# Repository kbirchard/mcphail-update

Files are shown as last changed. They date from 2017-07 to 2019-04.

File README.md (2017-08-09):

# McPhail-Trap

- [Insect Wingbeat Frequencies Table](research/Wingbeat_Frequencies.md)

### Boards

[**Main Board**](hardware/mcphail-main-board/) (incomplete)
- Estimated boards cost $35 for three ($11.68 each)
- Estimated parts cost $50
- Not including the one FONA board and the 2200mAH LiPo we have on hand
- Board is 3.18x2.24 inches (80.82x56.79mm)

[**Emitter Board**](hardware/mcphail-ir-emitter-board/)

- Boards cost $6.85 for three ($2.28 each)
- Parts cost $4.51 for one board
- Board is 2.71x0.51 inches (68.76x12.88mm)

[**Detector Board**](hardware/mcphail-photodiode-detector-board/)

- Boards cost $6.80 for three ($2.27 each)
- Parts cost $15.16 for one board
- Board is 2.71x0.51 inches (68.76x12.88mm)

[**Generic ATSAM21G18 Breakout Board**](https://github.com/wickerbox/Basic-Breakout-Boards/tree/master/atsamd21g18-breakout)

- Boards cost $13.85 for three ($4.62 each)
- Parts cost $14.51 for one board

[**STLink/V2 SWD Adapter Board**](https://github.com/wickerbox/Basic-Breakout-Boards/tree/master/atsamd21g18-jtag-stlinkv2-adapter)

- Boards cost $8.80 for three ($2.93 each)
- Parts cost $2.22 for one board

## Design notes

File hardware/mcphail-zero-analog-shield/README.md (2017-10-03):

# KiCad Template for Arduino Zero Shield 

This is a KiCad template to make it easy to include the Arduino Zero in a project. 

It comes with all the design rules to meet the 2-layer OSH Park specs and stackup.

- <a href="http://docs.oshpark.com/services/two-layer/">OSH Park Two Layer Specs</a>
- <a href="http://docs.oshpark.com/design-tools/kicad">OSH Park KiCad Help</a>
- <a href="https://www.arduino.cc/usa/arduino-zero">Arduino Zero Product Page</a>

### Instructions

1. Open KiCad.
1. Open Preferences > Configure Paths and note the value of 'KICAD_PTEMPLATES'.
1. <a href="https://github.com/wickerbox/wickerlib/blob/master/templates/arduino-zero-shield-template.zip?raw=true">Download the template zip</a> and extract into the location of 'KICAD_PTEMPLATES'.
1. In KiCad, open File > New Project > New Project from Template.
1. Select the location of your new project. The name of the folder will be the name of your project.
1. The templates with folders in the 'KICAD_PTEMPLATES' are listed under 'Portable Templates" tab.
1. Select the template and click 'OK'.
1. Your project now exists, so you can open EESchema and PCBNew and design as usual.

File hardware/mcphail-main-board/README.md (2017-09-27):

<!--- start title --->
# McPhail Trap Main Board v1.1
Collect, analyze, and report back environmental data.

- Updated: 12 Aug 2017
- Author: Jenner Hanni
- Website: http://wickerbox.net
- Company: Wickerbox Electronics
- License: CERN Open Hardware License v1.2
<!--- end title --->

This is an attempt to reproduce the work of identifying fruit flies from the following papers:

- 2017: [Automated Surveillance of Fruit Flies](http://www.mdpi.com/1424-8220/17/1/110/pdf)
- 2015: [Insect Biometrics: Optoacoustic Signal Processing and its Applications to Remote Monitoring](http://www.ncbi.nlm.nih.gov/pmc/articles/PMC4636391/)
- 2014: [The Electronic McPhail Trap](http://www.mdpi.com/1424-8220/14/12/22285) 
- 1979: [Optical Tachometer for Measurement of Wingbeat Frequency of Free-Flying Insects](http://jeb.biologists.org/content/82/1/377)

Parallels the European [ENTOMATIC](https://www.upf.edu/web/entomatic/) project.

## Hardware Version Notes

- v1.x, proof of concept, collect data on SD card and over USB
  Fona breakout board supports texting
- v2.x, switch to ARM MSP430 or other ADC-specific chip, collect data on SD card
- v3.x, integrate mesh net or other networking, possibly more sophisticated offboard analysis

\pagebreak

## Design Notes

### Physical Housing

Putting the electronics in acrylic separate from the insects so the ultrasonic isn't bothering them. An acrylic housing placed on top of the trap provides protection from the elements as well as protects the insects from any electronics noise. 

If all circuitry is on the board at the top, the IR emitters and photodiode detectors can be the only items in the trap with the insects and be connected by a minimum of cabling. 

The boards will all be 0.063" (1.6mm) thick FR-4 with purple solder mask over bare copper and an ENIG (gold) finish.

The tallest component on the board is C1 (330uF aluminum capacitor) at 0.5" tall.

**Board dimensions**

|Board|Dimensions|
|-----|---|
|Emitter Board|2.71x0.51 inches (68.76x12.88mm)|
|Detector Board|2.71x0.51 inches (68.76x12.88mm)|
|Main Board|3.18x2.24 inches (80.82x56.79mm)|

### Security and Connectivity Platforms for reference

- Particle
- Electric Imp

### v1 FONA808 GSM+GPS MODULE

- PS is power status. Check this after toggling KEY.
   Pin is low when module is off, and high when module is on.

- NS is network status. It pulses to signal current module status

- RST is hard reset to be used only when module is really stuck.

- RX/TX are pins capable of Software Serial. They are auto-baud so
   whatever baud you send "AT" after reset or boot is the baud rate
   the module will use. 

- RTS is hardware flow control. Optional.
   Turn it on in module if you want to use it. 

- RI is the ring indicator output. Use it as an interrupt. Default high.
   Pin will pulse low for 120ms when a call or SMS is received. 

The GPS is accessible on the Rx/Tx lines so you can query
using AT commands and get the values back. No additional
pins are necessary.

### Microcontroller

The reference papers call for a 14-bit ADC.

The Atmel AVR chips we initially considered (Atmega32u4, Atmega2560) had 10-bit ADC, which isn't enough. We chose the ATSAMD21G Cortex M0 with 12-bit ADC since it still can be programmed with a cheap programmer, doesn't require dedicated hardware, has built-in USB for programming and monitoring.

It is compatible with [adalink](https://github.com/adafruit/Adafruit_Adalink) and [avrdude](http://www.nongnu.org/avrdude/), which we already use for programming other boards. 

We added a $6 16-bit ADS1115 which receives on two differential or four single channels (we could use the four) and outputs the result over I2C.
 
Another possible solution would have been the $6 MSP432 or a similar chip, could pick up a $14 dev board as well. This is a TI chip that requires CodeComposer Studio, newest version is CCSv6. It's Linux-compatible and I have a Windows machine just in case it's not.

The downside of the MSP432 is the $45 additional programmer we need to buy, getting set up with a new dev environment, etc.  

### ADC and Noise Notes

The 2-layer board is routed using a split ground plane to separate the analog and digital signals. Care was taken to provide clear analog return paths but the A0, A1, and A2 signals right at the microcontroller are next to the I2C signals and this may end up as a source of noise. 

If noise is still an issue, we may need need a 4-layer board (which doubles board cost). It's unclear if ENTOMATIC are actually getting and using all 14 bits. 

Does 5V in the ENTOMATIC system vs 3.3V in our system make a difference? How?

We need to review the ENTOMATIC calculations -- seems like my back-of-envelope has 32ms, not 16ms as from their paper.

For power and noise control, we should turn off everything but the ADC when sampling. 

[Discussion of cheap 16-bit ADC](http://www.avrfreaks.net/forum/cheap-16-bit-adc)

### Software Approach

We collect the value from the ADC in a variable and poll it at the desired rate. 

Architecture could be a finite state machine.

Next step is to go through and set up all the registers first to initialize serial comms, ADC, RTC, low power mode, the interrupts, and so on. Then, make sure we have libraries for accessing the SD, etc. This will not be an Arduino project, but an AVR GCC project. Need to get the environment set up and document it so someone else can reproduce the work in the same way we did.

### RTC

The DS1307 real time clock is out of date and hard to find.

We used the MCP7940N with an external 32.768kHz external crystal, following the suggested PCB layout on [page 14 of the datasheet](http://ww1.microchip.com/downloads/en/DeviceDoc/20005010F.pdf).

There is a discussion of digital trimming on page 29 to mitigate temperature and intrinsic clock issues. We can figure out the values in this digital trimming register by testing the physical board and calculating the the trim value with the equations on paeg 30. 

### Temperature

Kyle put a thermometer in the trap and measured the temperature inside over two days in direct sunlight. Both times the internal temp was 10 F degrees higher than the ambient air temp. (110/100F first day @ 5pm, 108/98F second day @ noon). 

Prior to measuring, he left the thermometer in the trap for an hour, so that should be a reflection of what we'd see in the field. The combination of size and materials is keeping the temperature from getting much higher.

### Capacitors

Mostly ceramic capacitors were chosen for cost and size, with C0G/NP0 and X7R temperature coefficients. Aluminum electrolytic capacitors were chosen where ceramics were cost-prohibitive or where specifically indicated in datasheets.

The temperature coefficients: 

X7R means a capacitor is a temperature-stable (EIA Class 2) cap which only varies up to ±15% from -55°C to +125°C.  [ref](http://www.avx.com/products/ceramic-capacitors/surface-mount/x7r-dielectric/)

C0G/NP0 means a capacitor is temperature-compensating (EIA Class 1) which varies less than ±0.3% C from -55°C to +125°C. Capacitance drift or hysteresis is less than ±0.05%. [ref](http://www.avx.com/products/ceramic-capacitors/surface-mount/c0g-np0-dielectric/)

## Detector/Receiver Board

Interestingly, the receiver part number [TEMD5080X01](https://www.digikey.com/product-detail/en/vishay-semiconductor-opto-division/TEMD5080X01/TEMD5080X01CT-ND/2747443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) does not have the same package as in the photos of the McPhail trap. These are $1.31 each at 25 and the design calls for ten of them. 

They are good from -40C to 100C and are 5mm x 4.24mm. 

The board is 2.71x0.51 inches (68.76x12.88mm) and costs $7 from OSH Park for a set of three ($2.33 each). 

The stencil costs $5 from OSH Stencils.

## Emitter Board

The 940nm emitters are in the $2 range and the board will probably be the same size as the detector board. 

The difference in frequency range is due to the ENTOMATIC folks optimizing for response time over exact frequency match, to save on power. They also drove the LEDs at the edge of the board at higher current to make sure the infrared intensity was uniform no matter where the bug flew through the IR field. 
 
The diffuser needs more investigation.

The board is 2.71x0.51 inches (68.76x12.88mm) and costs $7 from OSH Park ($2.33 each).

The stencil costs $5 from OSH Stencils.

\pagebreak

## ATSAMD21G Pins

|ATSAMD21G Pin|Function|
|25|D7 CS|
|40|~RESET|
|14|SCLK|
|19|MOSI|
|15|MISO|
|13|D4 CS|
|33|D-|
|34|D+|
|26|FONA_NS|
|27|FONA_PS|
|28|FONA_RI|
|29|FONA_RTS|
|30|FONA_TX|
|31|FONA_RX|
|32|FONA_RST|
|41|~PG|
|20|RTC_MFP|
|21|SDA|
|22|SCL|
|37|EEPROM_ADD2|
|38|EEPROM_ADD1|
|39|EEPROM_ADD0|
|10|A2|
|11|A1|
|12|A0|
|45|SWCLK|
|46|SWDIO|

<!--- assy start --->
## Complete Assembly and Cost Information

Buying parts for a single main board is about $50. 

Buying parts for three main boardS (minimum OS Park order) is about $100.

The stencil from OSH Stencils costs $12.09. A tube of solder paste in the same package costs $14. 

Stencils are 3mil-thick polyamide (orange) film which is reusable.

Total cost for one complete stack (three boards): $143 ($143/stack)

Total cost for three complete stacks (nine boards): $223 ($74/stack)

Subsequent complete three stacks with parts: $200 ($67/stack)

|Item|Cost|
|----|----|
|Emitter Board PCB each (min qty=3)|$2.30|
|Emitter Parts qty=1|$4.50|
|Emitter Parts qty=3|$13.50|
|Emitter Stencil|$5|
|Detector Board PCB each (min qty=3)|$2.30|
|Detector Parts qty=1|$15|
|Detector Parts qty=3|$35|
|Detector Stencil|$5|
|Main Board PCB each (min qty=3)|$12|
|Main Board Parts qty=1|$50|
|Main Board Parts qty=3|$100|
|Main Board Stencil|$12|
|Leaded Solder|$14|

<!--- assy end --->
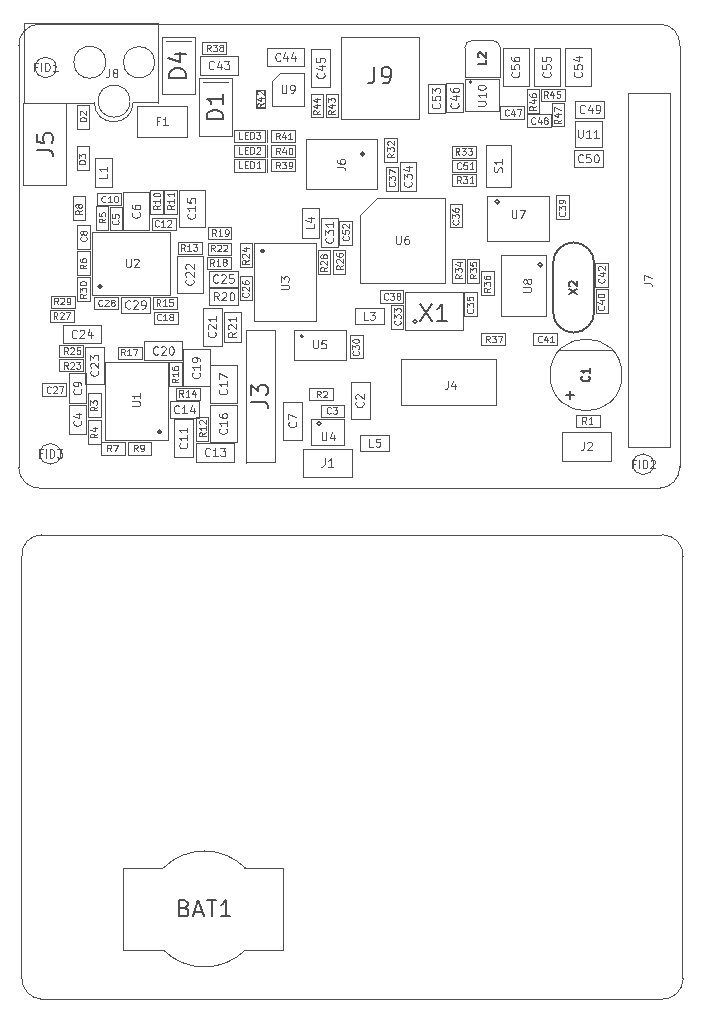
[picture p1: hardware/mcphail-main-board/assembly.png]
Assembly Diagram


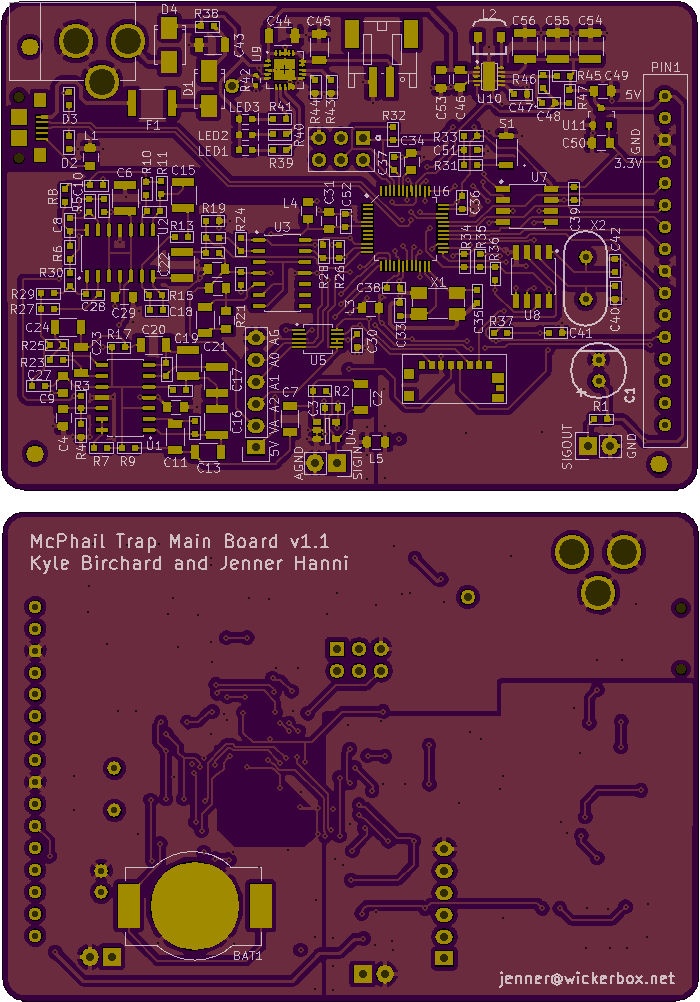
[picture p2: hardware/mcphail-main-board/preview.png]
Gerber Preview


\pagebreak

<!--- bom start --->
### Bill of Materials

|Ref|Qty|Description|Digikey PN|
|---|---|---|---|
|BAT1|1|CR1220 BATTERY HOLDER SMT FLATPIN|BK-916-CT-ND|
|C1|1|CAP ALUM 330UF 20% 16V RADIAL|732-8798-1-ND|
|C10|1|CAP CER 0.27UF 16V X7R 0603|490-6427-1-ND|
|C11 C13 C2 C7|4|CAP CER 1.5UF 25V X7R 1206|1276-6873-1-ND|
|C12 C28 C8|3|CAP CER 0.01UF 50V X7R 0603|490-1512-1-ND|
|C14 C29 C34 C4 C49-50 C9|7|CAP CER 1UF 25V X7R 0805|1276-1066-1-ND|
|C15 C54-C56 C6|5|CAP CER 22UF 25V X7R 1210|1276-3392-1-ND|
|C16 C17 C19 C22|4|CAP CER 2.2UF 25V X7R 0805|1276-2953-1-ND|
|C18|1|CAP CER 33PF 16V X7R 0603|478-6211-1-ND|
|C20-21 C23-24 C43-C45|7|CAP CER 4.7UF 50V X7R 1206|1276-2789-1-ND|
|C25 C31 C46 C53|4|CAP CER 10UF 16V X7R 0805|1276-2872-1-ND|
|C26 C30 C36-C39 C47 C51 C52|9|CAP CER 0.1UF 100V X7R 0603|490-3285-1-ND|
|C27|1|CAP CER 0.022UF 50V X7R 0603|1276-2004-1-ND|
|C3|1|CAP CER 0.22UF 25V X7R 0603|1276-1111-1-ND|
|C33 C35|2|CAP CER 22pF 50V NP0 0603|399-9031-1-ND|
|C40 C42|2|CAP CER 2PF 50V C0G/NP0 0603|490-10713-1-ND|
|C41|1|CAP CER 100PF 50V C0G/NP0 0603|490-1427-1-ND|
|C48|1|CAP CER 10PF 50V NP0 0603|1276-2154-1-ND|
|C5|1|CAP CER 0.039UF 50V X7R 0603|1276-2056-1-ND|
|D1 D4|2|DIODE SCHOTTKY 20V 1A SMA|SS12-E3/61TGICT-ND|
|D2 D3|2|VARISTOR ESD PROTECT USB|CG0603MLC-05ECT-ND|
|F1|1|RESETTABLE FUSE 500mA 15V MF-MSMF|MF-MSMF050-2CT-ND|
|J1 J2|2|HEADER MALE 2POS TH 1x02 0.1IN|952-2262-ND|
|J3|1|HEADER MALE 6POS KK100 0.1IN SHROUD TH|WM4204-ND |
|J4|1|CONN MICRO SD CARD PUSH-PULL|WM9731CT-ND|
|J5|1|USB MICRO-B RECEPTACLE 5PIN SMT R/A STUDS|609-4616-1-ND|
|J6|1|HEADER FEMALE 6POS 2x3 0.1IN|A30729CT-ND|
|J8|1|CONN PWR JACK 2.5X5.5MM HIGH CUR|PJ-202BH|
|J9|1|CONN HEADER PH SIDE 2POS 2MM|455-1719-ND|
|L1 L3-L5|4|FERRITE BEAD 30 OHM 0805 1LN|MH2029-300YCT-ND|
|L2|1|FIXED IND 1UH 3.3A 1226AS-H-1R0N|490-14149-1-ND|
|LED1-3|3|LED AMBER DIFFUSED 0603 SMD|475-2712-1-ND|
|R1|1|RES SMD 220 OHM 5% 1/10W 0603|311-220GRCT-ND|
|R10|1|RES SMD 732 OHM 1% 1/10W 0603|P732HCT-ND|
|R11 R8|2|RES SMD 1.43K OHM 1% 1/10W 0603|P1.43KHCT-ND|
|R12 R16 R23|3|RES SMD 2.26K OHM 1% 1/10W 0603|311-2.26KHRCT-ND|
|R13 R33 R36|3|RES SMD 10K OHM 1% 1/8W 0603|RNCP0603FTD10K0CT-ND|
|R14 R39-R41|4|RES SMD 470 OHM 5% 1/4W 0603|RHM470DCT-ND|
|R15|1|RES SMD 97.6K OHM 1% 1/10W 0603|P97.6KHCT-ND|
|R17|1|RES SMD 68 OHM 1% 1/10W 0603|P68.0HCT-ND|
|R18 R19|2|RES SMD 91K OHM 1% 1/10W 0603|P91.0KHCT-ND|
|R2|1|RES SMD 64.9K OHM 1% 1/10W 0603|P64.9KHCT-ND|
|R20 R21|2|RES SMD 220K OHM 5% 1/8W 0805|P220KACT-ND|
|R22 R26|2|RES SMD 2.2K OHM 5% 1/10W 0603|P2.2KGCT-ND|
|R24 R28|2|RES SMD 22K OHM 5% 1/10W 0603|P22KGCT-ND|
|R25 R29|2|RES SMD 4.32K OHM 1% 1/10W 0603|P4.32KHCT-ND|
|R27|1|RES SMD 2.94K OHM 1% 1/10W 0603|P2.94KHCT-ND|
|R3 R4 R44|3|RES SMD 100K OHM 1% 1/10W 0603|RMCF0603FG100KCT-ND|
|R30 R6|2|RES SMD 3.83K OHM 1% 1/10W 0603|P3.83KHCT-ND|
|R31|1|RES SMD 330 OHM 5% 1/10W 0603|311-330GRCT-ND|
|R32 R37|2|RES SMD 1K OHM 1% 1/10W 0603|1276-3484-1-ND|
|R34 R35 R43|3|RES SMD 2K OHM 1% 1/8W 0603|RNCP0603FTD2K00CT-ND|
|R38|1|RES SMD 0.0 OHM JUMPER 1/8W 0603|MCT0603-0.0-ZZCT-ND|
|R42|1|NTC THERMISTOR 10K OHM 1% 0402|445-2550-1-ND|
|R45 R47|2|RES SMD 1M OHM 5% 1/10W 0603|P1.0MGCT-ND|
|R46|1|RES SMD 111K OHM 5% 1/10W 0603|P110GCT-ND|
|R5|1|RES SMD 1.87K OHM 1% 1/10W 0603|P1.87KHCT-ND|
|R7|1|RES SMD 10 OHM 1% 1/10W 0603|P10.0HCT-ND|
|R9|1|RES SMD 470 OHM 5% 1/4W 0603|311-1.02KHRCT-ND|
|S1|1|SWITCH TACTILE SPST-NO 0.05A 12V|SW1020CT-ND|
|U1 U2|2|IC OPAMP QUAD GP RRO 1MHZ SOIC14|MCP6004T-I/SLCT-ND|
|U10|1|IC REG BUCK BOOST ADJ 2A 10WSON|296-30204-1-ND|
|U11|1|IC REG LDO 3.3V 0.25A MCP1703 SOT23A-3|MCP1703T-3302E/CBCT-ND|
|U3|1|IC OPAMP GP 3MHZ RRO 14SOIC|296-39258-1-ND|
|U4|1|IC OPAMP GP 1MHZ RRO MCP6001 SOT23-5|MCP6001T-I/OTCT-ND|
|U5|1|IC ADC 16BIT SPI 860SPS ADS1118 10MSOP|296-38850-1-ND|
|U6|1|IC MCU 32BIT 256KB FLASH ATSAMD21G 48TQFP|ATSAMD21G18A-AUTCT-ND|
|U7|1|IC EEPROM 1MBIT 400KHZ 24AA1025 SOIC8|24AA1025-I/SN-ND|
|U8|1|IC RTC CLK/CALENDAR I2C MCP7940N SOIC8|MCP7940N-E/SN-ND|
|U9|1|IC USB/AC BATT CHRGR MCP73871 20QFN|MCP73871T-2CCI/MLCT-ND|
|X1|1|CRYSTAL 16MHZ 30PPM 18pF 4SMD|CTX1206CT-ND|
|X2|1|CRYSTAL 32.768kHz 7pF CFS-20632768DZYB|300-8842-ND|

|Ref|Qty|Description|Adafruit PN|
|---|---|---|---|
|B1|1|Lithium Ion Polymer Battery - 3.7v 500mAh|1578|
|J7|1|ADAFRUIT FONA 808 + GPS|2542|

<!--- bom end --->

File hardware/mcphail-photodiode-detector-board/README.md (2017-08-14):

<!--- start title --->
# McPhail IR Detector Board v1.0
Part of the McPhail Trap Design

- Updated: 14 Aug 2017

- Author: Jenner Hanni
- Website: http://wickerbox.net
- Company: Wickerbox Electronics
- License: CERN Open Hardware License v1.2
<!--- end title --->

<!--- bom start --->
### Bill of Materials

|Ref|Qty|Description|Digikey PN|
|---|---|---|---|
|J1|1|HEADER MALE 2POS TH 1x02 0.1IN|952-2262-ND|
|LED1 LED10 LED2 LED3 LED4 LED5 LED6 LED7 LED8 LED9|10|PHOTODIODE IR 940NM SMD TEMD5110X01|751-1048-1-ND|

<!--- bom end --->
<!--- assy start --->

<!--- assy end --->
Assembly Diagram

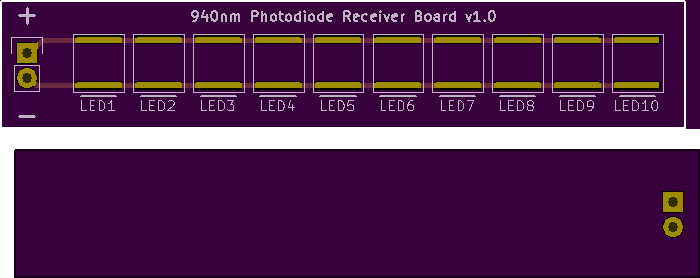
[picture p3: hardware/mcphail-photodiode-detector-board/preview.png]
Gerber Preview


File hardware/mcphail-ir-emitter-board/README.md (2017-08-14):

<!--- start title --->
# McPhail IR Emitter Board v1.0
Part of the McPhail Trap design

- Updated: 14 Aug 2017

- Author: Jenner Hanni
- Website: http://wickerbox.net
- Company: Wickerbox Electronics
- License: CERN Open Hardware License v1.2
<!--- end title --->

<!--- bom start --->
### Bill of Materials

|Ref|Qty|Description|Digikey PN|
|---|---|---|---|
|J1|1|HEADER MALE 2POS TH 1x02 0.1IN|952-2262-ND|

|Ref|Qty|Description|Mouser PN|
|---|---|---|---|
|LED1 LED10 LED2 LED3 LED4 LED5 LED6 LED7 LED8 LED9|10|LED IR 850NM TH SFH4356|720-SFH4356|

<!--- bom end --->
<!--- assy start --->
<!--- assy end --->
Assembly Diagram

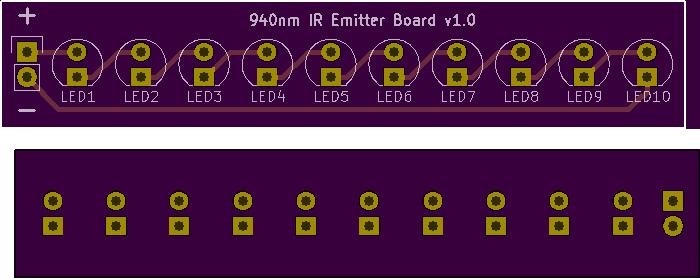
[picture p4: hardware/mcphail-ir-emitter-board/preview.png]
Gerber Preview


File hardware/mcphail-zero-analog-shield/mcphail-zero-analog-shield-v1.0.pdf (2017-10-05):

McPhail Zero Analog Shield 1.0 | Wickerbox Electronics

# McPhail Zero Analog Shield v1.0

Arduino Zero shield for the analog signal processing McPhail circuitry

Bill of Materials

Ref | Qty | Description | Digikey PN
C1 | 1 | CAP ALUM 330UF 20% 16V RADIAL | 732-8798-1-ND
C10 | 1 | CAP CER 0.27UF 16V X7R 0603 | 490-6427-1-ND
C11 C13 C2 C7 | 4 | CAP CER 1.5UF 25V X7R 1206 | 1276-6873-1-ND
C12 C28 C8 | 3 | CAP CER 0.01UF 50V X7R 0603 | 490-1512-1-ND
C14 C29 C4 C9 | 4 | CAP CER 1UF 25V X7R 0805 | 1276-1066-1-ND
C15 C6 | 2 | CAP CER 22UF 25V X7R 1210 | 1276-3392-1-ND
C16 C17 C19 C22 | 4 | CAP CER 2.2UF 25V X7R 0805 | 1276-2953-1-ND
C18 | 1 | CAP CER 33PF 16V X7R 0603 | 478-6211-1-ND
C20 C21 C23 C24 | 4 | CAP CER 4.7UF 50V X7R 1206 | 1276-2789-1-ND
C25 | 1 | CAP CER 10UF 16V X7R 0805 | 1276-2872-1-ND
C26 | 1 | CAP CER 0.1UF 100V X7R 0603 | 490-3285-1-ND
C27 | 1 | CAP CER 0.022UF 50V X7R 0603 | 1276-2004-1-ND
C3 | 1 | CAP CER 0.22UF 25V X7R 0603 | 1276-1111-1-ND
C5 | 1 | CAP CER 0.039UF 50V X7R 0603 | 1276-2056-1-ND
J1 J2 | 2 | CONN TERM SCREW GREEN 2.54MM 2POS TH | ED10561-ND
J3 | 1 | HEADER MALE 1POS | 952-1902-ND
LED1 | 1 | LED AMBER DIFFUSED 0603 SMD | 475-2712-1-ND
R1 R32 | 2 | RES SMD 220 OHM 5% 1/10W 0603 | 311-220GRCT-ND
R10 | 1 | RES SMD 732 OHM 1% 1/10W 0603 | P732HCT-ND
R11 R8 | 2 | RES SMD 1.43K OHM 1% 1/10W 0603 | P1.43KHCT-ND
R12 R16 R23 | 3 | RES SMD 2.26K OHM 1% 1/10W 0603 | 311-2.26KHRCT-ND
R13 | 1 | RES SMD 10K OHM 1% 1/8W 0603 | RNCP0603FTD10K0CT-ND
R14 | 1 | RES SMD 470 OHM 5% 1/4W 0603 | RHM470DCT-ND
R15 | 1 | RES SMD 97.6K OHM 1% 1/10W 0603 | P97.6KHCT-ND
R17 | 1 | RES SMD 68 OHM 1% 1/10W 0603 | P68.0HCT-ND
R18 R19 | 2 | RES SMD 91K OHM 1% 1/10W 0603 | P91.0KHCT-ND
R2 | 1 | RES SMD 64.9K OHM 1% 1/10W 0603 | P64.9KHCT-ND
R20 R21 | 2 | RES SMD 220K OHM 5% 1/8W 0805 | P220KACT-ND
R22 R26 | 2 | RES SMD 2.2K OHM 5% 1/10W 0603 | P2.2KGCT-ND
R24 R28 | 2 | RES SMD 22K OHM 5% 1/10W 0603 | P22KGCT-ND
R25 R29 | 2 | RES SMD 4.32K OHM 1% 1/10W 0603 | P4.32KHCT-ND
R27 | 1 | RES SMD 2.94K OHM 1% 1/10W 0603 | P2.94KHCT-ND
R3 R4 | 2 | RES SMD 100K OHM 1% 1/10W 0603 | RMCF0603FG100KCT-ND
R30 R6 | 2 | RES SMD 3.83K OHM 1% 1/10W 0603 | P3.83KHCT-ND
R31 | 1 | RES SMD 0.0 OHM JUMPER 1/8W 0603 | MCT0603-0.0-ZZCT-ND
R5 | 1 | RES SMD 1.87K OHM 1% 1/10W 0603 | P1.87KHCT-ND
R7 | 1 | RES SMD 10 OHM 1% 1/10W 0603 | P10.0HCT-ND
R9 | 1 | RES SMD 470 OHM 5% 1/4W 0603 | 311-1.02KHRCT-ND
S1 | 1 | SWITCH TACTILE SPST-NO 0.05A 12V | SW1020CT-ND
U1 U2 | 2 | IC OPAMP QUAD GP RRO 1MHZ SOIC14 | MCP6004T-I/SLCT-ND
U3 | 1 | IC OPAMP GP 3MHZ RRO 14SOIC | 296-39258-1-ND
U4 | 1 | IC OPAMP GP 1MHZ RRO MCP6001 SOT23-5 | MCP6001T-I/OTCT-ND
October 4, 2017 | http://wickerbox.net/

Ref | Qty | Description | Adafruit PN
U5 | 1 | ARDUINO ZERO SHIELD | 2843

Assembly Info for Quoting

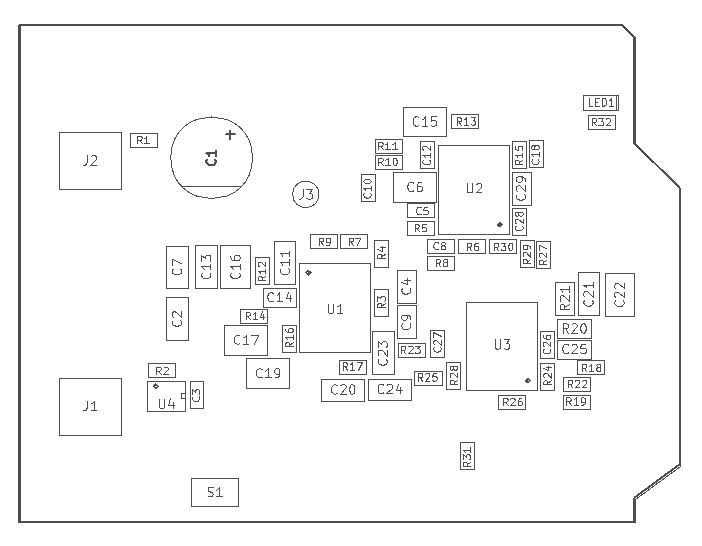
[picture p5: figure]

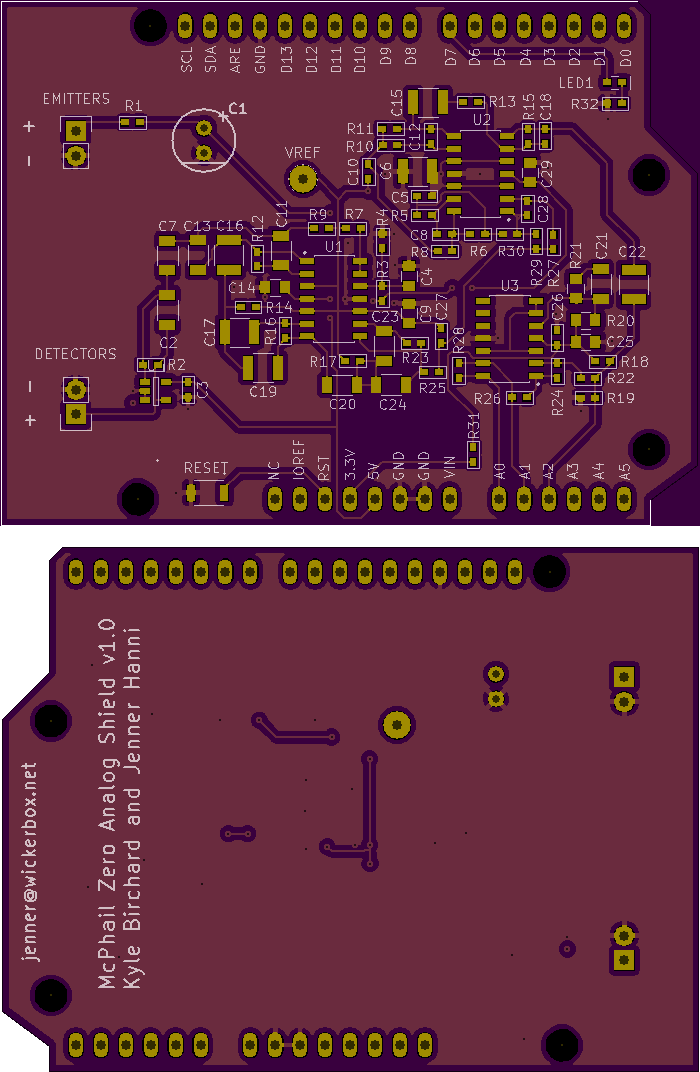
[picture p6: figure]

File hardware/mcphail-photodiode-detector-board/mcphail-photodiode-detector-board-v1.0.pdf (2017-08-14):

McPhail IR Detector Board 1.0 | Wickerbox Electronics

# McPhail IR Detector Board v1.0

Part of the McPhail Trap Design

Bill of Materials

Ref | Qty | Description

Digikey
PN
J1 | 1 | HEADER MALE 2POS TH 1x02 0.1IN
952-2262-
ND

LED1
LED10
LED2
LED3
LED4
LED5
LED6
LED7
LED8
LED9

10 PHOTODIODE IR 940NM SMD TEMD5110X01
751-1048-
1-ND

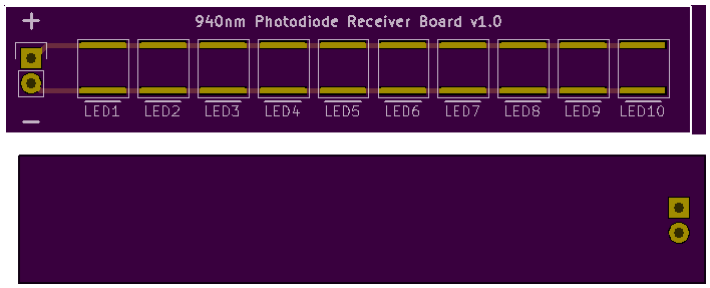
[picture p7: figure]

August 14, 2017 | http://wickerbox.net/

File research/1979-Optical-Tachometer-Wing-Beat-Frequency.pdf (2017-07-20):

J. exp. Biol. (1979), 8a, 377~378 Kith 2 figures

inted in Great Britain

377

AN OPTICAL TACHOMETER FOR MEASUREMENT OF THE WING-BEAT FREQUENCY OF FREE-FLYING INSECTS

BY D. M. UNWIN AND C. P. ELLINGTON Department of Zoology, University of Cambridge, Downing Street, Cambridge CB2 ^EJ

(Received 7 February 1979)

The wing-beat frequency of flying insects has generally been measured by acoustic methods, but even with modern condenser microphones and frequency-selective amplification the signal available from smaller insects may be inadequate. A microphone had to be placed within 1 cm of the midge Smittia atenima (Mg.) to produce a satisfactory signal and no signals could be obtained from Thrips sp. (Thysanoptera). Acoustic recordings of flying insects in the laboratory may also be degraded by the excited resonant frequencies of the cage material. The optical tachometer uses the minute changes in the intensity of ambient light reflected from an insect's beating wings to produce an amplified electrical output at the wing-beat frequency, producing an adequate signal from a very much greater range than would be obtained by acoustic methods. With this device Smittia aterrima could be measured at a distance of 1 m, Drosophila melanogaster Mg, at 1-2 m, and larger insects from a much greater range: Calliphora vicina (R-D.) 7 m, and Bombus sp. 10 m. No difficulty is found when making measurements through the sides of transparent flight cages. The sensitivity of the device seems sufficient for recording Thrips, although this has not yet been tested.
The circuit diagram of the tachometer is shown in Fig. 1. The signal from a silicon photo-diode passes through a two-stage selective amplifier with a maximum gain of 10000. The low-frequency gain is deliberately limited by the inter-stage coupling

Fig. 1. Circuit diagram of the optical tachometer. Resistances are in ohms and capacitances in microfarads unless stated.

378 | D. M. UNWIN AND C. P. ELLINGTON

Lens

o
Amplifier
circuit board

Photo-diode

o

0

o

Output
socket

Fig. 2. Layout of the tachometer, which is built in a moulded polystyrene case, 120x65 x
40 mm (R. S. Components Ltd., ref. 509-579).
networks so that large-amplitude signals due to movement of the sensor relative to the background do not block the amplifier. The output of the amplifier is — 3 dB at 500 Hz and — 20 dB at 50 Hz relative to the output at 1 kHz. High-impedence headphones may be connected directly to the output.
The layout of the tachometer is shown in Fig. 2. The optical system consists of a large aperture lens of short focal length; the prototype incorporates a lens of 7 mm focal length and an aperture of about f/o-5 (the top part of the condenser lens from a Watson monocular microscope). The angle of acceptance of the optical system is 6°, which is sufficiently broad to enable insects to be located without difficulty by pointing the device in the approximate direction and monitoring the output with headphones. The use of lenses of longer focal length will produce a larger output but make the location of the insect more difficult. The photo-diode is mounted on the printed-circuit board that carries the amplifier, and the lens is positioned so that an object at 1 m is in focus at the target of the photo-diode. It is essential that the insect is illuminated by daylight or by lamps powered from a smooth direct current supply. The use of artificial lighting powered from an alternating supply results in so large an output at 100 Hz that the signal is masked completely.

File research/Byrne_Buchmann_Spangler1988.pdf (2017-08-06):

J. exp. Biol. 135, 9-23 (1988) | 9
Printed in Great Britain © The Company of Biologists Limited 1988

RELATIONSHIP BETWEEN WING LOADING, WINGBEAT FREQUENCY AND BODY MASS IN HOMOPTEROUS INSECTS

BY DAVID N. BYRNE
Department of Entomology, University of Arizona, Tucson, AZ 85721, USA STEPHEN L. BUCHMANN AND HAYWARD G. SPANGLER USDA-ARS Carl Hayden Bee Research Center, 2000 E. Allen Rd, Tucson, AZ 85719, USA

Accepted 17 September 1987

SUMMARY
Several biophysical properties of members of Aleyrodidae and Aphididae were examined in order to explore how homopterous insects fly. Five species of aphids were found to weigh significantly more than five whitefly species (range M4-7-02xl0~⁴

g for aphids vs 3-3-8-Ox 10~⁵ g for whiteflies) and to have significantly larger wing surface areas (range 0-0103-0-1106 cm² vs 0-0096-
00264cm²
). As a consequence whiteflies and aphids can be partitioned into two groups with respect to wing loading (range 0-00633-0-01412 gcm~² for aphids,
1-74-5-23X 10~³

gcm~²
for whiteflies). Members of the two families are also separated in terms of wingbeat frequency (range 81-l-123-4Hz for aphids, 165-6—224-2 Hz for whiteflies). Since our animals were much smaller than any insects examined previously for these parameters, values were compared with the same parameters for 149 insect species recorded in the literature. Using these data, we found wingbeat frequency to be significantly correlated with wing loading only in insects weighing more than 0-03 g. Larger insects seem to employ a strategy similar to other flying animals, by compensating for high wing loading with higher wingbeat frequencies. The lack of correlation for these two parameters in insects weighing less than 0-03 g probably results from the use of different flying strategies. These include employment of a clap and fling mechanism and the possession by some of exceedingly low wing loading. Also, small insects may have reduced settling velocities because they possess high drag coefficients. Previous studies which failed to establish a relationship between wing loading and wingbeat frequency in larger insects may have considered too few subjects or too great a range of body masses. The mass range is important because smaller insects which employ increased wingbeat frequency must use rates exponentially higher than those of larger insects utilizing the same strategy.

INTRODUCTION
Whiteflies do not as readily engage in vertical flight as other homopterous insects, such as aphids. This was discovered when Byrne, von Bretzel & Hoffman (1986) Key words: wing loading, wingbeat frequency, body mass, insects.

10 | D. N. BYRNE, S. L. BUCHMANN AND H. G. SPANGLER
placed traps at heights of 0—15 cm, 50—65 cm and 100—115 cm to catch sweetpotato whiteflies, Bemisia tabaci (Gennadius) and bandedwinged whiteflies, Trialeurodes abutilonea (Haldeman). During two growing seasons, 81% of the whiteflies were captured in the lowest traps, 12 % in the midlevel traps and 7 % in the highest traps. In a previous survey of alate aphids, Broadbent (1948) placed traps at heights of 5-36cm, 81-118cm and 157-188 cm. Over a 24-week period in his study, 14% of the aphids were caught in the lowest traps, 34 % in the midlevel traps and 52 % in the highest traps. These findings led us to examine how members of these two homopterous families might differ in their flight mechanisms, particularly with regard to wing loading and wingbeat frequency.

MATERIALS AND METHODS
The members of Aleyrodidae we examined were Aleurothrixus floccosus (Maskell), Bemisia tabaci, Dialeurodes citri (Ashmead), Trialeurodes abutilonea and Trialeurodes vaporariorum (Westwood). Members of Aphididae were Aphis fabae Scopoli, Aphisgossypii Glover, Aphis nerii Fonscolombe, Acyrthosiphon kondoi Shinji and Myzus persicae (Sulzer). All species were reared in greenhouses or on research plots at agricultural experimental stations maintained by the University of Arizona at Tucson and the University of California at Riverside. Italian honeybees, Apis mellifera L., from the USDA Carl Hayden Bee Research Center in Tucson, AZ, were also measured to compare our data with those in the literature.
Using a Datamate 100 Microfiche Reader, we determined wing surface areas for all species by projecting images of their wings onto transparent acetate sheets. Templates of images were cut from the sheets and weighed. A linear regression equation, relating template masses of known dimensions to their surface areas, was developed. Surface areas for wings were calculated by inserting the masses of their templates into this equation. Wing lengths were determined using an ocular micrometer in a dissecting microscope. Fresh whole masses were obtained by immobilizing the insects with carbon dioxide and weighing them with either a Cahn 25 or Cahn 29 Microbalance.
Wing loadings for these insects were calculated in gcm~²
by dividing mass by total
wing surface area. Total wing surface area was determined by summing twice the mean of the forewing area with twice the mean of the hindwing area.
Wingbeat frequencies were obtained with an optical tachometer, in a manner similar to that of Unvvin & Ellington (1979), and a Nicolet 206 digital oscilloscope. Insects were allowed to fly freely inside a covered greenhouse at 24±3°C. A wingbeat frequency was obtained for the sexually dimorphic D. citri but, since separate values could not be determined for the two sexes, this species was not considered in statistical comparisons of wingbeat frequencies.
The number of animals measured for each variable was determined by examining coefficients of variation as data sets were accumulated. The data were tested for normality using the Shapiro-Wilk statistic (Shapiro & Wilk, 1965). If samples were normally distributed, a i-test or Student F-test was used to compare sample means.

Insect wing loading and wingbeat frequency | 11

Otherwise, Ansari-Bradley (Ansari & Bradley, 1960) and Mann-Whitney (Mann & Whitney, 1947) nonparametric tests for equality of dispersion were used. Statistical analysis was done using the RS/l software system on a Digital Equipment Corporation Professional 350 microcomputer.
To compare aphids and whiteflies with other insects, we compiled data from the literature for 149 insect species with known values for wing loading, wingbeat frequency and wing surface area. Certain data were corrected to match our selected format for presentation. Only species with known values for all three variables were used.

RESULTS
Morphometrics for our homopterans appear in Table 1 as numbers 1 — 11. Table 1 also provides rankings of the animals measured in this study with respect to values in the literature for the same parameters. These are shown parenthetically in the columns for mass, wing area, wing loading and wingbeat frequency. For example,
B. tabaci wingbeat frequency ranked as the 134th highest of 158 recorded frequencies.
The data for the honeybees we measured appear as number 54 in Table 1. Our results compare favourably with those reported earlier by Magnan (1934) and Sotavalta (1952) which are shown as numbers 49 and 50.
All wing area and wing length measurements had low coefficients of variation (c.v.), <15%, indicating that 20 individuals would constitute an adequate sample size. Wingbeat frequencies also had low c.v. (<10%), and only 10 individuals were measured. Body masses were more variable, and 40 individuals were weighed (c.v. <40%). Unlike the other insects we measured, D. citri males and females were significantly different in terms of the two important flight-associated parameters: body mass and wing surface area (P<0-05). Consequently, all values for the measured variables, with the exception of wingbeat frequency (not given), are listed separately for D. citri males and females.

Wing surface areas and lengths
The forewing surface areas of the measured animals were significantly larger than those of their hindwings (T³
< 0• 01). Generally, aphids had significantly larger forewings and hindwings than whiteflies, although Ap. gossypii was an exception (P< 0-01). Aphid forewings and hindwings were also longer than the forewings and hindwings of whiteflies (/><0-01) (Table 2).

Bodv masses
Body masses are given in Table 1. Aphids were significantly larger than whiteflies; ranges were M4-7-02xl0~⁴

g for aphids and 3-3-8-0xl0~⁵ g for whiteflies
(P<0⁻
01). Almost all body masses of the measured animals were significantly different from one another (P<0-01). The exceptions were two whiteflies, D. citri males and T. vaporariorum (/* > 0 • 01).

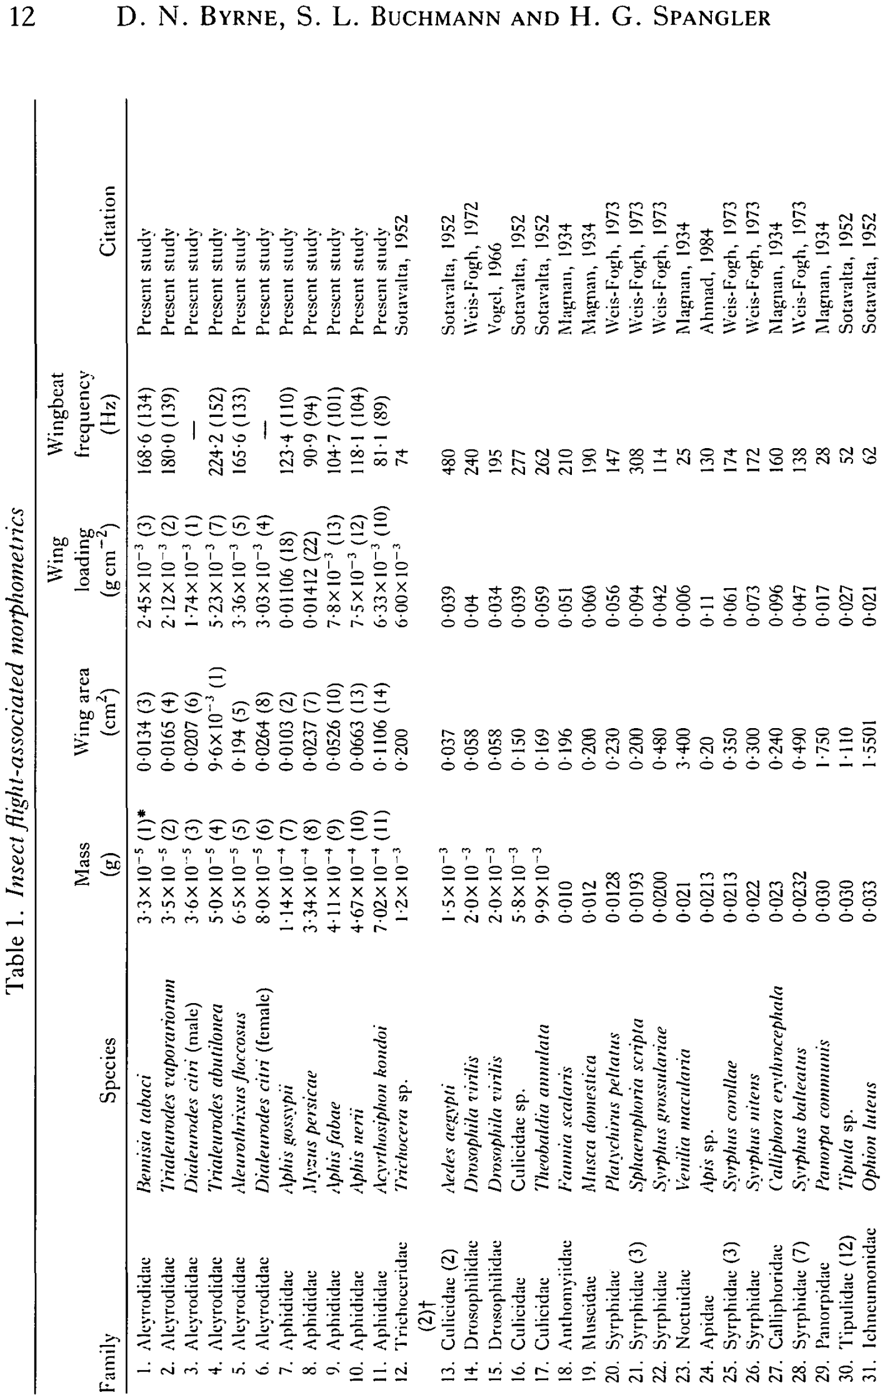
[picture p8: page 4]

Table 1. Insect flight-associated morphometrics

Family

1. Alcyrodidac
2. Alcyrodiclae
3. Alcyrodidae
4. Alcyrodidac
5. Alcyrodidac
6. Alcyrodidae
7. Aphididac
8. Aphididac
9. Aphididac
10. Aphididac
11. Aphididac
12. Trichoceridae

(2)t

13. Culicidac (2)
14. Drosophilidae
15. Drosophilidae
16. Culicidac
17. Culicidac
18. Anthomyiidac
19. Muscidae
20. Syrphidac
21. Syrphidac (3)
22. Syrphidac
23. Noctuidac
24. Apidac
25. Syrphidac (3)
26. Syrphidac
27. Calliphoridac
28. Syrphidac (7)
29. Panorpidae
30. Tipulidac(12)
31. Ichncumonidae

Species
Beniisia labaci

Trialeumdes vaporariorum
Dtaleumdes citn (male)
Trialeumdes abutiloiiea
Aleiimlhrixus jloccosus

Dialeumdes citri (female)

Aphis gossypii

Mysus persicae
Aphis fabae
Aphis nerii

Acyrthosiphon kondot

Triclwcera sp.
Aedes aegvpti

Dmsophila viritis

Dmsophila znnlis
Culicidac sp.

Theobaldia anniilata

h'annia scalans

Musca domestica

Plalychirus peltalus

Sphaerophoria scripla
Syrphus grvssulariae
Venilia macularia

Apis sp.

Syrphus comllae
Syrphus nilens

C 'alliphora eiylhmcephala

Syrphus ballealus

Panorpa communis

Tipula sp.

Ophion luteus

Mass
(g)
3-3X10"

5
3-5X10"

5
3-6X10

5
5-0xl0"

s
6-5X10"

5
8-OxlO"

5
1-HxlO"

4
3-34X10"

4
4-11 xlO"

4
4-67x10"*
7-0?y IO~

4
1-5X10"

3
2-OxlO"

3
2-OxlO"

3
5-8xlO~

3
9-9xlO~

3

0-010

0-012

0-0128

0-0193
0-0200
0-021

0-0213
00213
0022

0-023

0-0232
0-030

0-030

0-033

(1)*
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
(10)

(11)

Wing area

(cm

2

)
0-0134 (3)

0-0165 (4)

00207 (6)
9-6X10""

3

(1)
0-194(5)

0-0264 (8)

00103 (2)

0-0237 (7)

00526 (10)

00663 (13)

0-1106 (14)

0-200

0-037

0-058

0-058
0-150
0-169
0196

0-200

0-230

0-200

0-480

3-400
0-20

0-350

0-300

0-240

0-490
1-750

1110

1-5501

Wing

loading
(gem"

2

)
2-45X10"

3

(3)
2-12X10"

3

(2)
1-74X10"

3

(1)
5-23xlO"

3

(7)
3-36X10"

3

(5)

3-03xl0"

3

(4)
0-01106(18)

0-01412 (22)
7-8X10"

3

(13)

7-5X10"

3

(12)

6-33x10

3

(10)

6-OOxlO"

3

0-039
0-04

0-034
0-039

0-059
0-051

0-060

0-056
0-094

0-042
0-006
0-11

0-061

0-073
0096

0-047
0-017

0-027
0-021

Wingbeat

frequency
(Hz) '
168-6(134)

180-0 (139)

—

224-2(152)

165-6 (133)

—

123-4 (110)
90-9 (94)

104-7 (101)

118-1 (104)
81-1 (89)

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
Citation

Present studv

Present studv

Present studv
Present study

Present study

Present study
Present study

Present study

Present study

Present study

Sotavalta, 1952

Sotavalta, 1952

Wcis-Fogh, 1972

Vogcl, 1966

Sotavalta, 1952

Sotavalta, 1952
Magnan, 1934

Magnan, 1934

Wcis-Fogh, 1973

Wcis-Fogh, 1973

Weis-Fogh, 1973
Magnan, 1934
Ahmad, 1984

Wcis-Fogh, 1973

Wcis-Fogh, 1973
Magnan, 1934

Wcis-Fogh, 1973
Magnan, 1934

Sotavalta, 1952

Sotavalta, 1952

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
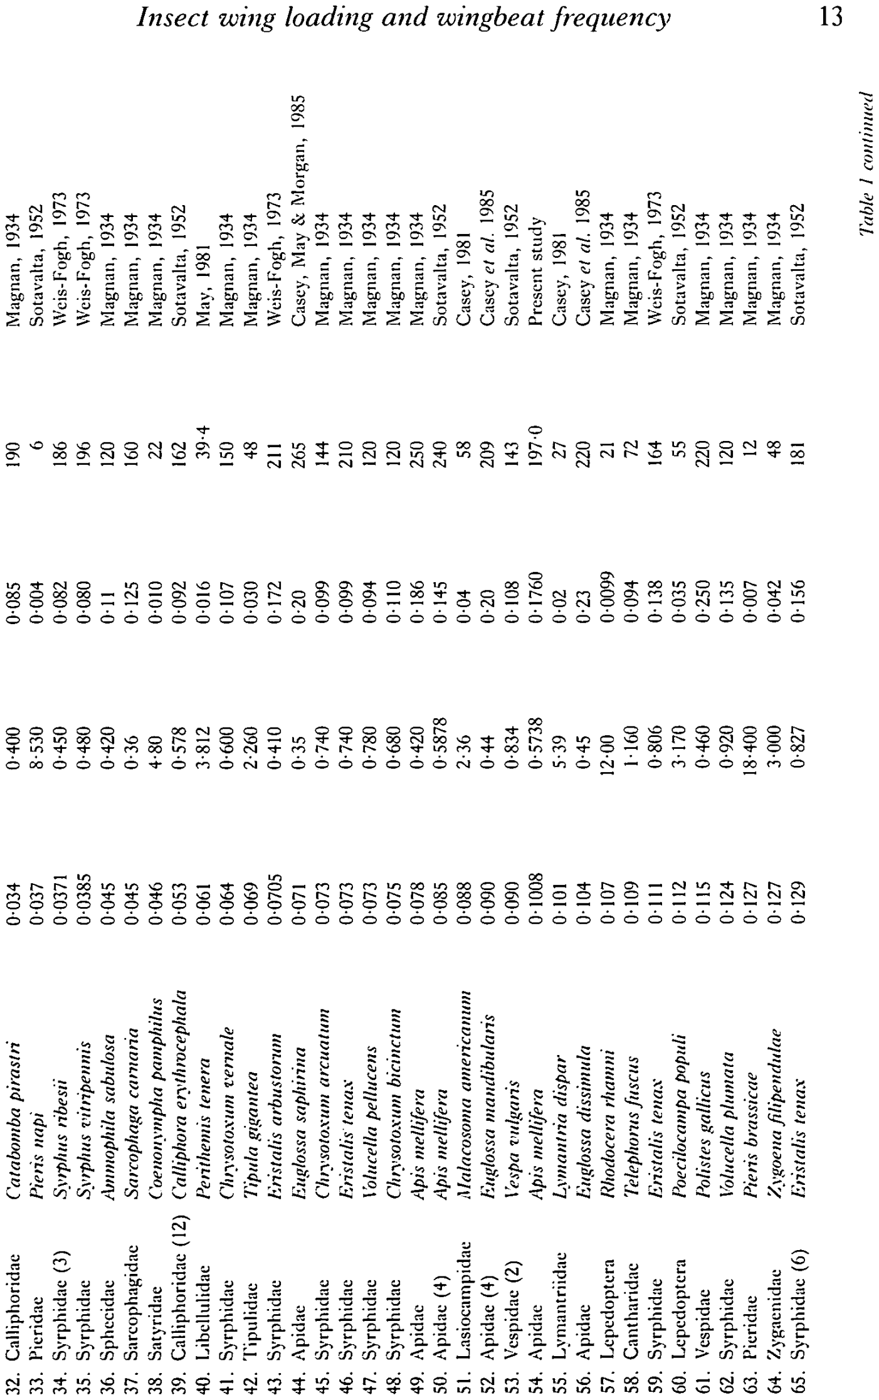
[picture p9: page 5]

32

. Calliphorida

c

33

. Pierida

c

34

. Syrphida

c (3

)

35

. Syrphida

c

36

. Sphccida

c

37

. Sarcophagida

c

38

. Satyrida

e

39

. Calliphorida

c (12

)

40

. Libcllulida

c
41. Syrphida

c

42

. Tipulida

c

43

. Syrphida

c

44

. Apida

c

45

. Syrphida

c

46

. Syrphida

c

47

. Syrphida

c

48

. Syrphida

c

49

. Apida

c

50

. Apida

c (4

)

51. Lasiocampida

c

52

. Apida

c (4

)

53

. Vcspida

e (2

)

54

. Apida

c

55

. Lymantriida

c

56

. Apida

c

57

. Lcpedoptcr

a

58

. Cantharida

c

59

. Syrphida

c

60

. Lcpedoptcr

a

61. Vcspida

e

62

. Syrphida

c

63

. Picrida

c

64

. Zygacnida

c

65

. Syrphida

c (6

)

Catabomba piraslri

Pieris napi

Syrplms ribesii

Syrphus vitripennis

Ammophila sabulosa

Sarcophaga carnaria

Coenonympha pamphilus

Calliphora etythivcephala

Perithemis tenera

Chrysotoxum veniale

Tipula gigantea

Eristalis arbustomm
Euglossa saphirina

Chrysotoxum arcuatum

## Eristalistenax \ bhicella pellucens

Chrysotoxum bicinctum

Apis mellifera

Apis mellifera

Malacosoma americanum
Euglossa mandibularis

\'espa z'ulgans
Apis mellifera

Lymantria clispar

Euglossa dissimula
Rhodocera rhamni
Telephorus fuscus
Eristalis tenax

Poecilocampa populi

Polistes gallicus

Volucella plumata
Pieris brassicae

Xygoena filipendulae

Eristalis tenax

0-03

4
0-03

7

0-037

1
0-038

5

0-04

5
0-04

5
0-04

6
0-05

3
0-06

1
0-06

4
0-06

9
0-070

5

0-07

1
0-07

3
0-07

3
0-07

3
0-07

5
0-07

8
0-08

5
0-08

8
0-09

0
0-09

0
0-100

8

010

1
0-10

4
0-10

7
0-10

9
011

1
0-11

2
0-11

5
0-12

4
0-12

7
0-12

7
0-12

9

0-40

0
8-53

0
0-45

0
0-48

0
0-42

0

0-3

6
4-8

0

0-57

8
3-81

2
0-60

0
2-26

0
0-41

0

0-3

5

0-74

0
0-74

0
0-78

0
0-68

0
0-42

0
0-587

8

2-3

6
0-4

4

0-83

4
0-573

8

5-3

9
0-4

5
12-0

0

1-160
0-80

6
3-17

0
0-46

0
0-92

0
18-40

0
3-00

0
0-82

7

0-08

5
0-00

4
0-08

2
0-08

0

0-1

1
012

5
0-01

0
0-09

2
0-01

6
0-10

7
0-03

0
0-17

2

0-2

0

0-09

9
0-09

9
0-09

4
0-11

0
0-18

6
0-14

5

0-0

4
0-2

0

0-10

8
0-176

0

0-0

2
0-2

3

0-009

9

0-09

4
0-13

8
0-03

5
0-25

0
0-13

5
0-00

7
0-04

2
0-15

6

1906
18

6
19

6
120

16022

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
02172

16455
22

0

1201248
18

1

Magnan

, 193

4

Sotavalta

, 195

2

Wcis-Fogh

, 197

3

Wcis-Fogh

, 197

3

Magnan

, 193

4

Magnan

, 193

4

Magnan

, 193

4

Sotavalta

, 195

2

May

, 198

1
Magnan

, 193

4

Magnan

, 193

4
Wcis-Fogh

, 197

3

Casey

, Ma

y & Morgan

, 198

5

Magnan

, 193

4

Magnan

, 193

4

Magnan

, 193

4

Magnan

, 193

4

Magnan

, 193

4

Sotavalta

, 195

2

Casey

, 198

1

Case

y et al. 198

5

Sotavalta

, 195

2

Presen

t stud

y

Casey

, 198

1

Case

y et al. 198

5

Magnan

, 193

4

Magnan

, 193

4
Weis-Fogh

, 197

3

Sotavalta

, 195

2

Magnan

, 193

4

Magnan

, 193

4

Magnan

, 193

4

Magnan

, 193

4

Sotavalta

, 195

2

Table 1 continued

f

t

P-s

o

"

S

3a. 3' aa. §i

*-*>

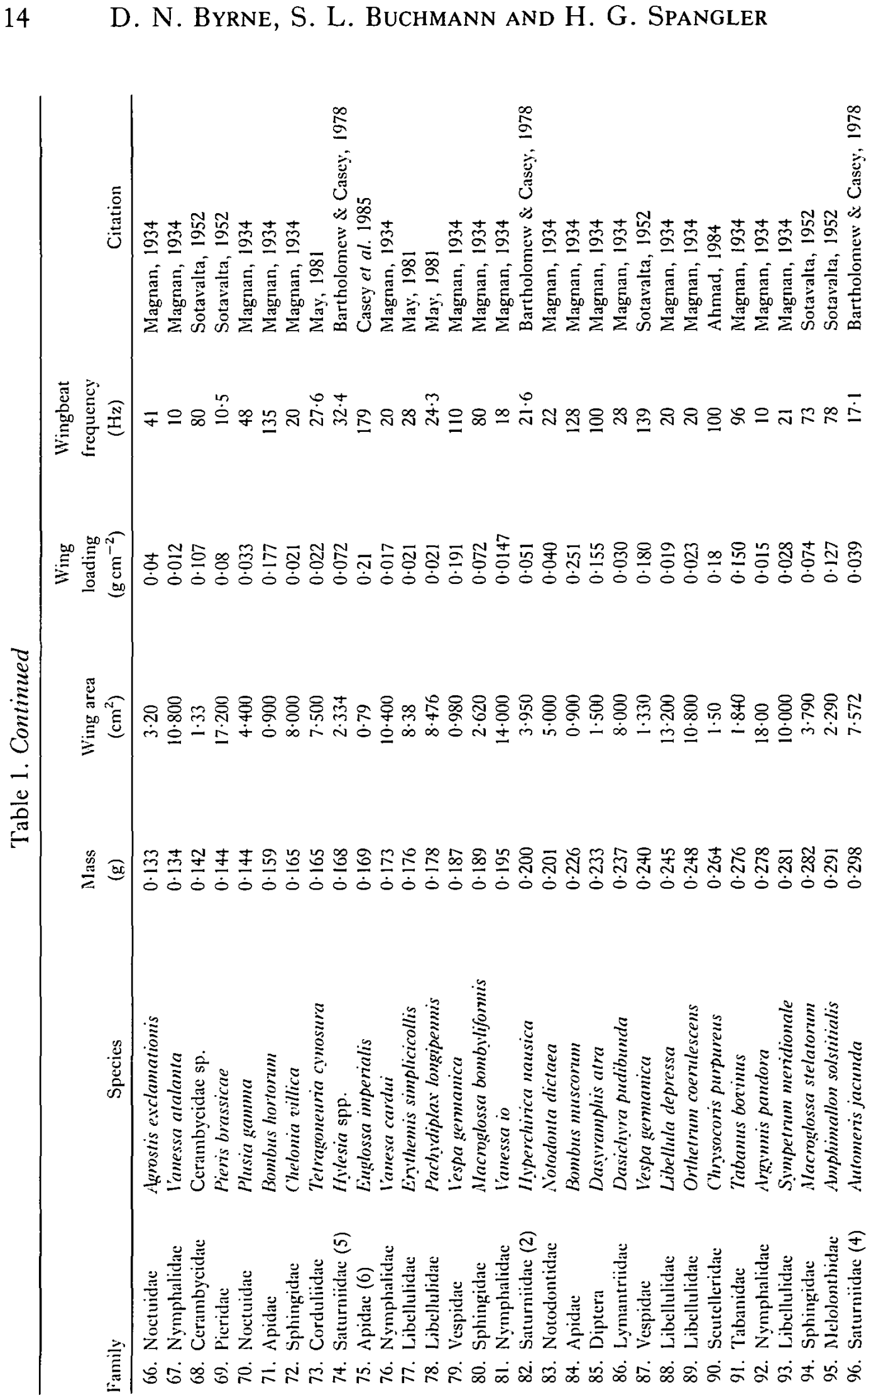
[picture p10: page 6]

Table 1. Continued

Family

66. Noctuidac
67. Nymphalidac
68. Ccrambycidac
69. Picridac
70. Noctuidac
71. Apidac
72. Sphingidae
73. Corduliidae
74. Saturniidac (5)
75. Apidac (6)
76. Nymphalidac
77. Libcllulidae
78. Libcllulidac
79. Vcspidac
80. Sphingidae
81. Nymphalidac
82. Saturniidac (2)
83. Notodontidae
84. Apidac
85. Diptcra
86. Lymantriidau
87. Vcspidac
88. Libcllulidac
89. Libcllulidac
90. Scutcllcridac
91. Tabanidac
92. Nymphalidac
93. Libcllulidac
94. Sphingidae
95. Mclolonthidac
96. Saturniidac (4)

Species

j\gmstis exclaniationis

Vanessa alalanla

Ccrambycidac sp.
Pieris brassicae
Pliisia gamma

Bombtts liortonim
Chelonia villica

Tetragoneiiria cynosura

Ilylesia spp.

Englossa imperialis

Vatiesci cardui

lirythemis simplicicollis

Pachydiplax longipenms

\ espa gennanica

Macroglossa bonibylifoniiis

Vanessa io

Ilyperchirica nausica
Sotodonta dictaea

Hombus nuisconim
Dasyramphis atra

Dasichyra pudibunda

Vespa gennanica

Libellula depressa

Orthelrum coenilescens
Chiysocoris piirpureus

Tabanns bovinus

Argynnis pandora

Sympetrinn meiidionale
Macroglossa stelatonim

j\inphimallon solstilialis

Automeris jaciinda

Mass
(g)

0-133

0-134

0-142
0-144
0-144

0-159

0-165

0-165

0-168
0169

0-173
0-176

0-178
0-187

0-189
0-195

0-200
0-201

0-226

0-233

0-237
0-240
0-245

0-248

0-264
0-276
0-278
0-281

0-282
0-291

0-298

Wing area

(cm

2

)
3-20

10-800
1 33

17-200
4-400

0-900

8-000

7-500
2-334
0-79

10-400
8-38

8-476
0-980
2-620

14-000

3-950
5-000

0-900
1-500

8-000
1-330

13-200

10-800
1-50

1-840
18-00

10-000

3-790
2-290

7-572

Wing

loading
(gem"

2

)

0-04

0-012
0-107
0-08

0-033
0-177
0-021

0-022

0-072
0-21

0-017
0-021

0-021
0-191

0-072

0-0147
0-051

0-040
0-251

0-155

0-030
0-180
0019

0-023
0-18

0-150
0-015

0-028
0074

0-127

0-039

Wingbeat

frequency

(Hz)
41

10
80

10-5
48

135
20

27-6

32-4
179
20

28

24-3
no
80

18

21-6
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
Citation
Magnan, 1934

Magnan, 1934

Sotavalta, 1952

Sotavalta, 1952
Magnan, 1934

Magnan, 1934

Magnan, 1934
May, 1981

Bartholomew & Casey, 1978

Casey et al. 1985
Magnan, 1934
May, 1981

May, 1981

Magnan, 1934

Magnan, 1934

Magnan, 1934

Bartholomew & Casey, 1978

Magnan, 1934

Magnan, 1934
Magnan, 1934

Magnan, 1934

Sotavalta, 1952
Magnan, 1934

Magnan, 1934
Ahmad, 1984

Magnan, 1934
Magnan, 1934
Magnan, 1934

Sotavalta, 1952

Sotavalta, 1952

Bartholomew & Casey, 1978

z
•art
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
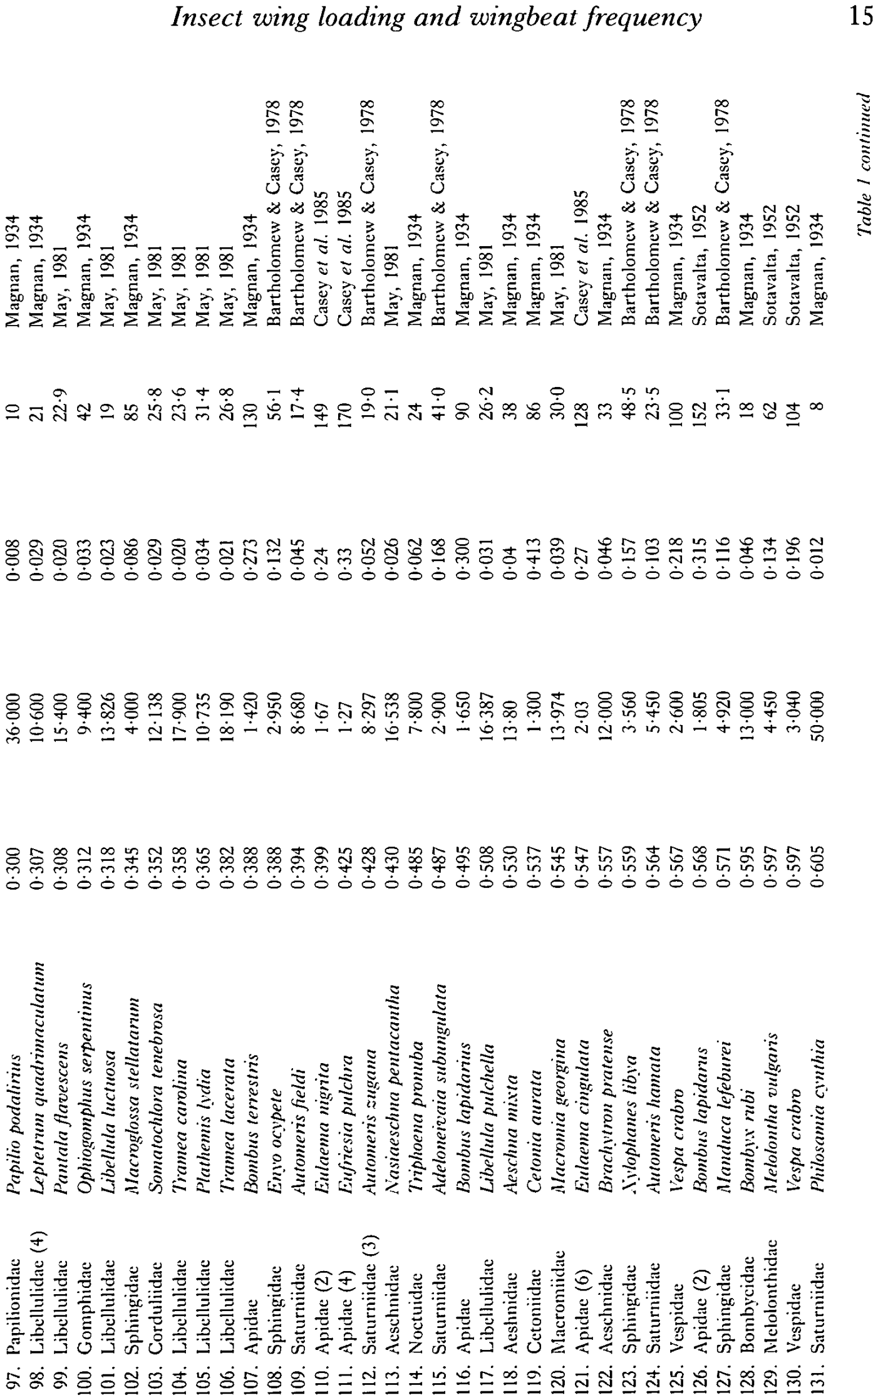
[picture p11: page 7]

97

. Papilionida

c

98

. Libcllulida

c (4

)

99

. Libcllulida

c

100

. Gomphida

c

101

. Libcllulida

o

102

. Sphingida

c

103

. Corduliida

c

104

. Libcllulida

c

10S

. Libcllulida

c

106

. Libcllulida

c

107

. Apida

c

108

. Sphingida

c

109

. Saturniicla

c

110

. Apida

e (2

)

111

. Apida

c (4

)

112

. Saturniicla

c (3

)

113

. Acschnida

c

114

. Noctuida

c

115

. Saturniida

c

116

. Apida

c

117

. Libcllulida

c

118

. Acshnida

e

119

. Cetoniida

e

120

. Macromiida

c

121

. Apida

c (6

)

122

. Acschnida

c

123

. Sphingida

c

124

. Saturniida

c

125

. Vcspida

c

126

. Apida

c (2

)

127

. Sphingida

c

128

. Bombycida

c

129

. Mclolonthida

c

130

. Vcspida

c

131

. Saturniida

c

Papilio podalirius

Leptetntm quadrimnculatum

Pantala flavescens

Ophiogomphus serpentiniis

Libellula htctitosa

Maavglossa stellatantm
Somatochlora tenebmsa

Tramea Carolina
Plathemis lydia

Tramea lacerata

Bombus lerrestris
Enyo ocypete

An tome ris fie Id i

Eulaema nigrita

Eufriesia pulchra

Automens zugana

Nasiaeschna pentacantha

Tnphoena pronuba

Adeloneivaia siibungulata

Bombus lapidarius
Libellula pulchella
Aeschna inixta

Celonia aurata

Macromia georgina
Eulaema cingulata

Brachytwn pratense
Xylophones libya

Automeris hamata

Vespa crabro

Bombus lapidarus

Manduca lefeburei

Bombyx nibi

Melolontha vulgaris

Vespa crabro

Philosamia cvnthia

0-30

0
0-30

7
0-30

8
0-31

2
0-31

8
0-34

5
0-35

2
0-35

8
0-36

5
0-38

2
0-38

8
0-38

8
0-39

4
0-39

9
0-42

5
0-42

8
0-43

0
0-48

5
0-48

7
0-49

5
0-50

8
0-53

0
0-53

7
0-54

5
0-54

7
0-55

7
0-55

9
0-56

4
0-56

7
0-56

8
0-57

1
0-59

5
0-59

7
0-59

7
0-60

5

3600

0
10-60

0
15-40

0
9-40

0
13-82

6
4-00

0
12-13

8
17-90

0
10-73

5
18-19

0
1-420
2-95

0
8-68

0
1-67

1-27

8-29

7
16-53

8
7-80

0
2-90

0
1-65

0
16-38

7

13-8

0

1-300
13-97

4

2-0

3

12-00

0
3-56

0
5-45

0
2-60

0
1-805
4-92

0
13-00

0
4-45

0
3-04

0
50-00

0

0-00

8
0-02

9
0-02

0
0-03

3
0-02

3
0-08

6
0-02

9
0-02

0
0-03

4
0-02

1
0-27

3
0-13

2
0-04

5

0-2

4
0-3

3

0-05

2
0-02

6
0-06

2
0-16

8
0-30

0
0-03

1

0-0

4
0-41

3
0-03

9

0-2

7

0-04

6
0-15

7
0-10

3
0-21

8
0-31

5
0-11

6
0-04

6
0-13

4
0-19

6
0-01

2

1

0 Magnan

, 193

4

2

1 Magnan

, 193

4

22-

9 May

, 198

1

4

2 Magnan

, 193

4

1

9 May

, 198

1

8

5 Magnan

, 193

4

25-

8 May

, 198

1

23-

6 May

, 198

1

31-

4 May

, 198

1

26-

8 May

, 198

1

13

0 Magnan

, 193

4

56-

1 Bartholome

w & Casey

, 197

8

17-

4 Bartholome

w & Casey

, 197

8

149 Case

y et al. 198

5

17

0 Case

y et al. 198

5

19-

0 Bartholome

w & Casey

, 197

8

21-

1 May

, 198

1

2

4 Magnan

, 193

4

41-

0 Bartholome

w & Casey

, 197

8

9

0 Magnan

, 193

4

26-

2 May

, 198

1

3

8 Magnan

, 193

4

8

6 Magnan

, 193

4

30-

0 May

, 198

1

12

8 Case

y et al. 198

5

3

3 Magnan

, 193

4

48-

5 Bartholome

w & Casey

, 197

8

23-

5 Bartholome

w & Casey

, 197

8

100 Magnan

, 193

4

15

2 Sotavalta

, 195

2

33-

1 Bartholome

w & Casey

, 197

8

1

8 Magnan

, 193

4

6

2 Sotavalta

, 195

2

104 Sotavalta

, 195

2

8 Magnan

, 193

4

8- Iis

TOa

Table 1 continued

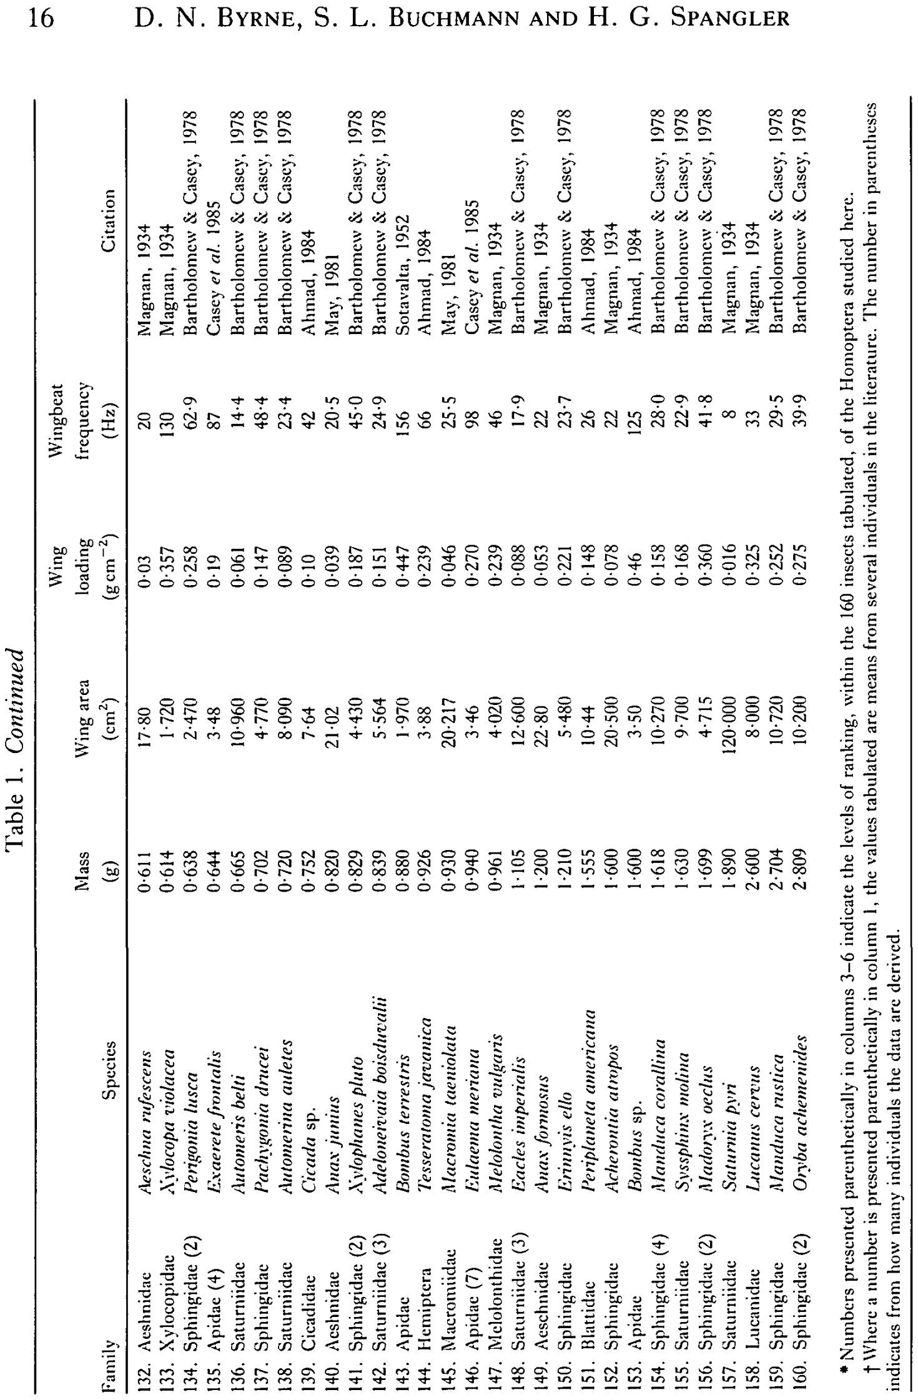
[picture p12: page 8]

Table 1. Continued

Family

132. Aeshnidae
133. Xylocopidac
134. Sphingidae (2)
135. Apidae (4)
136. Saturniidac
137. Sphingidae
138. Saturniidae
139. Cicadidae
140. Aeshnidae
141. Sphingidae (2)
142. Saturniidae (3)
143. Apidae
144. Hemiptcra
145. Macromiidae
146. Apidae (7)
147. Mclolonthidae
148. Saturniidae (3)
149. Aeschnidae
150. Sphingidae
151. Blattidac
152. Sphingidae
153. Apidae
154. Sphingidae (4)
155. Saturniidae
156. Sphingidae (2)
157. Saturniidae
158. Lucanidae
159. Sphingidae
160. Sphingidae (2)

Species
Aesclnui nifescens

Xylocopa violacea
Perigonia lusca

Exaerete fmntaiis
Automeris belli

Pachygonia dnicei

Aiitoiiierina auletes

Cicada sp.

Anax junius

Xylophones pluto

Adelotieivaia boisduvalii

Bombus terrestris

Tesseraloma javanico
Macmmia laeniolata
Eulaema meriana

Melolonlha vulgaris
Hades imperialis
Anax fonimsits
Erinnyis ello

Periplanela americana
Achemnlia ativpos

Bombus sp.

Manduca corallina
Svssphinx tnolina
Madoryx oeclus
Satumia pyri

Ljicanus cervus

Manduca nistica

Oryba achemenides

Mass
(g)

0-611

0-614

0-638
0-644

0-665

0-702
0-720

0-752
0-820
0-829

0-839

0-880

0-926

0-930

0-940
0-961
1-105

•200

•210
•555

•600
•600
•618

•630
1-699
1-890

2-600
2-704
;2-809

Wing area

(cm

2

)
17-80

1-720

2-470
3-48

10-960
4-770

8-090
7-64

21-02

4-430

5-564
1-970
3-88

20-217
3-46

4-020

12-600
22-80

5-480
10-44

20-500
3-50

10-270

9-700
4-715

120-000

8-000
10-720
10-200

Wing

loading
(gem"

2

)

0-03

0-357

0-258
0-19

0-061

0-147

0-089
0-10

0-039
0-187
0-151

0-447

0-239

0-046

0-270

0-239

0-088
0-053
0-221

0-148

0-078
0-46

0-158

0-168

0-360
0-016

0-325

0-252
0-275

Wingbeat

frequency

(Hz)
20

130

62-9
87

14-4
48-4

23-4
42

20-5

45-0

24-9
156
66

25-5
98

46

17-9
22

23-7
26

22

125

280

22-9

41-8
8
33

29-5

39-9

Citation
Magnan, 1934

Magnan, 1934

Bartholomew & Casey,

Casey el al. 1985

Bartholomew & Casey,

Bartholomew & Casey,
Bartholomew & Casey,

Ahmad, 1984
May, 1981

Bartholomew & Casey,

Bartholomew & Casey,

Sotavalta, 1952
Ahmad, 1984
May, 1981

Casey el al. 1985
Magnan, 1934

Bartholomew & Casey,

Magnan, 1934

Bartholomew & Casey,

Ahmad, 1984

Magnan, 1934
Ahmad, 1984

Bartholomew & Casey,
Bartholomew & Casey,

Bartholomew & Casey,

Magnan, 1934

Magnan, 1934

Bartholomew & Casey,

Bartholomew & Casey,

1978

1978

1978

1978

1978

1978

1978

1978

1978

1978

1978

1978

1978

ON
o
•

2:
-<
JO

m

r fi

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
* Numbers presented parenthetically in columns 3- 6 indicate the levels of ranking, within the 160 insects tabulated, of the Homoptera studied here.

•(•Where a number is presented parenthetically in column 1, the values tabulated are means from several individuals in the literature. Th e numbe r in parentheses

ndicates from how many individuals the data are derived.

Insect wing loading and wingbeat frequency

Table 2. Wing length (in mm) of measured homopterous insects

17

Species
Acynhosiphon kondoi

Aleurothrixus floccosus

Aphis fabae

Aphis gossypii

Aphis nerii

Bemisia tabaci

Dialeurodes citri
(female)
Dialeurodes citri
(male)
Myzus persicae

Trialeurodes abutilonea

Trialeurodes vaporarionim

forewing
hindwing
forewing
hindwing
forewing
hindwing
forewing
hindwing
forewing
hindwing
forewing
hindwing
forewing
hindwing
forewing
hindwing
forewing
hindwing
forewing
hindwing
forewing
hindwing

X
3-39
1-93
1-52
0-94
2-66
1-62
2-18
1-37
2-94
1-75
0-84
0-69
1-37
116
116
0-93
3-08
1-89
0-98
0-78
0-99
0-84

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
Coefficient
of variation
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
Wingbeat frequency
The two families could also be separated by wingbeat frequency (Table 1). Aphids had significantly lower wingbeat frequencies than whiteflies (range 81-1—123-4 Hz for aphids, 165-6-224-2 Hz for whiteflies) (P<0-01). Within the groups, only two aphids, Zip. nerii and Ap. gossypii, and two whiteflies, Al. floccosus and .8. tabaci, had wingbeat frequencies not significantly different from one another (P>0-05).

Wing loading
Calculated wing loadings for aphids (6-33X10 to 0-01412gem ) were all larger than those of whiteflies (1-74-5-23X 10~³

gcm~²
; Table 1).

Relationships between wingbeat frequency and morphometrics Relationships between wingbeat frequency and various body morphometrics, such as wing area and length, body mass and wing loading, were evaluated for all measured insect species (exclusive of D. citri) (Table 3). Coefficients of determination (r²
) revealed that wingbeat frequency was most closely linked with body mass

18 | D. N. BYRNE, S. L. BUCHMANN AND H. G. SPANGLER
Table 3. Relationships between wingbeat frequency and body morphometrics for selected members of Aleyrodidae and Aphididae

Body characteristic
Forewing area
Hindwing area
Total area
Forewing length
Hindwing length
Body mass
Wing loading

NS, not significant.

Coefficient
of determination
r

2

0-6939
0-5569
0-6651
0-9261
0-9160
0-8275
0-6680

F value
7-43
3-60
6-35
48-23
41-69
17-37
6-45

Significance
P<
0-05
NS
NS
0001
0-001
0-005
0-05

and fore- and hindwing length: 68 % of the variation in wingbeat frequency was attributable to body mass, and >80% to length of both the forewings and hindwings. Compared with whiteflies, aphids generally have lower wingbeat frequencies and higher wing loading.

Relationships with other insects Our homopterans weighed less than all the insects whose flight-associated morphometrics were measured in previous studies. Masses ranged from 3⁻

3x 10~⁵
g
(B. tabaci) to 2-809g (Oryba achemenides) (Table 1). Using total wing surface area as a criterion for size, our homopterans are among the smallest insects for whom wing loading and wingbeat frequencies have been calculated. The range of wing surface areas was from 9-6xlO~³

cm²

(T. abutilonea) to 120-OOcm² (Saturnia pyri). Our
largest homopteran ranked only fourteenth out of 160.
The ratio of body mass to wing surface area was also low in the 11 homopterans, with five having wing loading values lower than any in the literature. The 160 insects ranged from l-74xlO~³

gcm~²

for male D. citri to 0-460gcm~² for Bombus spp.
None of those we measured exhibited a wing loading that ranked higher than 22nd out of 160 (Table 1). For wingbeat frequencies, our homopterans exhibited some of the highest values within the recorded range of 8—480Hz (Table 1). Rankings for whiteflies and aphids ranged from 89th to 152nd of 158.
We were also interested in the statistical relationship between body mass, wing loading and wingbeat frequency for all insects either in the literature or measured herein. Since D. citri was not included (for reasons discussed previously) the statistical comparisons involve 158 species. Using wing loading as the independent variable and calculating coefficients of determination for all 158 insects, we found that wing loading accounted for only 5-5 % of the variation in wingbeat frequency (r²
= 0-0550, F value = 9-08). Similar calculations using body mass as the independent variable indicate that this parameter accounted for 14% of the variation in wingbeat frequency (r²
= 0-1378, F value = 2492). Considering both mass (first

Insect wing loading and wingbeat frequency | 19

entry) and wing loading (second entry) as independent variables in a stepwise regression, we found that 34% of the variation in wingbeat frequency was attributable to these two parameters (r²
= 0-344, F value = 40-58). Relationships between body mass, wing loading and wingbeat frequency became clearer after data had been sorted according to mass. The 158 species were divided into six groups of roughly equal size. Insects weighing more than 0-03 g had to be separated into groups because slopes for regression lines for wingbeat frequency and wing loading were significantly different (P< 0-015) (Table 4). The slope for animals weighing 0-030-0-104g was 1050-0, whereas the slope for insects weighing 0-720—2-809 g was 221-8. Coefficients of determination were calculated for the species within each mass group (Table 4). Examination of the F values indicated that the linear relationship between wingbeat frequency and wing loading was highly significant for all mass groups with the exception of the lightest animals (i.e. < 0-03 g) (/>< 0-001).
The importance of excluding the smaller insects from considerations of the relationships between wingbeat frequency and wing loading became more apparent when coefficients of determination were calculated for all insect species weighing >0-03g (Table 5). A log transformation of the independent variable, wing loading, and a log/log transformation of both the independent variable and the dependent variable, wingbeat frequency, improved the goodness-of-fit as shown by an increase inF values from 43-96 to 135-88. Similar transformation of data for insects weighing <0-03 g did little to improve the goodness-of-fit, as F values increased from 2-87 to 3-72. Log and log/ log transformation for insect species in the larger mass groups decreased F values, indicating a clearly linear relationship.
We attempted to identify the relationship between wingbeat frequency and wing loading for the various taxa shown in Table 1. Although a few cases, e.g. members of Sphingidae, showed significant correlations, the majority did not. The lack of significant correlations may have been due to small sample sizes or situations where animals were arbitrarily selected because of a taxonomic relationship from groups with different slopes.

DISCUSSION
In terms of flight-associated morphometrics, the two measured families differed from one another in all important parameters considered: body mass, wingbeat frequency and wing loading. These data support the earlier observation concerning distribution of whiteflies and aphids in air columns. Our data also demonstrate that, although closely related, these insects employ different methods of flight.
The relationship between wingbeat frequency and wing loading is of special significance. The finding that whiteflies had a higher wingbeat frequency and a lower wing loading than aphids was unexpected. Other authors have argued that insects with heavy bodies in relation to total wing surface area should beat their wings more rapidly than insects of similar mass, but with larger wing surface areas (Dorsett, 1962; Bartholomew & Heinrich, 1973). This seems to be theoretically correct as well

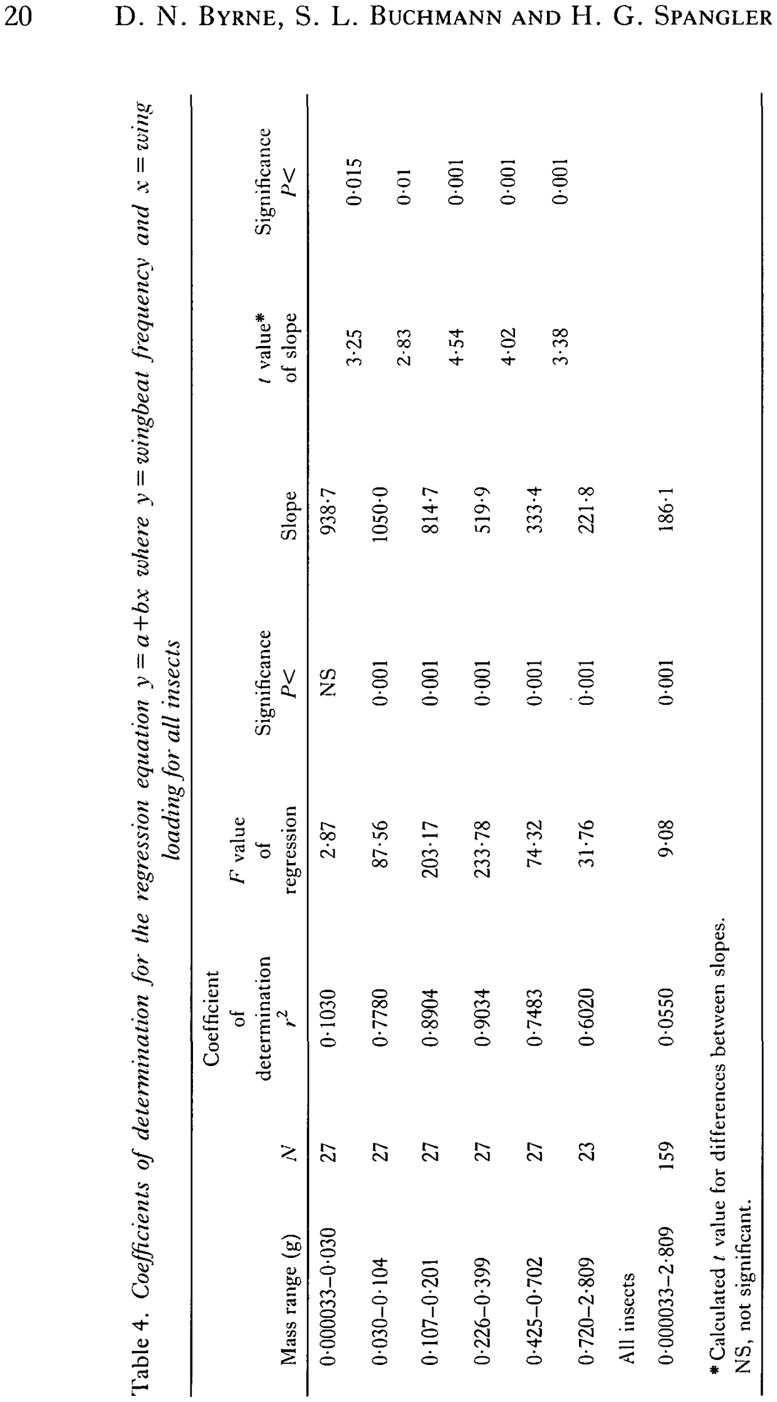
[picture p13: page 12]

Table 4. Coefficients of determination for the regression equation y = a+bx where y = wingbeat frequency and x=zuing

Mass range (g)

0-000033-0-030
0-030-0-104
0-107-0-201

0-226-0-399

0-425-0-702
0-720-2-809
All insects

0-000033-2-809

* Calculated t value

NS, not significant.

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
Coefficient

of

determination

r

2

0-1030

0-7780

0-8904

0-9034
0-7483

0-6020

0-0550

for differences between slopes.

loading for

F value

of

regression
2-87

87-56
203-17

233-78

74-32

31-76
9-08

all insects

Significance

P<

NS

0-001

0-001

0-001

0-001
0-001

0-001

Slope

938-7

1050-0
814-7
519-9

333-4
221-8

186-1

/ value*
of slope
3-25

2-83

4-54

4-02
3-38

Significance

P<

0015
0-01

0-001

0-001

0-001

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
Insect wing loading and wingbeat frequency | 21

as agreeing with other authors' (Ahmad, 1984; Greenewalt, 1962) statements about birds and bats, which apparently also employ an increased wingbeat frequency tactic. This study of wingbeat frequency and wing loading in our measured homopterans (as well as other small insects) has helped shed some light on these relationships among insects in general, about which differing conclusions have been drawn. Certain authors have concluded that wing loading and wingbeat frequency are significantly correlated, especially if wing lengths are part of the equation (e.g. May, 1981). Others, such as Bartholomew & Casey (1978), are less certain of such a relationship and suggest that it is variable. Finally, others (Casey, May & Morgan, 1985) state no such relationship could be established for insect species they studied. Our data demonstrate that among groups of larger insects wingbeat frequency and wing loading are significantly correlated, conforming to the hypothesis that animals with high wing loading compensate by using higher wingbeat frequencies. The differences in the steepness of the slopes of regression lines for each group indicate that smaller insects employ increased wingbeat tactic at rates exponentially higher than for larger insects.
Previous authors whose data failed to indicate a correlation between these two parameters may have considered either too few subjects or mixed insect species whose body masses were dramatically different. Casey et al. (1985) measured euglossine bees and showed that their wingbeat frequencies were inversely correlated with wing length and mass, but not with wing loading. We incorporated their data on bees into our larger data set, selecting groups of the same size as those used in our calculations (i.e. 26 ± 2), which included their insects. The correlation between wing loading and wingbeat frequency for the groups was highly significant for each (P< 0-001) (Table 6). Similar incorporations and recalculations were made using the data for members of the Sphingidae and Saturniidae generated by Bartholomew

Table 5. Coefficient of determination for log transformations where y = wingbeat frequency and x = wing loading

Mass range (g)
3-3xl(T⁵
to 2-809 (all insects)
no transformation
log transformation of x
log/log transformation
003-2-809 (without smallest insects) no transformation
log transformation of x
log/log transformation
3-3xlO~⁵
to 003 (smallest insects)
no transformation
log transformation of x
log/log transformation

Coefficient of
determination
r

2

00550
00623
0-3831

0-2542
0-3498
0-6489

01030
0-1227
01294

F value

908
10-36
26-68

43-96
69-41
135-87

2-87
3-49
3-72

Significance
P<

0003
0002
0001

0-001
0001
0001

01
0073
0065

22 | D. N. BYRNE, S. L. BUCHMANN AND H. G. SPANGLER
Table 6. Relationship between wingbeat frequency and wing loading among members of Apidae, Saturniidae and Sphingidae determined after combining referenced data

Family
Apidae

Saturniidae

Sphingidae

* Data from

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
Table 4.

Mass range*
(g)
0-071-0-144
0-144-0-291
0-298-0-547
0-557-0-940
0168-0-318
0-345-0-595
0-597-1-631
0-388-0-638
0-644-2-809

Coefficient of
determination
r

2
0-8369
0-8836
0-7212
0-8392
0-8879
0-7159
0-7573
0-7280
0-5712

F value
12311
18216
6209
120-04
205-86
62-99
78-07
66-93
31-37

Significance
P<
0001
0001
0001
0-001
0-001
0-001
0-001
0001
0-001

& Casey (1978). Results were the same, i.e. correlations between wingbeat frequency and wing loading were highly significant (P < 0-001) (Table 6).
For very small insects, the lack of relationship may be explained by the fact that some minute species solve the problem of staying aloft in unique ways. Some, like whiteflies (Wootton & Newman, 1979) and Drosophila (Weis-Fogh, 1972), employ a clap and fling mechanism to generate extra lift. This reduces the need for exceptionally high wingbeat frequencies, and agrees with the data presented here. Our data also support Pringle's (1976) correct prediction that, because they have exceptionally low wing loadings, whiteflies would not have the high wingbeat frequencies commonly associated with small insects (e.g. 480 Hz for Aedes aegypli; Table 1). Whitefly wingbeat frequencies are rather more correctly characterized as being mid-range (here 165-6-224-2Hz; Table 1). The same strategy may be employed by other insects weighing <003g. A third possibility is that many small insects accomplish flight in a manner similar to that reported for aphids (Haine, 1955), i.e. by relying to a large extent on an ability to use wind currents passively. Being small, they have low settling velocities because of high drag coefficients. Any of these strategies would help explain why small insects may not conform to the generalization that animals with high wing loading have a high wingbeat frequency (e.g. members of Hymenoptera) and that insects with low wing loading have a low wingbeat frequency (e.g. members of Lepidoptera). Any group of small insects may contain several statistical 'outliers', resulting in a lack of relationship between wingbeat frequency and wing loading.

The authors thank T. S. Bellows and T. R. Unruh of the University of California, Riverside and D. Coudriet of USDA, Riverside for supplying and measuring some insects. We thank P. K. von Bretzel, H. E. DeVries, S. X. Sakaluk, F. G. Werner and R. L. Smith of the University of Arizona for their valuable comments during

Insect wing loading and wingbeat frequency | 23

manuscript preparation. Finally, we thank E. A. Draeger and D. W. Zeh of the University of Arizona for their invaluable efforts in providing technical assistance during the course of this study. Journal Series No. 4241 of the University of Arizona Agricultural Experimental Station.

REFERENCES
AHMAD, A. (1984). A comparative study on flight surface and aerodynamic parameters of insects, birds and bats. Indian jf. exp. Biol. 22, 270-278.
ANSARI, A. R. & BRADLEY, R. A. (1960). Rank-sum tests for dispersions. Ann. Math. Stat. 31, 1174-1189.
BARTHOLOMEW, G. A. & CASEY, T. M. (1978). Oxygen consumption of moths during rest, pre-flight warm-up, and flight in relation to body size and wing morphology, jf. exp. Biol. 76, 11—25. BARTHOLOMEW, G. A. & HEINRICH, B. (1973). A field study of flight temperatures in moths in relation to body weight and wing loading. J. exp. Biol. 58, 123-135.
BROADBENT, L. (1948). Aphis migration and the efficiency of the trapping method. Ann. Appl. Biol. 35, 379-394.
BYRNE, D. N., VON BRETZEL, P. K. & HOFFMAN, C. J. (1986). Impact of trap design and placement when monitoring for the bandedwinged whitefly and the sweetpotato whitefly. Environ. Entomol. 15, 300-304.
CASEY, T. M. (1981). Energetics and thermoregulation of Malacosoma americanum (Lepidoptera:Lasiocampidae) during hovering flight. Physiol. Zool. 54, 362-371.
CASEY, T. M., MAY, M. L. & MORGAN, K. R. (1985). Flight energetics of euglossine bees in relation to morphology and wing stroke frequency..7. exp. Biol. 116, 271-289.
DORSETT, D. A. (1962). Preparation for flight by hawk-moths. J. exp. Biol. 39, 579-588. GREENEWALT, C. H. (1962). Dimensional relationships for flying animals. Snnthson. Misc. Colitis. 144, 1-46.
HAINE, E. (1955). Aphid take-off in controlled wind speeds. Nature, Land. 175, 474-475. MAGNAN, A. (1934). La Locomotion Chex les Animaux, vol. 1, Le Vol des Insectes. Paris: Hermann & Co. 183 pp.
MANN, H. B. & WHITNEY, D. R. (1947). On a test of whether one of two random variables is stochastically larger than the other. Ann. Math. Statistics. 18, 50-60.
MAY, M. L. (1981). Wingstroke frequency of dragonflies (Odonata: Anisoptera) in relation of temperature and body size. J. comp. Physiol. 144, 229-240.
PRINGLE, J. VV. S. (1976). The muscles and sense organs involved in insect flight. In Insect Flight (ed. R. C. Rainey), pp. 3-15. New York: John Wiley & Sons.
SHAPIRO, S. S. & WlLK, M. B. (1965). An analysis of variance test for normality (complete samples). Biometrika 52, 591-611.
SOTAVALTA, 0 . (1952). The essential factor regulating the wing stroke frequency of insects in wing mutilation and loading experiments and in experiments at subatmospheric pressure. Ann. Zool. Soc. "Vanaino" 15, 1-67.
UNWIN, D. M. & ELLINGTON, C. P. (1979). An optical tachometer for measurement of the wingbeat frequency of free-flying insects..7. exp. Biol. 82, 377-378.
VOGEL, S. (1966). Flight in Drosophila. I. Flight performance of tethered flies. J. exp. Biol. 44, 567-578.
WEIS-FOGH, T. (1972). Energetics of hovering flight in hummingbirds and Drosophila. J. exp. Biol. 56,79-104.
WEIS-FOGH, T. (1973). Quick estimates of flight fitness in hovering animals, including novel mechanisms for lift production. J. exp. Biol. 59, 169-230.
WOOTTON, R. J. & NEWMAN, D. J. S. (1979). Whitefly have the highest contraction frequencies yet recorded in non-fibrillar muscles. Nature, Land. 280, 402-403.

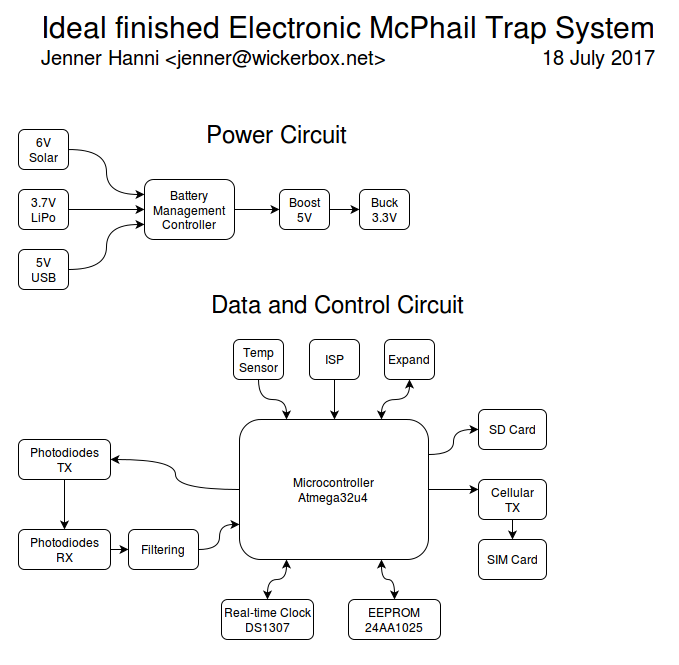
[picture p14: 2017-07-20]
hardware/mcphail-main-board/blockdiagram.png

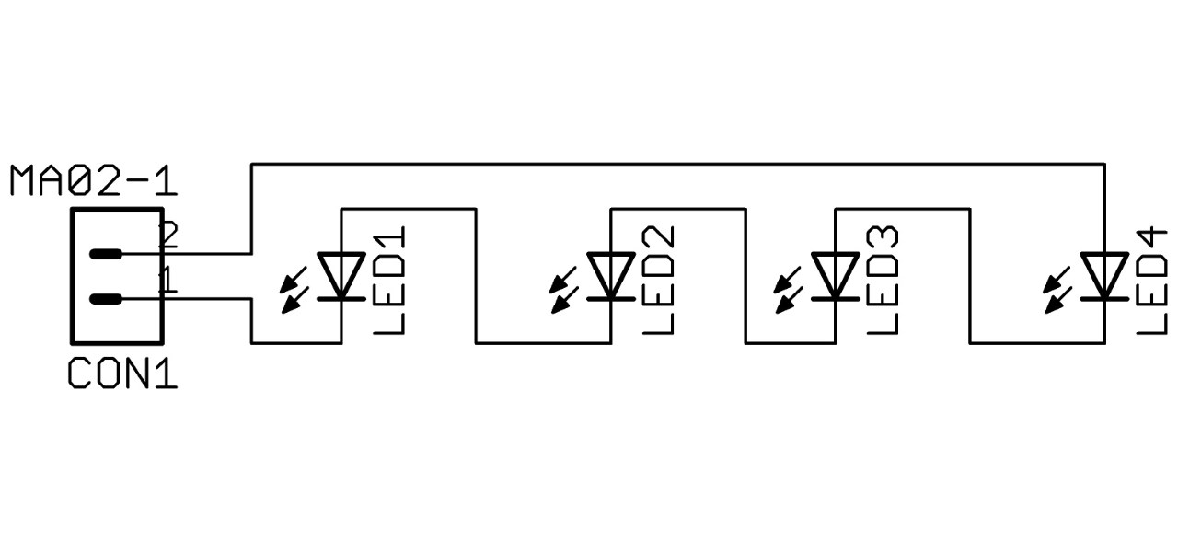
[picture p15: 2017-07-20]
research/2015-Insect-Biometrics-Optoacoustic-Signal-McPhail-s021.TIF

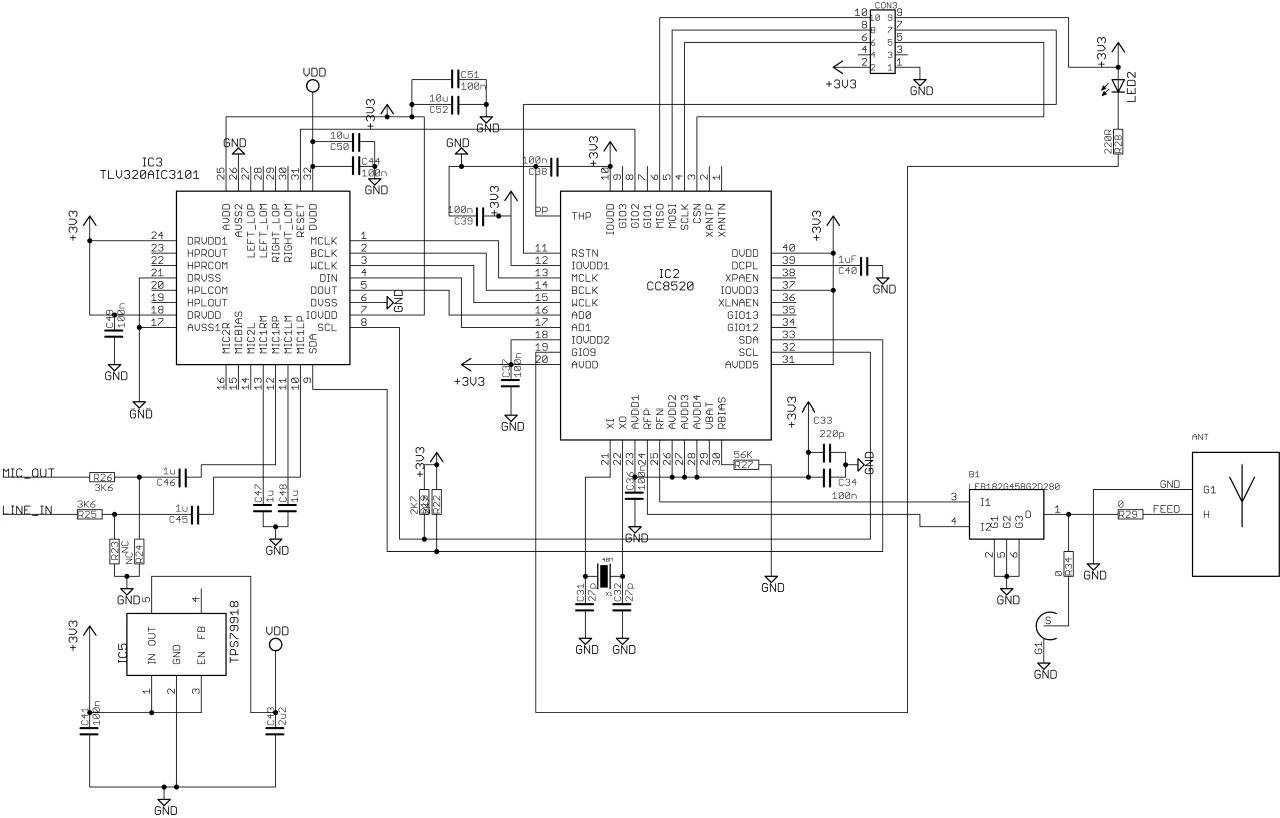
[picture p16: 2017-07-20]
research/2015-Insect-Biometrics-Optoacoustic-Signal-McPhail-s029.TIF

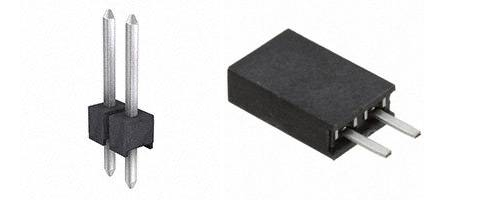
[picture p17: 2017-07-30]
research/example-connector.png

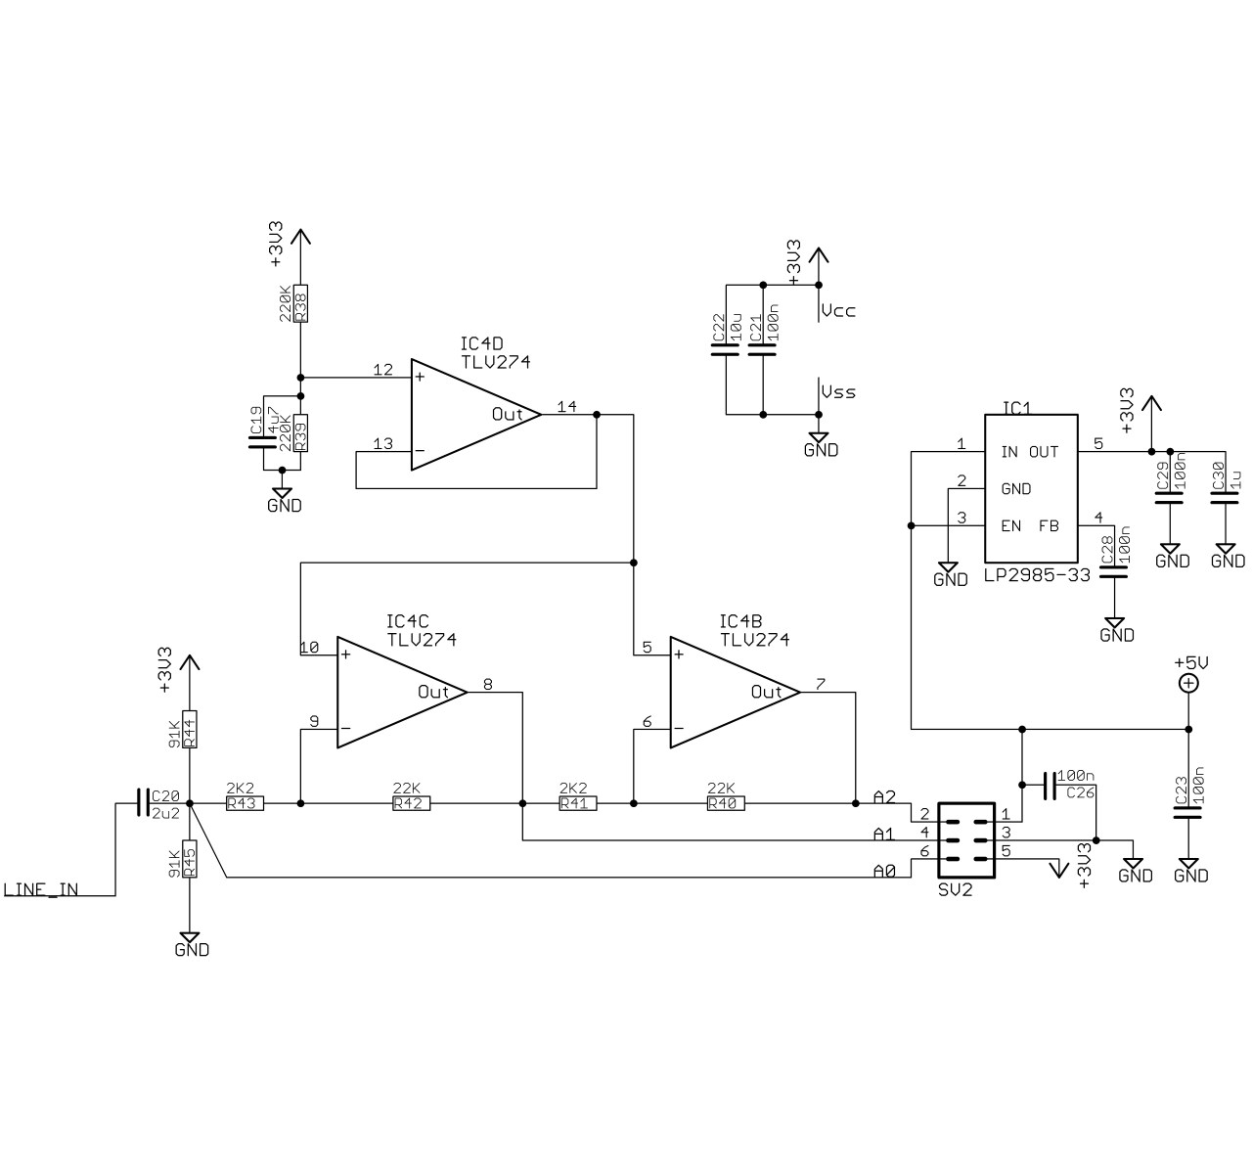
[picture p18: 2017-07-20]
research/2015-Insect-Biometrics-Optoacoustic-Signal-McPhail-s024.TIF

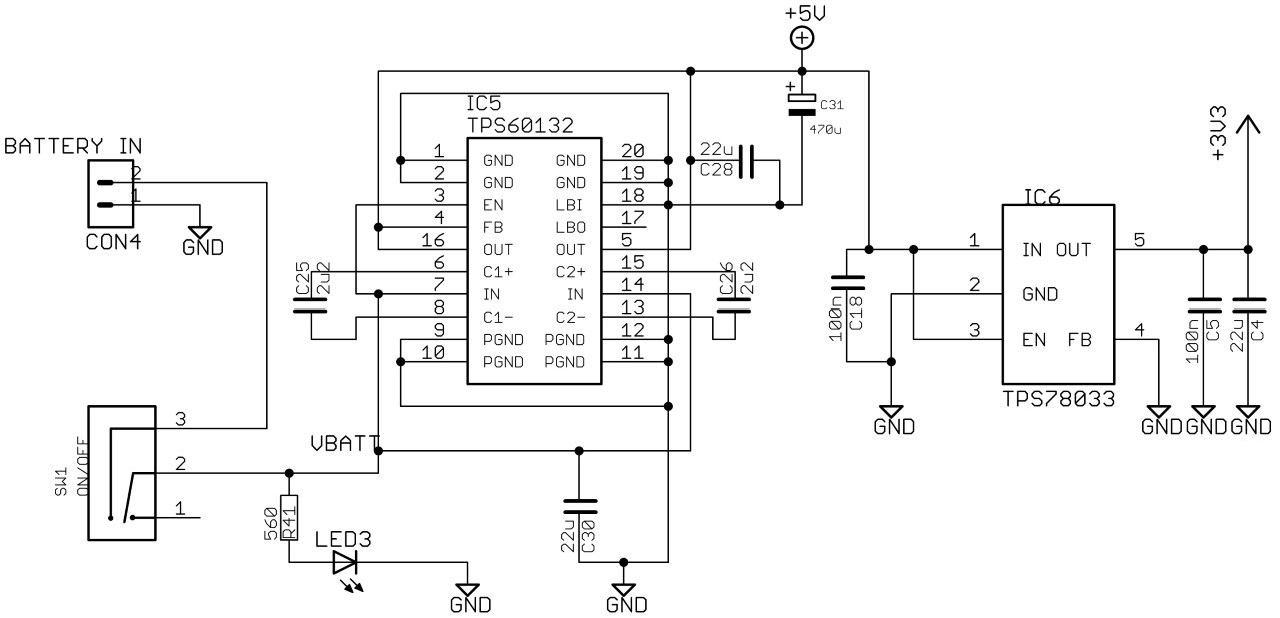
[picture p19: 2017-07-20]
research/2015-Insect-Biometrics-Optoacoustic-Signal-McPhail-s025.TIF

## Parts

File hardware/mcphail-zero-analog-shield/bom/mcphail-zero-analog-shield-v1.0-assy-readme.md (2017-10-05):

Individual Placements per board: 43

Number of Parts: 71

Board size is 2.79 x 2.10 inches (70.87 x 53.34 mm)

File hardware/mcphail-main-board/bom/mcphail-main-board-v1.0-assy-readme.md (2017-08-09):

Individual Placements per board: 76

Number of Parts: 144

Board size is 3.17 x 2.23 inches (80.64 x 56.63 mm)

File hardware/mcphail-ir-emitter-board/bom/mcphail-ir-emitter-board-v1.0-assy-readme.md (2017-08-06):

Individual Placements per board: 2

Number of Parts: 11

Board size is 2.70 x 0.50 inches (68.58 x 12.70 mm)

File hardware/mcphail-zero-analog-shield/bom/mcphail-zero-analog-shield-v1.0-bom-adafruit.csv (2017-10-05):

Ref | Qty | Qty3 | Description | Adafruit PN
U5 | 1 | 3 | ARDUINO ZERO SHIELD | 2843

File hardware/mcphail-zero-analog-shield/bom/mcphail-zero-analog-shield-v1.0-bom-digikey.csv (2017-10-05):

Ref | Qty | Qty3 | Description | Digikey PN
C1 | 1 | 3 | CAP ALUM 330UF 20% 16V RADIAL | 732-8798-1-ND
C10 | 1 | 3 | CAP CER 0.27UF 16V X7R 0603 | 490-6427-1-ND
C11 C13 C2 C7 | 4 | 12 | CAP CER 1.5UF 25V X7R 1206 | 1276-6873-1-ND
C12 C28 C8 | 3 | 9 | CAP CER 0.01UF 50V X7R 0603 | 490-1512-1-ND
C14 C29 C4 C9 | 4 | 12 | CAP CER 1UF 25V X7R 0805 | 1276-1066-1-ND
C15 C6 | 2 | 6 | CAP CER 22UF 25V X7R 1210 | 1276-3392-1-ND
C16 C17 C19 C22 | 4 | 12 | CAP CER 2.2UF 25V X7R 0805 | 1276-2953-1-ND
C18 | 1 | 3 | CAP CER 33PF 16V X7R 0603 | 478-6211-1-ND
C20 C21 C23 C24 | 4 | 12 | CAP CER 4.7UF 50V X7R 1206 | 1276-2789-1-ND
C25 | 1 | 3 | CAP CER 10UF 16V X7R 0805 | 1276-2872-1-ND
C26 | 1 | 3 | CAP CER 0.1UF 100V X7R 0603 | 490-3285-1-ND
C27 | 1 | 3 | CAP CER 0.022UF 50V X7R 0603 | 1276-2004-1-ND
C3 | 1 | 3 | CAP CER 0.22UF 25V X7R 0603 | 1276-1111-1-ND
C5 | 1 | 3 | CAP CER 0.039UF 50V X7R 0603 | 1276-2056-1-ND
J1 J2 | 2 | 6 | CONN TERM SCREW GREEN 2.54MM 2POS TH | ED10561-ND
J3 | 1 | 3 | HEADER MALE 1POS | 952-1902-ND
LED1 | 1 | 3 | LED AMBER DIFFUSED 0603 SMD | 475-2712-1-ND
R1 R32 | 2 | 6 | RES SMD 220 OHM 5% 1/10W 0603 | 311-220GRCT-ND
R10 | 1 | 3 | RES SMD 732 OHM 1% 1/10W 0603 | P732HCT-ND
R11 R8 | 2 | 6 | RES SMD 1.43K OHM 1% 1/10W 0603 | P1.43KHCT-ND
R12 R16 R23 | 3 | 9 | RES SMD 2.26K OHM 1% 1/10W 0603 | 311-2.26KHRCT-ND
R13 | 1 | 3 | RES SMD 10K OHM 1% 1/8W 0603 | RNCP0603FTD10K0CT-ND
R14 | 1 | 3 | RES SMD 470 OHM 5% 1/4W 0603 | RHM470DCT-ND
R15 | 1 | 3 | RES SMD 97.6K OHM 1% 1/10W 0603 | P97.6KHCT-ND
R17 | 1 | 3 | RES SMD 68 OHM 1% 1/10W 0603 | P68.0HCT-ND
R18 R19 | 2 | 6 | RES SMD 91K OHM 1% 1/10W 0603 | P91.0KHCT-ND
R2 | 1 | 3 | RES SMD 64.9K OHM 1% 1/10W 0603 | P64.9KHCT-ND
R20 R21 | 2 | 6 | RES SMD 220K OHM 5% 1/8W 0805 | P220KACT-ND
R22 R26 | 2 | 6 | RES SMD 2.2K OHM 5% 1/10W 0603 | P2.2KGCT-ND
R24 R28 | 2 | 6 | RES SMD 22K OHM 5% 1/10W 0603 | P22KGCT-ND
R25 R29 | 2 | 6 | RES SMD 4.32K OHM 1% 1/10W 0603 | P4.32KHCT-ND
R27 | 1 | 3 | RES SMD 2.94K OHM 1% 1/10W 0603 | P2.94KHCT-ND
R3 R4 | 2 | 6 | RES SMD 100K OHM 1% 1/10W 0603 | RMCF0603FG100KCT-ND
R30 R6 | 2 | 6 | RES SMD 3.83K OHM 1% 1/10W 0603 | P3.83KHCT-ND
R31 | 1 | 3 | RES SMD 0.0 OHM JUMPER 1/8W 0603 | MCT0603-0.0-ZZCT-ND
R5 | 1 | 3 | RES SMD 1.87K OHM 1% 1/10W 0603 | P1.87KHCT-ND
R7 | 1 | 3 | RES SMD 10 OHM 1% 1/10W 0603 | P10.0HCT-ND
R9 | 1 | 3 | RES SMD 470 OHM 5% 1/4W 0603 | 311-1.02KHRCT-ND
S1 | 1 | 3 | SWITCH TACTILE SPST-NO 0.05A 12V | SW1020CT-ND
U1 U2 | 2 | 6 | IC OPAMP QUAD GP RRO 1MHZ SOIC14 | MCP6004T-I/SLCT-ND
U3 | 1 | 3 | IC OPAMP GP 3MHZ RRO 14SOIC | 296-39258-1-ND
U4 | 1 | 3 | IC OPAMP GP 1MHZ RRO MCP6001 SOT23-5 | MCP6001T-I/OTCT-ND

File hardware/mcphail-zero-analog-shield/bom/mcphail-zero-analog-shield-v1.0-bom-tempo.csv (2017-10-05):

Refdes | Quantity | Description | Manufacturer | MPN
C1 | 1 | CAP ALUM 330UF 20% 16V RADIAL | Wurth | 860020373011
C10 | 1 | CAP CER 0.27UF 16V X7R 0603 | Murata | GRM188R71C274KA01D
C11 C13 C2 C7 | 4 | CAP CER 1.5UF 25V X7R 1206 | Samsung | CL31B155KAHVPNE
C12 C28 C8 | 3 | CAP CER 0.01UF 50V X7R 0603 | Murata | GRM188R71H103KA01D
C14 C29 C4 C9 | 4 | CAP CER 1UF 25V X7R 0805 | Samsung | CL21B105KAFNNNE
C15 C6 | 2 | CAP CER 22UF 25V X7R 1210 | Samsung | CL32B226KAJNNNE
C16 C17 C19 C22 | 4 | CAP CER 2.2UF 25V X7R 0805 | Samsung | CL21B225KAFNFNE
C18 | 1 | CAP CER 33PF 16V X7R 0603 | AVX | 0603YC330JAT2A
C20 C21 C23 C24 | 4 | CAP CER 4.7UF 50V X7R 1206 | Samsung | CL31B475KBHNNNE
C25 | 1 | CAP CER 10UF 16V X7R 0805 | Samsung | CL21B106KOQNNNE
C26 | 1 | CAP CER 0.1UF 100V X7R 0603 | Murata | GRM188R72A104KA35D
C27 | 1 | CAP CER 0.022UF 50V X7R 0603 | Samsung | CL10B223KB8SFNC
C3 | 1 | CAP CER 0.22UF 25V X7R 0603 | Samsung | CL10B224KA8NNNC
C5 | 1 | CAP CER 0.039UF 50V X7R 0603 | Samsung | CL10B393KB8SFNC
J1 J2 | 2 | CONN TERM SCREW GREEN 2.54MM 2POS TH | OnShoreTech | OSTVN02A150
J3 | 1 | HEADER MALE 1POS | Harwin | M20-9992046
LED1 | 1 | LED AMBER DIFFUSED 0603 SMD | OSRAM Opto | LA L296-Q2R2-1-Z
R1 R32 | 2 | RES SMD 220 OHM 5% 1/10W 0603 | Yageo | RC0603JR-0722RL
R10 | 1 | RES SMD 732 OHM 1% 1/10W 0603 | Panasonic | ERJ-3EKF7320V
R11 R8 | 2 | RES SMD 1.43K OHM 1% 1/10W 0603 | Panasonic | ERJ-3EKF1431V
R12 R16 R23 | 3 | RES SMD 2.26K OHM 1% 1/10W 0603 | Yageo | RC0603FR-072K26L
R13 | 1 | RES SMD 10K OHM 1% 1/8W 0603 | Stackpole | RNCP0603FTD10K0
R14 | 1 | RES SMD 470 OHM 5% 1/4W 0603 | Rohm Semi | ESR03EZPJ471
R15 | 1 | RES SMD 97.6K OHM 1% 1/10W 0603 | Panasonic | ERJ-3EKF9762V
R17 | 1 | RES SMD 68 OHM 1% 1/10W 0603 | Panasonic | ERJ-3EKF68R0V
R18 R19 | 2 | RES SMD 91K OHM 1% 1/10W 0603 | Panasonic | ERJ-3EKF9102V
R2 | 1 | RES SMD 64.9K OHM 1% 1/10W 0603 | Panasonic | ERJ-3EKF6492V
R20 R21 | 2 | RES SMD 220K OHM 5% 1/8W 0805 | Panasonic | ERJ-6GEYJ224V
R22 R26 | 2 | RES SMD 2.2K OHM 5% 1/10W 0603 | Panasonic | ERJ-3GEYJ222V
R24 R28 | 2 | RES SMD 22K OHM 5% 1/10W 0603 | Panasonic | ERJ-3GEYJ223V
R25 R29 | 2 | RES SMD 4.32K OHM 1% 1/10W 0603 | Panasonic | ERJ-3EKF4321V
R27 | 1 | RES SMD 2.94K OHM 1% 1/10W 0603 | Panasonic | ERJ-3EKF2941V
R3 R4 | 2 | RES SMD 100K OHM 1% 1/10W 0603 | Stackpole | RMCF0603FG100K
R30 R6 | 2 | RES SMD 3.83K OHM 1% 1/10W 0603 | Panasonic | ERJ-3EKF3831V
R31 | 1 | RES SMD 0.0 OHM JUMPER 1/8W 0603 | Vishay | MCT06030Z0000ZP500
R5 | 1 | RES SMD 1.87K OHM 1% 1/10W 0603 | Panasonic | ERJ-3EKF1871V
R7 | 1 | RES SMD 10 OHM 1% 1/10W 0603 | Panasonic | ERJ-3EKF10R0V
R9 | 1 | RES SMD 470 OHM 5% 1/4W 0603 | Yageo | RC0603FR-071K02L
S1 | 1 | SWITCH TACTILE SPST-NO 0.05A 12V | Omron | B3U-1000P
U1 U2 | 2 | IC OPAMP QUAD GP RRO 1MHZ SOIC14 | Microchip | MCP6004T-I/SL
U3 | 1 | IC OPAMP GP 3MHZ RRO 14SOIC | TI | TLV274CDR
U4 | 1 | IC OPAMP GP 1MHZ RRO MCP6001 SOT23-5 | Microchip | MCP6001T-I/OT
U5 | 1 | ARDUINO ZERO SHIELD | Arduino | ARDUINO ZERO

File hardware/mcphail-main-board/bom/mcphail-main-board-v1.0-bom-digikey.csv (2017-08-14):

Ref | Qty | Qty3 | Description | Digikey PN
BAT1 | 1 | 3 | CR1220 BATTERY HOLDER SMT FLATPIN | BK-916-CT-ND
C1 | 1 | 3 | CAP ALUM 330UF 20% 16V RADIAL | 732-8798-1-ND
C10 | 1 | 3 | CAP CER 0.27UF 16V X7R 0603 | 490-6427-1-ND
C11 C13 C2 C7 | 4 | 12 | CAP CER 1.5UF 25V X7R 1206 | 1276-6873-1-ND
C12 C28 C8 | 3 | 9 | CAP CER 0.01UF 50V X7R 0603 | 490-1512-1-ND
C14 C29 C34 C4 C49 C50 C9 | 7 | 21 | CAP CER 1UF 25V X7R 0805 | 1276-1066-1-ND
C15 C54 C55 C56 C6 | 5 | 15 | CAP CER 22UF 25V X7R 1210 | 1276-3392-1-ND
C16 C17 C19 C22 | 4 | 12 | CAP CER 2.2UF 25V X7R 0805 | 1276-2953-1-ND
C18 | 1 | 3 | CAP CER 33PF 16V X7R 0603 | 478-6211-1-ND
C20 C21 C23 C24 C43 C44 C45 | 7 | 21 | CAP CER 4.7UF 50V X7R 1206 | 1276-2789-1-ND
C25 C31 C46 C53 | 4 | 12 | CAP CER 10UF 16V X7R 0805 | 1276-2872-1-ND
C26 C30 C36 C37 C38 C39 C47 C51 C52 | 9 | 27 | CAP CER 0.1UF 100V X7R 0603 | 490-3285-1-ND
C27 | 1 | 3 | CAP CER 0.022UF 50V X7R 0603 | 1276-2004-1-ND
C3 | 1 | 3 | CAP CER 0.22UF 25V X7R 0603 | 1276-1111-1-ND
C33 C35 | 2 | 6 | CAP CER 22pF 50V NP0 0603 | 399-9031-1-ND
C40 C42 | 2 | 6 | CAP CER 2PF 50V C0G/NP0 0603 | 490-10713-1-ND
C41 | 1 | 3 | CAP CER 100PF 50V C0G/NP0 0603 | 490-1427-1-ND
C48 | 1 | 3 | CAP CER 10PF 50V NP0 0603 | 1276-2154-1-ND
C5 | 1 | 3 | CAP CER 0.039UF 50V X7R 0603 | 1276-2056-1-ND
D1 D4 | 2 | 6 | DIODE SCHOTTKY 20V 1A SMA | SS12-E3/61TGICT-ND
D2 D3 | 2 | 6 | VARISTOR ESD PROTECT USB | CG0603MLC-05ECT-ND
F1 | 1 | 3 | RESETTABLE FUSE 500mA 15V MF-MSMF | MF-MSMF050-2CT-ND
J1 J2 | 2 | 6 | HEADER MALE 2POS TH 1x02 0.1IN | 952-2262-ND
J3 | 1 | 3 | HEADER MALE 6POS KK100 0.1IN SHROUD TH | WM4204-ND
J4 | 1 | 3 | CONN MICRO SD CARD PUSH-PULL | WM9731CT-ND
J5 | 1 | 3 | USB MICRO-B RECEPTACLE 5PIN SMT R/A STUDS | 609-4616-1-ND
J6 | 1 | 3 | HEADER FEMALE 6POS 2x3 0.1IN | A30729CT-ND
J8 | 1 | 3 | CONN PWR JACK 2.5X5.5MM HIGH CUR | PJ-202BH
J9 | 1 | 3 | CONN HEADER PH SIDE 2POS 2MM | 455-1719-ND
L1 L3 L4 L5 | 4 | 12 | FERRITE BEAD 30 OHM 0805 1LN | MH2029-300YCT-ND
L2 | 1 | 3 | FIXED IND 1UH 3.3A 1226AS-H-1R0N | 490-14149-1-ND
LED1 LED2 LED3 | 3 | 9 | LED AMBER DIFFUSED 0603 SMD | 475-2712-1-ND
R1 | 1 | 3 | RES SMD 220 OHM 5% 1/10W 0603 | 311-220GRCT-ND
R10 | 1 | 3 | RES SMD 732 OHM 1% 1/10W 0603 | P732HCT-ND
R11 R8 | 2 | 6 | RES SMD 1.43K OHM 1% 1/10W 0603 | P1.43KHCT-ND
R12 R16 R23 | 3 | 9 | RES SMD 2.26K OHM 1% 1/10W 0603 | 311-2.26KHRCT-ND
R13 R33 R36 | 3 | 9 | RES SMD 10K OHM 1% 1/8W 0603 | RNCP0603FTD10K0CT-ND
R14 R39 R40 R41 | 4 | 12 | RES SMD 470 OHM 5% 1/4W 0603 | RHM470DCT-ND
R15 | 1 | 3 | RES SMD 97.6K OHM 1% 1/10W 0603 | P97.6KHCT-ND
R17 | 1 | 3 | RES SMD 68 OHM 1% 1/10W 0603 | P68.0HCT-ND
R18 R19 | 2 | 6 | RES SMD 91K OHM 1% 1/10W 0603 | P91.0KHCT-ND
R2 | 1 | 3 | RES SMD 64.9K OHM 1% 1/10W 0603 | P64.9KHCT-ND
R20 R21 | 2 | 6 | RES SMD 220K OHM 5% 1/8W 0805 | P220KACT-ND
R22 R26 | 2 | 6 | RES SMD 2.2K OHM 5% 1/10W 0603 | P2.2KGCT-ND
R24 R28 | 2 | 6 | RES SMD 22K OHM 5% 1/10W 0603 | P22KGCT-ND
R25 R29 | 2 | 6 | RES SMD 4.32K OHM 1% 1/10W 0603 | P4.32KHCT-ND
R27 | 1 | 3 | RES SMD 2.94K OHM 1% 1/10W 0603 | P2.94KHCT-ND
R3 R4 R44 | 3 | 9 | RES SMD 100K OHM 1% 1/10W 0603 | RMCF0603FG100KCT-ND
R30 R6 | 2 | 6 | RES SMD 3.83K OHM 1% 1/10W 0603 | P3.83KHCT-ND
R31 | 1 | 3 | RES SMD 330 OHM 5% 1/10W 0603 | 311-330GRCT-ND
R32 R37 | 2 | 6 | RES SMD 1K OHM 1% 1/10W 0603 | 1276-3484-1-ND
R34 R35 R43 | 3 | 9 | RES SMD 2K OHM 1% 1/8W 0603 | RNCP0603FTD2K00CT-ND
R38 | 1 | 3 | RES SMD 0.0 OHM JUMPER 1/8W 0603 | MCT0603-0.0-ZZCT-ND
R42 | 1 | 3 | NTC THERMISTOR 10K OHM 1% 0402 | 445-2550-1-ND
R45 R47 | 2 | 6 | RES SMD 1M OHM 5% 1/10W 0603 | P1.0MGCT-ND
R46 | 1 | 3 | RES SMD 111K OHM 5% 1/10W 0603 | P110GCT-ND
R5 | 1 | 3 | RES SMD 1.87K OHM 1% 1/10W 0603 | P1.87KHCT-ND
R7 | 1 | 3 | RES SMD 10 OHM 1% 1/10W 0603 | P10.0HCT-ND
R9 | 1 | 3 | RES SMD 470 OHM 5% 1/4W 0603 | 311-1.02KHRCT-ND
S1 | 1 | 3 | SWITCH TACTILE SPST-NO 0.05A 12V | SW1020CT-ND
U1 U2 | 2 | 6 | IC OPAMP QUAD GP RRO 1MHZ SOIC14 | MCP6004T-I/SLCT-ND
U10 | 1 | 3 | IC REG BUCK BOOST ADJ 2A 10WSON | 296-30204-1-ND
U11 | 1 | 3 | IC REG LDO 3.3V 0.25A MCP1703 SOT23A-3 | MCP1703T-3302E/CBCT-ND
U3 | 1 | 3 | IC OPAMP GP 3MHZ RRO 14SOIC | 296-39258-1-ND
U4 | 1 | 3 | IC OPAMP GP 1MHZ RRO MCP6001 SOT23-5 | MCP6001T-I/OTCT-ND
U5 | 1 | 3 | IC ADC 16BIT SPI 860SPS ADS1118 10MSOP | 296-38850-1-ND
U6 | 1 | 3 | IC MCU 32BIT 256KB FLASH ATSAMD21G 48TQFP | ATSAMD21G18A-AUTCT-ND
U7 | 1 | 3 | IC EEPROM 1MBIT 400KHZ 24AA1025 SOIC8 | 24AA1025-I/SN-ND
U8 | 1 | 3 | IC RTC CLK/CALENDAR I2C MCP7940N SOIC8 | MCP7940N-E/SN-ND
U9 | 1 | 3 | IC USB/AC BATT CHRGR MCP73871 20QFN | MCP73871T-2CCI/MLCT-ND
X1 | 1 | 3 | CRYSTAL 16MHZ 30PPM 18pF 4SMD | CTX1206CT-ND
X2 | 1 | 3 | CRYSTAL 32.768kHz 7pF CFS-20632768DZYB | 300-8842-ND

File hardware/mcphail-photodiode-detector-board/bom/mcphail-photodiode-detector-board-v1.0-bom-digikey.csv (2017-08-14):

Ref | Qty | Qty3 | Description | Digikey PN
J1 | 1 | 3 | HEADER MALE 2POS TH 1x02 0.1IN | 952-2262-ND
LED1 LED10 LED2 LED3 LED4 LED5 LED6 LED7 LED8 LED9 | 10 | 30 | PHOTODIODE IR 940NM SMD TEMD5110X01 | 751-1048-1-ND

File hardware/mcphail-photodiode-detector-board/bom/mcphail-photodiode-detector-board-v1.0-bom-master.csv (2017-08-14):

Ref | Qty1 | Qty3 | Footprint | Footprint Library | Symbol | Symbol Library | Datasheet | MF_Name | MF_PN | S1_Name | S1_PN | Type
J1 | 1 | 3 | CONN-HEADER-STRAIGHT-P2.54MM-1x02 | Wickerlib | HEADER-MALE-2POS-TH-1x02-P0.1IN | wickerlib | https://cdn.harwin.com/pdfs/60page140.pdf | Harwin | M20-9990246 | Digikey | 952-2262-ND
LED1 LED10 LED2 LED3 LED4 LED5 LED6 LED7 LED8 LED9 | 10 | 30 | TEMD5110X01 | Wickerlib | PHOTODIODE-IR-940NM-SMD-TEMD5110X01 | wickerlib | http://www.vishay.com/docs/84658/temd5110.pdf | Vishay | TEMD5110X01 | Digikey | 751-1048-1-ND

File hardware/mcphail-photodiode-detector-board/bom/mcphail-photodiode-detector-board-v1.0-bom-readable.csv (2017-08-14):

Ref | Qty | Qty3 | Description | MF | MF_PN | S1 | S1_PN | Type
J1 | 1 | 3 | HEADER MALE 2POS TH 1x02 0.1IN | Harwin | M20-9990246 | Digikey | 952-2262-ND
LED1 LED10 LED2 LED3 LED4 LED5 LED6 LED7 LED8 LED9 | 10 | 30 | PHOTODIODE IR 940NM SMD TEMD5110X01 | Vishay | TEMD5110X01 | Digikey | 751-1048-1-ND

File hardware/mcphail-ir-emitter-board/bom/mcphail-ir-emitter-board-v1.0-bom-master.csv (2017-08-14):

Ref | Qty1 | Qty3 | Footprint | Footprint Library | Symbol | Symbol Library | Datasheet | MF_Name | MF_PN | S1_Name | S1_PN | Type
J1 | 1 | 3 | CONN-HEADER-STRAIGHT-P2.54MM-1x02 | Wickerlib | HEADER-MALE-2POS-TH-1x02-P0.1IN | wickerlib | https://cdn.harwin.com/pdfs/60page140.pdf | Harwin | M20-9990246 | Digikey | 952-2262-ND
LED1 LED10 LED2 LED3 LED4 LED5 LED6 LED7 LED8 LED9 | 10 | 30 | LED-D5MM-2PIN-SH4356 | Wickerlib | LED-IR-850NM-2PIN-TH-SFH4356 | wickerlib | http://www.mouser.com/ds/2/311/SFH%204356 | %20Lead%20(Pb%20Free%20Product%20-%20RoHS%20Compliant-532102.pdf | OSRAM Opto | SFH 4356 | Mouser | 720-SFH4356

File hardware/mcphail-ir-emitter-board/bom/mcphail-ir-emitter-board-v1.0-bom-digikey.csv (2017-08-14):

Ref | Qty | Qty3 | Description | Digikey PN
J1 | 1 | 30 | HEADER MALE 2POS TH 1x02 0.1IN | 952-2262-ND

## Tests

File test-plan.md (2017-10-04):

## Test Plan Outline

- Bring up the main board, verify circuit routing and behavior for each of the following sections:

  - Power
  - Sensor Processing (Analog)
  - Microcontroller (Digital)
  - USB communication + debugging
  - Offboard sensors

- Read data in from both sensors through the analog circuitry at different rates.

- Compare the 16-bit and 14-bit data paths at the different sampling rates.

- Figure out which libraries exist, including licensing requirements, and which we'll need to write.

- Commit to a toolchain (Arduino or Atmel Studio 7) based on the libraries and development process.

- Work out the actual sampling/acquisition code.

- Based on the initial analog circuitry tests without insects, review amplifiers and make any changes. 

- Conduct insect tests in box with one type of insect at different sampling rates with both sensors to compare.

- Explore other compatible sensors (reciever and emitter) combinations, based on these results. 

- Adjust physical sensor boards for the trap's physical assembly, adding mounting holes or changing shape. 

- Select 14-bit or 16-bit analog circuitry path and remove the unused one from the board to have a simplified main board.

- Adjust the main board shape for the trap's physical assembly, adding mounting holes or changing shape.

- Build three full assemblies and place in test box for reproducibility with single insect.

- Test reproducibility over time in the lab with controlled changes in ambient temperature, windy conditions (increased air flow, trap swaying or bouncing), and other expected environmental conditions.

- Identify needed analog circuitry or sensor changes based on reproducitility tests. 

- Make physical adjustments to the board if necessary. 

- Iterate on circuit and physical changes until the reproducibility is stable, even if accuracy is not good.

- Introduce other insects to rule out false positives. Move to accuracy testing. 

- Iterate on circuit and physical changes until accuracy is acceptable across all three test units in the lab. 

- Move outdoors for field testing.

- Once device is reliably detecting the correct insect in the lab, wire in the existing cellular breakout board and verify overnight that it texts the count after dark.

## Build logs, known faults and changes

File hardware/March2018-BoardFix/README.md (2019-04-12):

# March 2018 Board fix
Once we assembled the boards based on the initial design, we found we were unble to communicate with the board, and so could not even install a boot loader. 

Our initial fix was to put the analog circuit onto a separate board that we could plug into an Arduino. The objective was to just get *something* working so we could demonstrate it to people.

After the switch to the Arduino in early March 2018, the circuit still didn't work, so we brought it to a local electronic engineer, who diagnosed and fixed the problem. The results of that investigation are in this directory.

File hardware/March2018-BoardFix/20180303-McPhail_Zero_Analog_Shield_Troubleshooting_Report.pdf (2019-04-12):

Date: | 2018.03.03
Project: | Troubleshooting and Testing of McPhail Zero Analog Shield, v1.0
Author: | Jared Rees (rees.jared@gmail.com)

There seems to be only one major issue with the design; the connection between R21 and C21 needs to be tied to ground. The combined effect of R20, R21, C21, and U3B is to provide a reference voltage halfway between our supply voltage (3.3V) and ground. The output of U3B should be 3.3V/2, or 1.65V. With the bottom side of C21 and R21 floating, the output of U3B was 3.3V. Consequently, the outputs of U3A and U3D were also at 3.3V. Here is the corrected schematic:

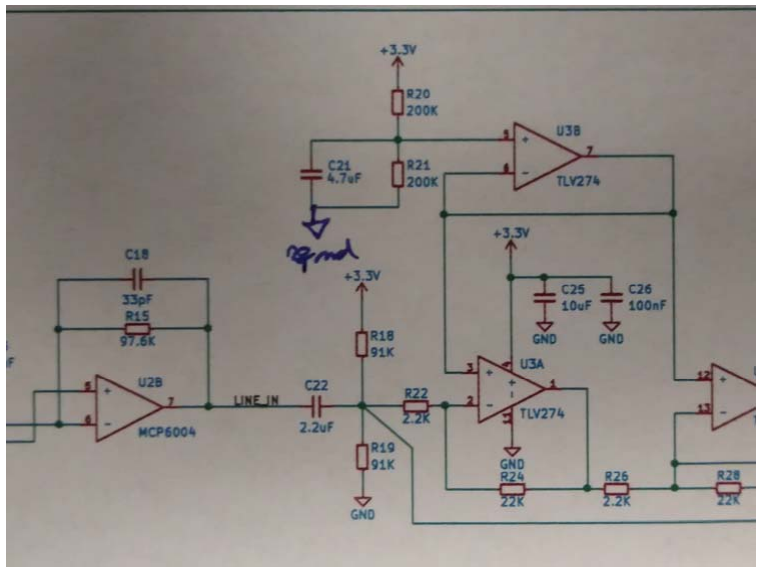
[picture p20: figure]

To fix the issue, I soldered a magnet wire from the bottom of C21 to ground (accessed at the bottom of C25). I recommend an alternative connection by scratching off a bit of the soldermask next to the bottom of C21 to expose the ground plane and soldering directly. This method should help reduce noise. However, I wasn’t about to do this without your permission. Below is a picture of my mod:

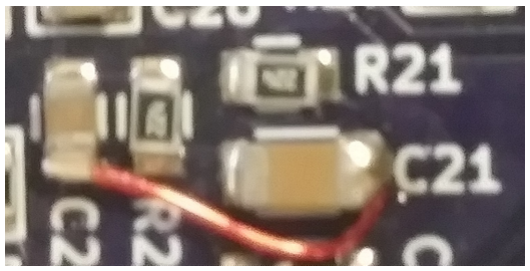
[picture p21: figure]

Once this was fixed, I could see normal DC outputs of the op‐amps. To test the AC response of the system, I decided to remove the detector board and inject my own test signal. I used a function generator set for 300Hz and a 500mV peak‐to‐peak sinewave. I put a 100K resistor on the frontend of the input (pin 1 of J1) to roughly match the current input of the photodiodes. Below is a screenshot from an oscilloscope I used to monitor everything. The yellow channel is the output of my function generator (going into the 100K resistor). The blue channel is the signal scoped at the A0 pin. Note that there is some 60Hz noise coupled into the system. I don’t know how much of this was injected by my setup (which is in a rather noisy lab) and how much of this would have been picked‐up anyways from the board design.

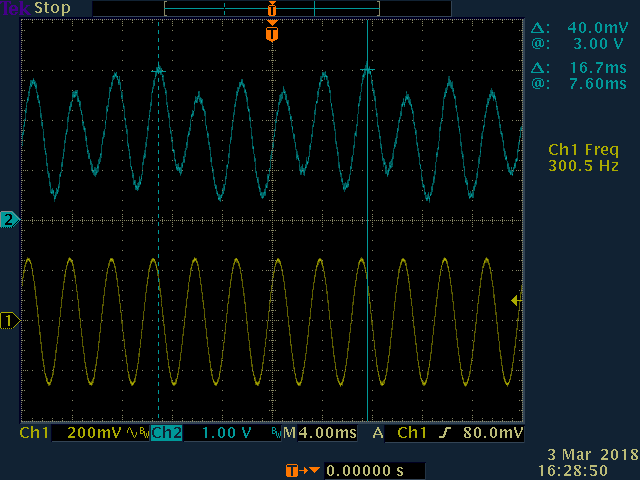
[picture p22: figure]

With the same setup, I wrote and executed some test code (20180303‐Fly_Trap_Test_Code) to capture the waveforms on pins A0 through A2. Please look at the data and graphs in 20180303‐ McPhail_Zero_Analog_Shield_Test_Data.xlsx. In Test 1, I captured all three channels with a time between samples of about 2 ms. In Test 2, I only captured samples from A0. This allowed me to decrease the time between samples to about 500 us. From the graphs, you can see that the input waveform is present on the output, so the board seems to be functioning normally and my basic code can read it. Note that I did not have the oscilloscope hooked‐up to the board when I did this test, so any noise in the system was either picked up through my function generator output or from the PCB.

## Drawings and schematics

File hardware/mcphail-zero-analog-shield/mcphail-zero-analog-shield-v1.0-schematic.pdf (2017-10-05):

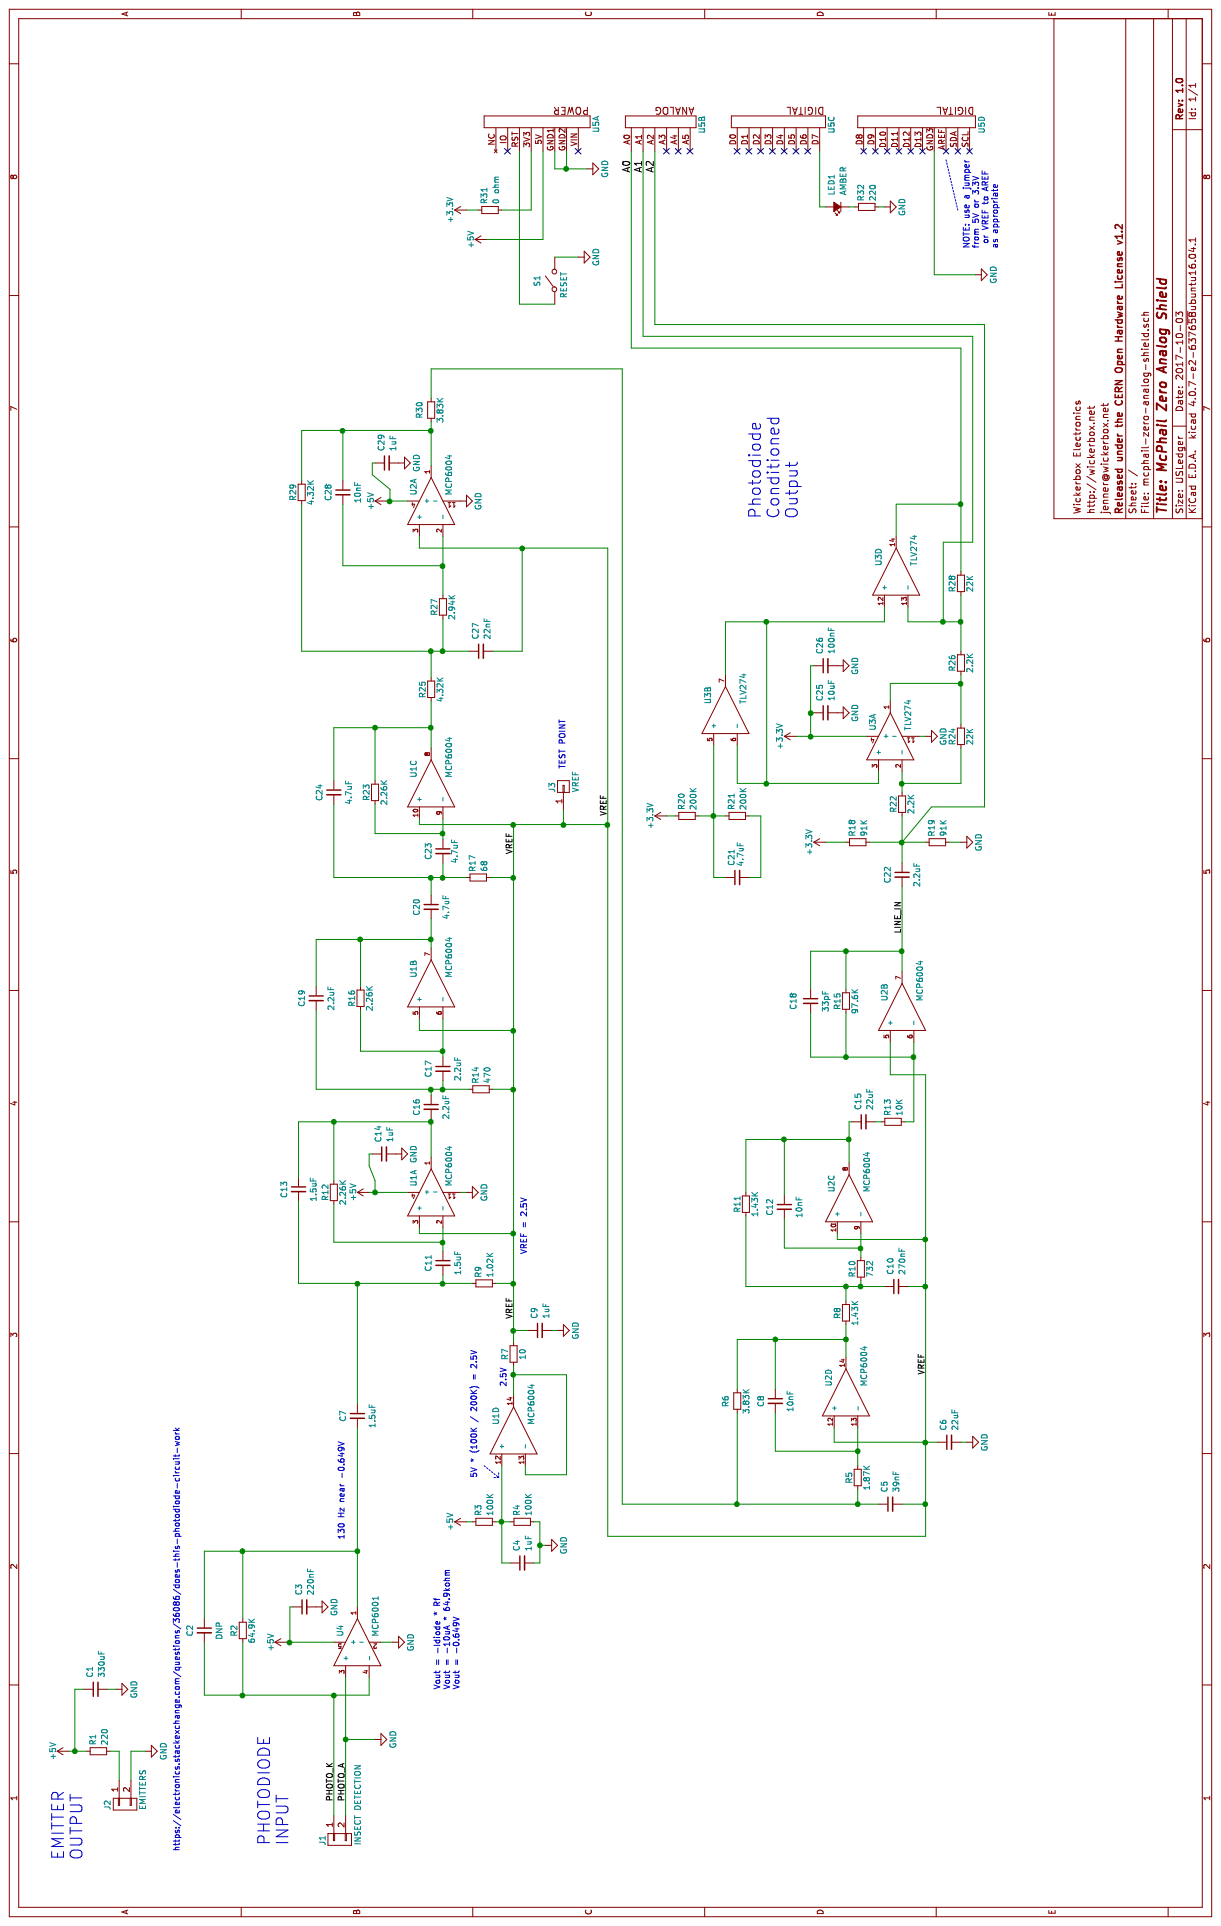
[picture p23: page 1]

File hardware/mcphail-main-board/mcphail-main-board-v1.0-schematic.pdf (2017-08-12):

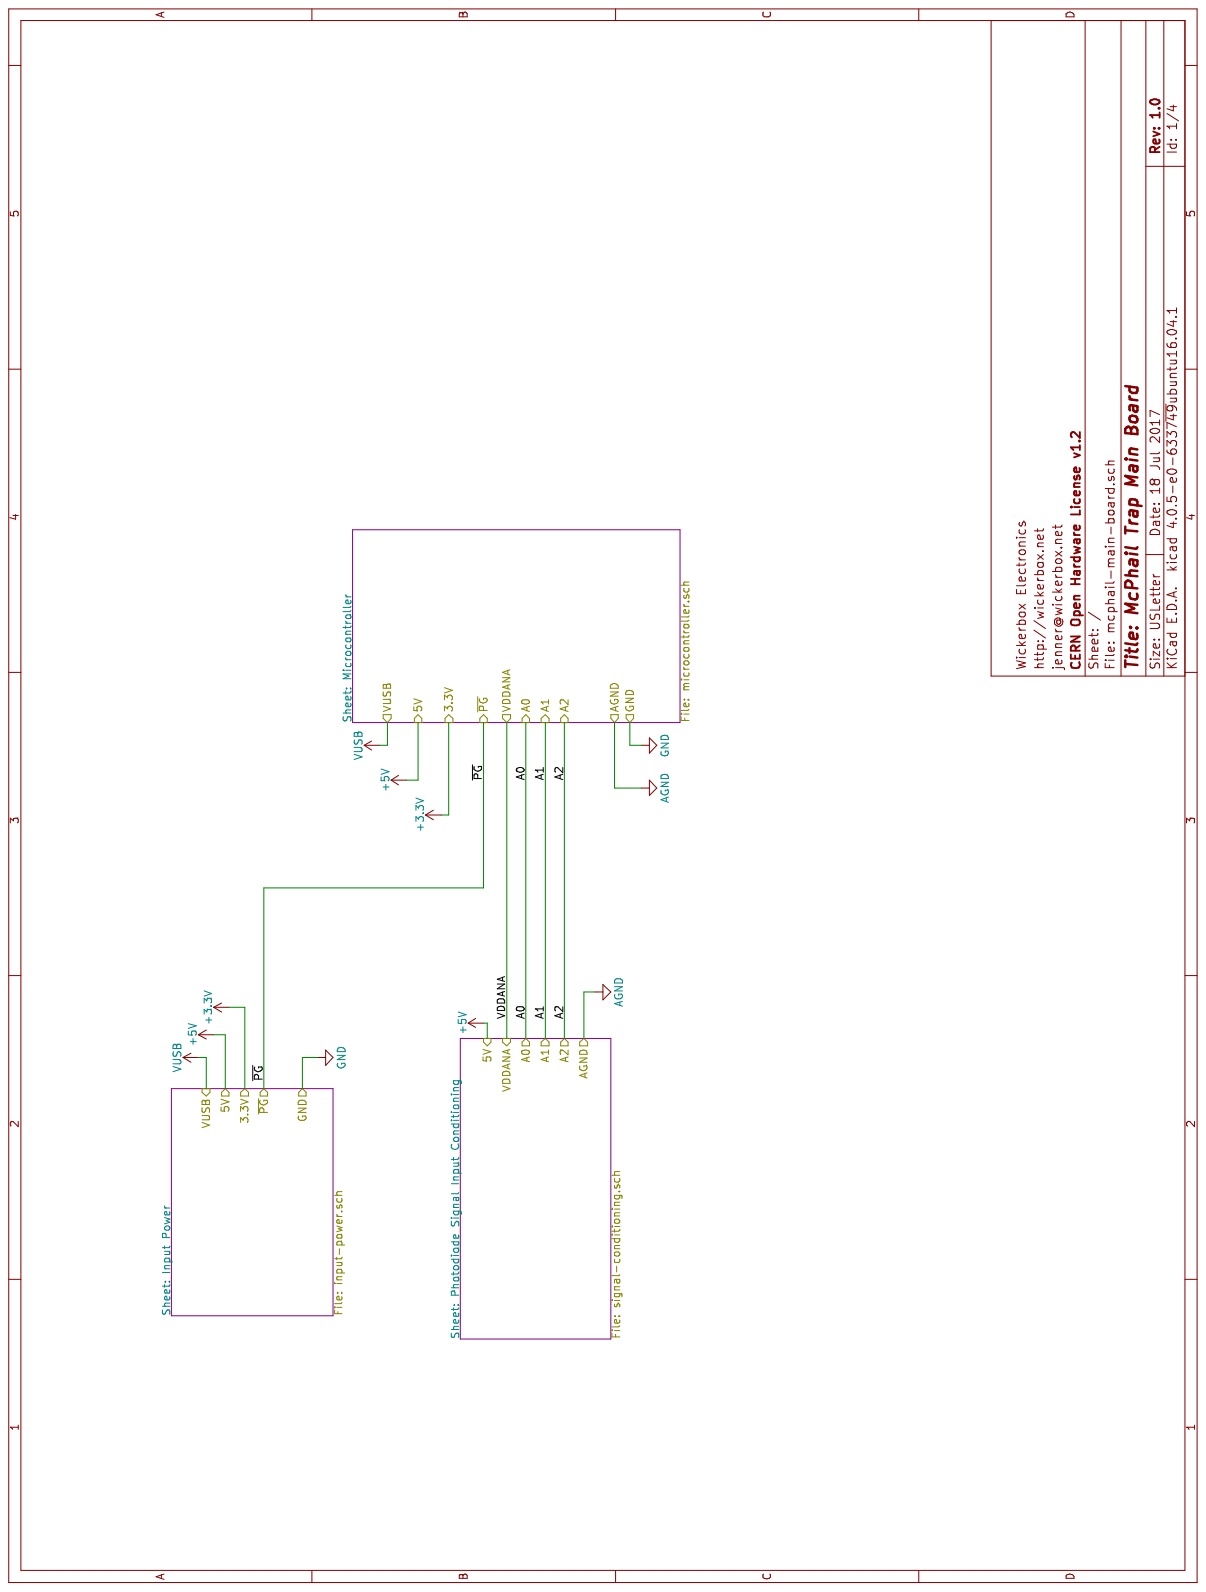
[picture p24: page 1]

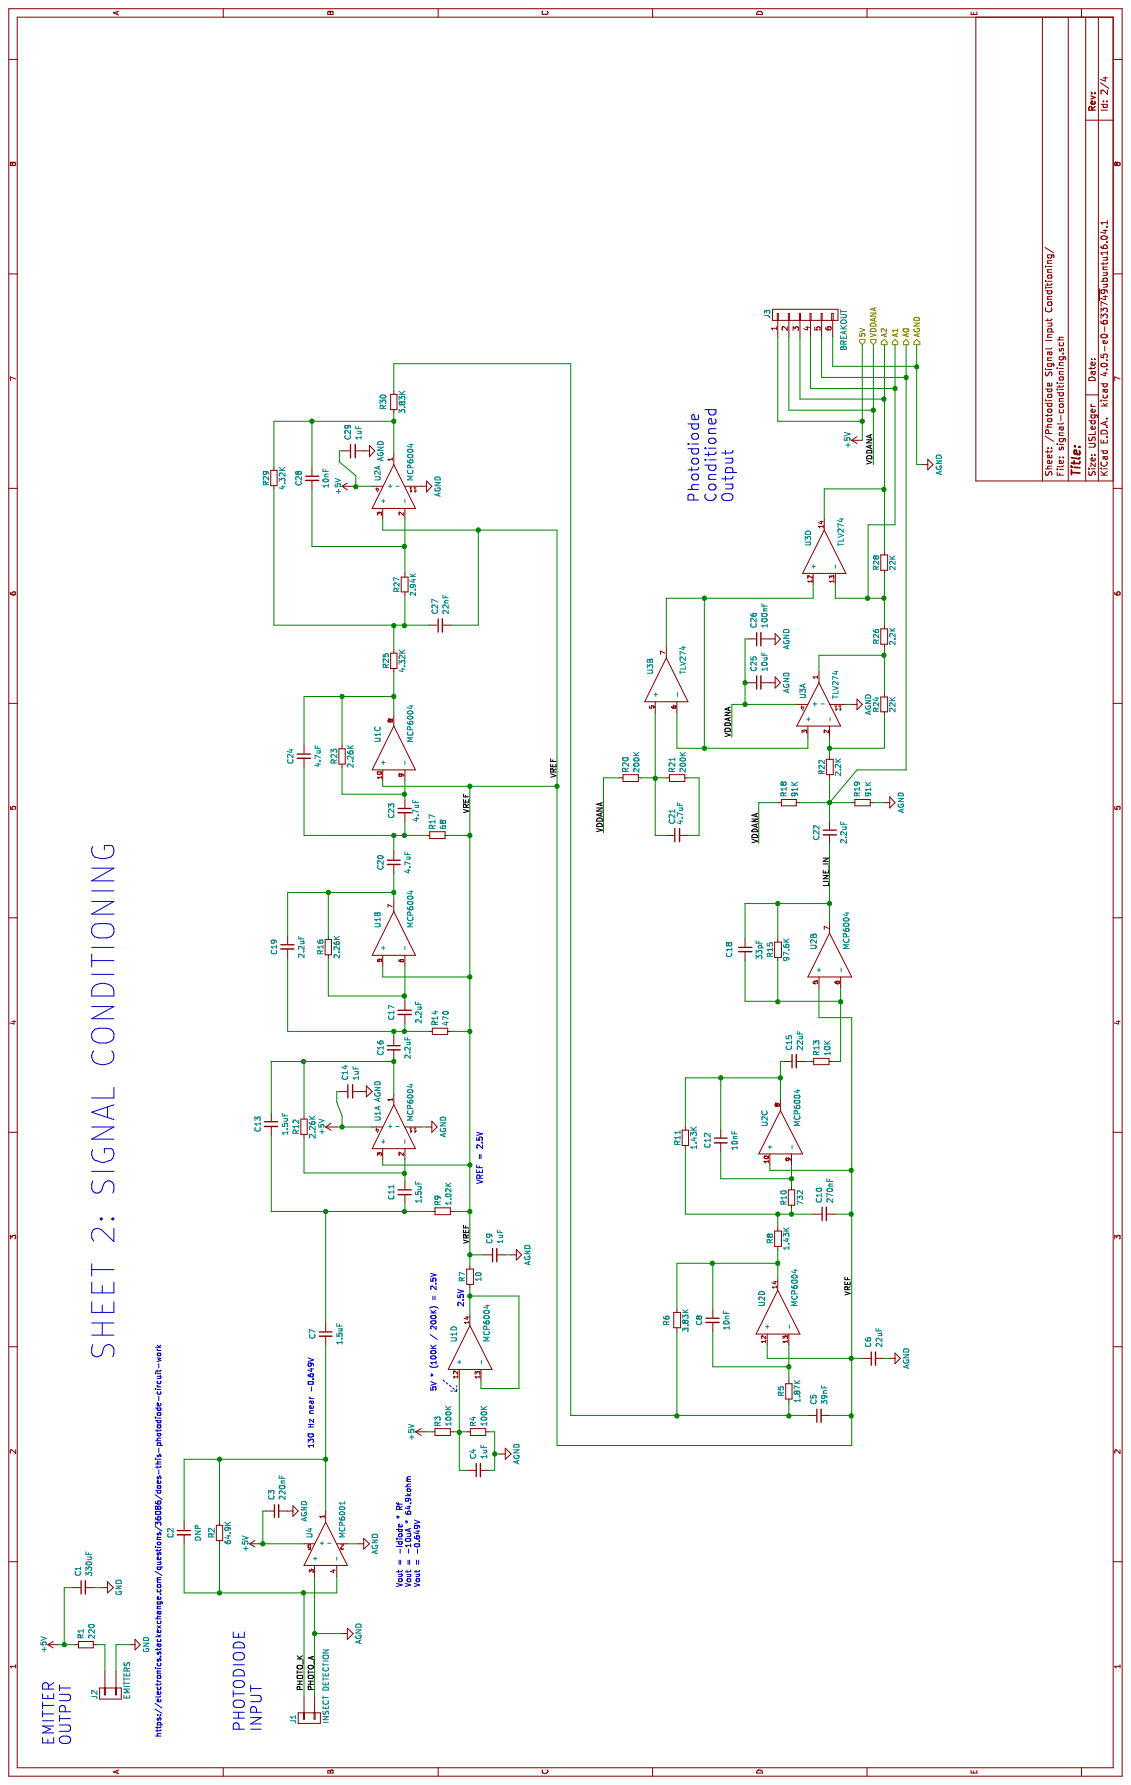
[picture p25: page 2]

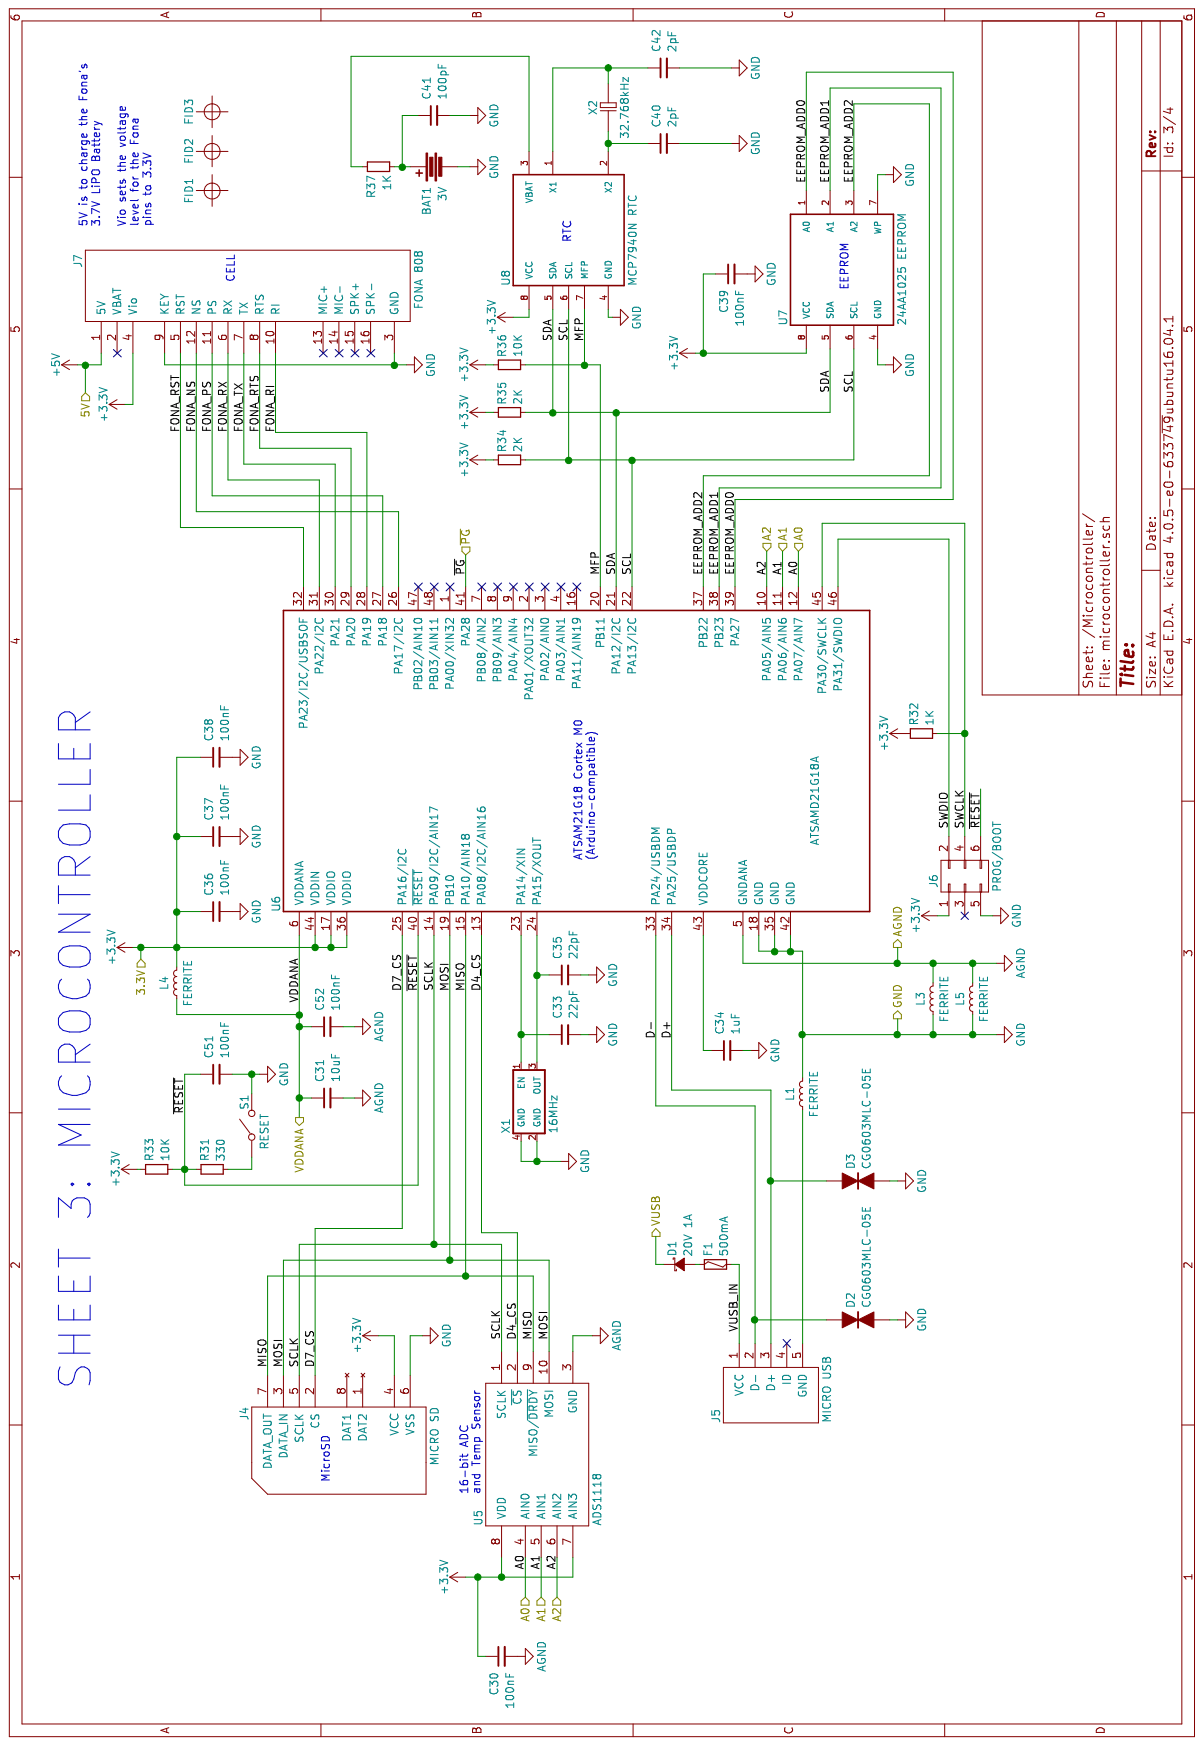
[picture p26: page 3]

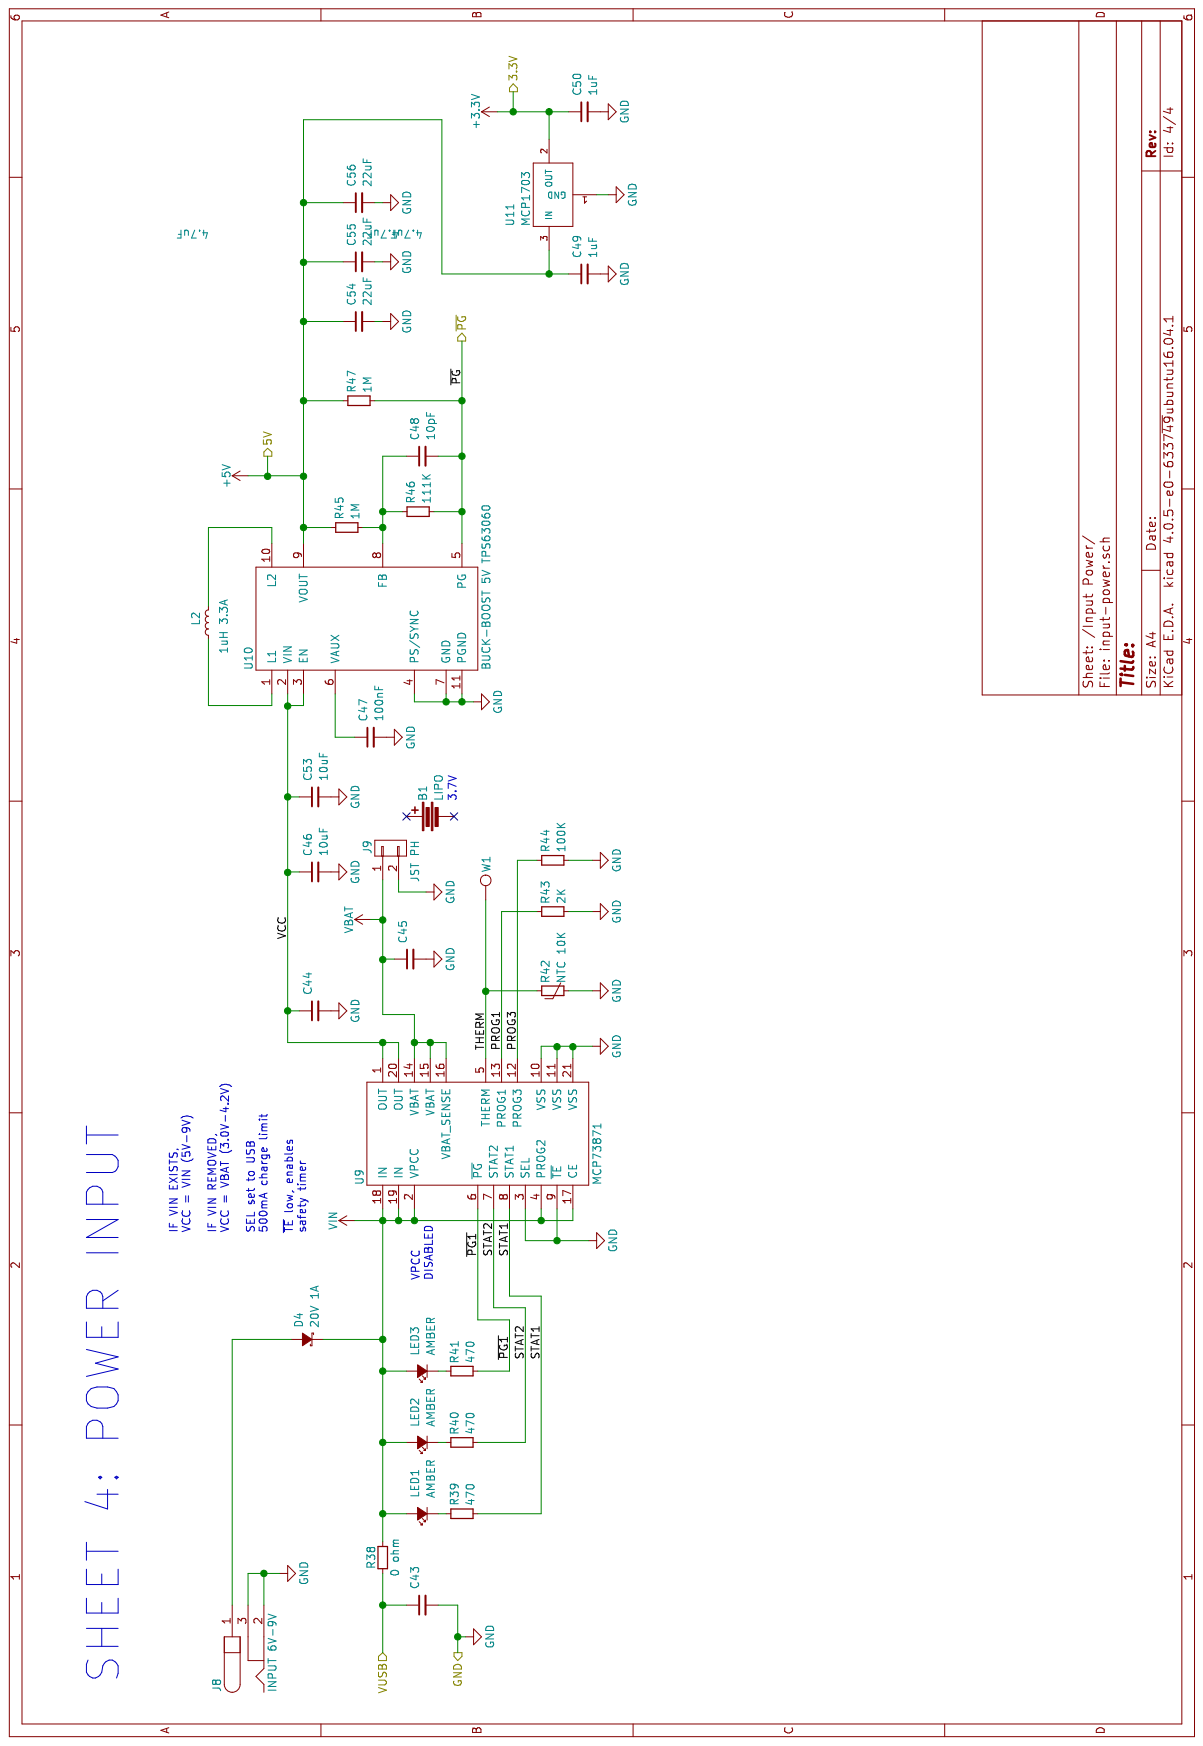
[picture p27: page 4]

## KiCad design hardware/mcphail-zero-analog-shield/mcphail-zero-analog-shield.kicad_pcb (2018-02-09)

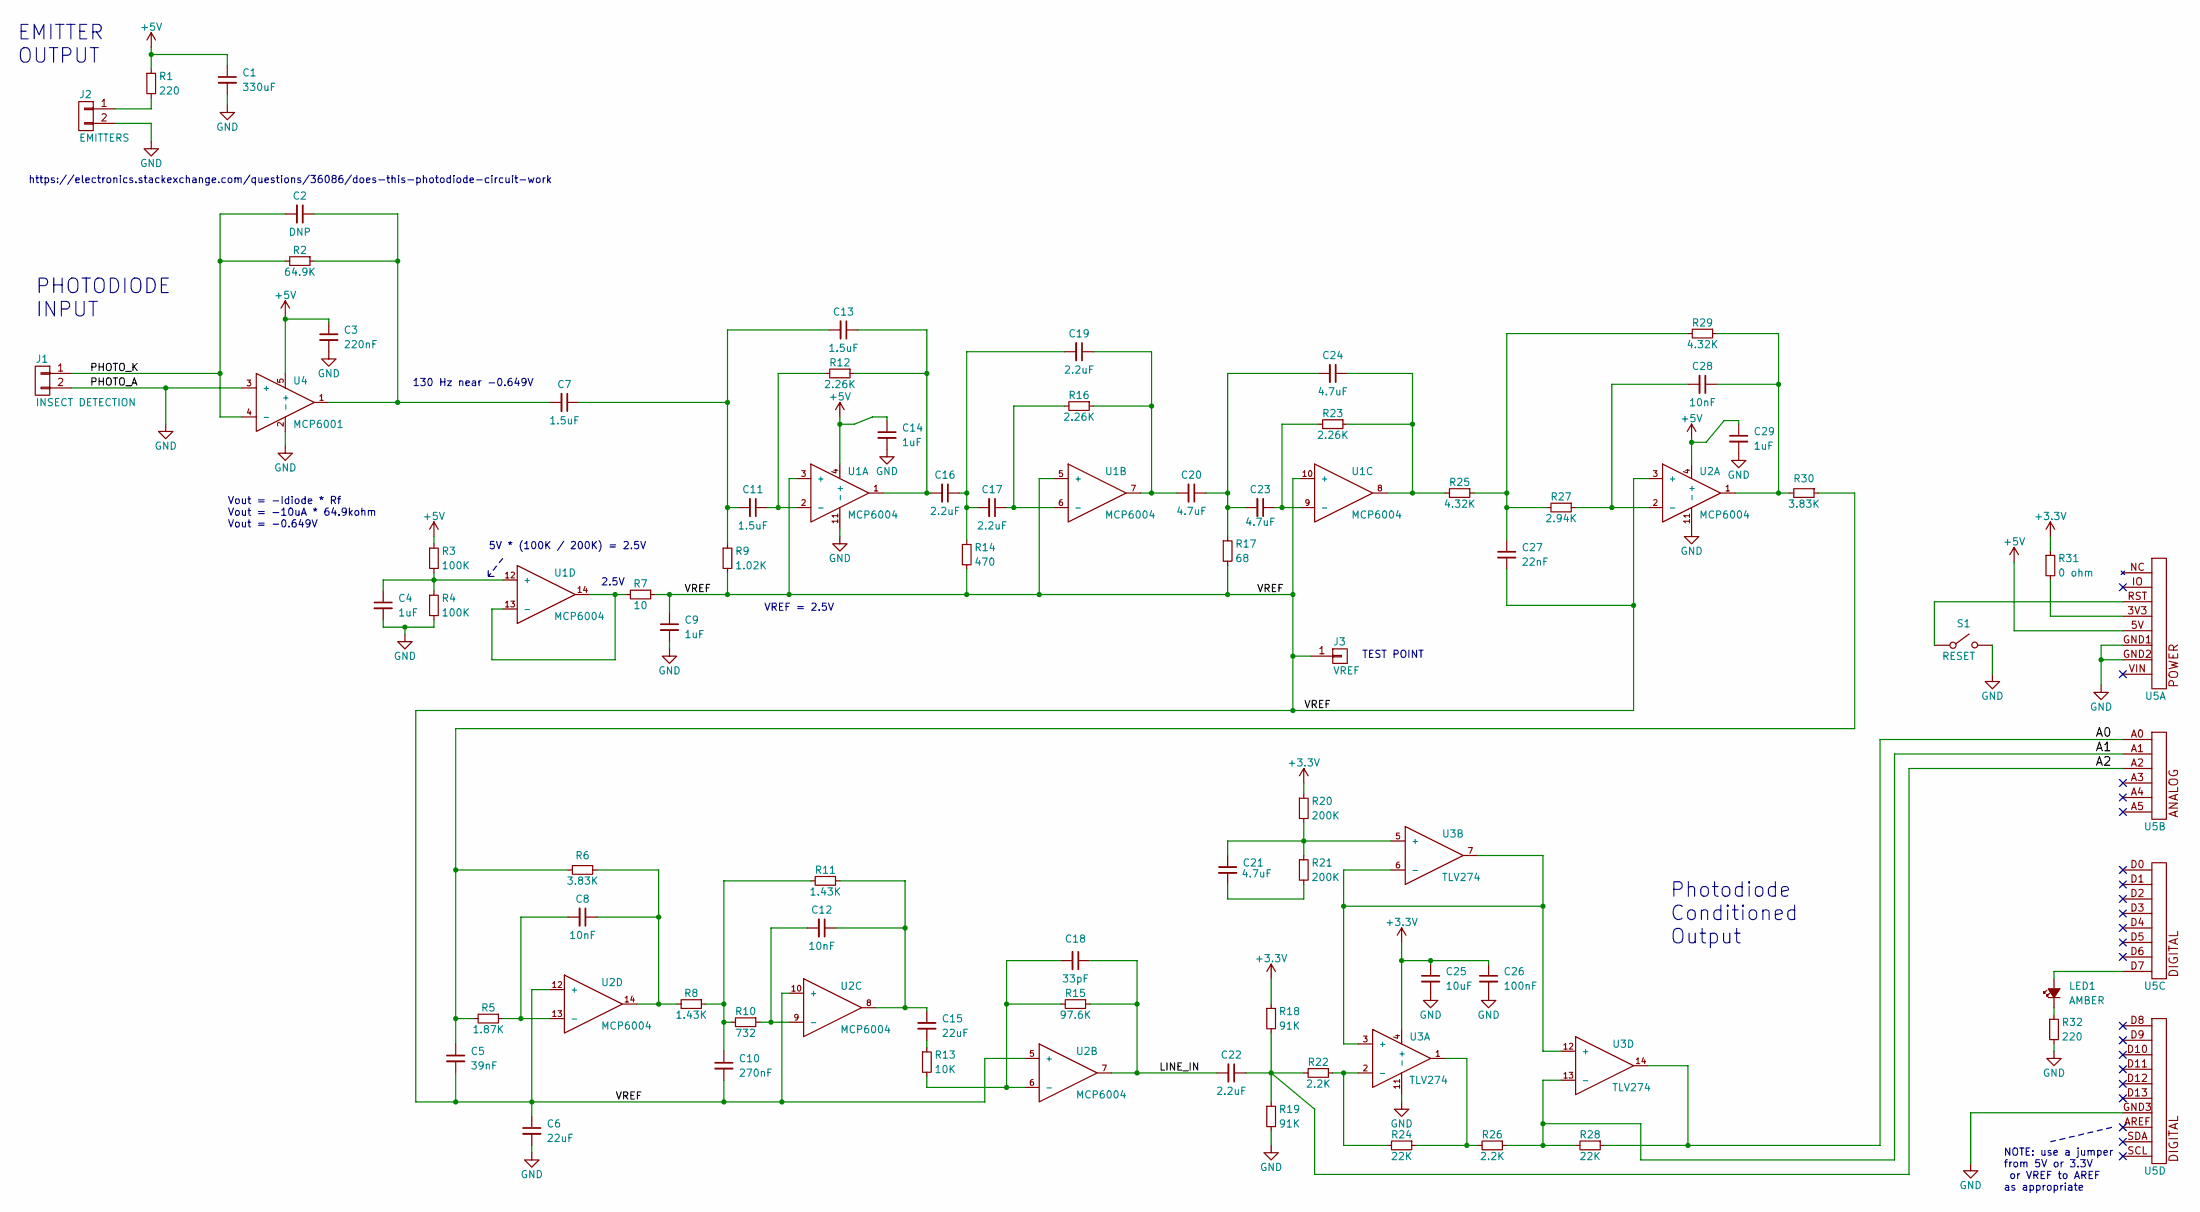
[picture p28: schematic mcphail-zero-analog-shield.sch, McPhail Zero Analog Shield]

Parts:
C1: 330uF; CAP-RADIAL-ALUM-D6.3MM-P2.5MM
C2: DNP; RLC-1206-SMD
C3: 220nF; RLC-0603-SMD
C4, C9, C14, C29: 1uF; RLC-0805-SMD
C5: 39nF; RLC-0603-SMD
C6, C15: 22uF; RLC-1210-SMD
C7, C11, C13: 1.5uF; RLC-1206-SMD
C8, C12, C28: 10nF; RLC-0603-SMD
C10: 270nF; RLC-0603-SMD
C16, C17, C19, C22: 2.2uF; RLC-0805-SMD
C18: 33pF; RLC-0603-SMD
C20, C21, C23, C24: 4.7uF; RLC-1206-SMD
C25: 10uF; RLC-0805-SMD
C26: 100nF; RLC-0603-SMD
C27: 22nF; RLC-0603-SMD
J1: INSECT DETECTION; CONN-ONSHORE-SCREW-GREEN-2PIN-TH
J2: EMITTERS; CONN-ONSHORE-SCREW-GREEN-2PIN-TH
J3: VREF; CONN-HEADER-STRAIGHT-P2.54MM-1x01
LED1: AMBER; LED-0603-SMD
R1, R32: 220; RLC-0603-SMD
R2: 64.9K; RLC-0603-SMD
R3, R4: 100K; RLC-0603-SMD
R5: 1.87K; RLC-0603-SMD
R6, R30: 3.83K; RLC-0603-SMD
R7: 10; RLC-0603-SMD
R8, R11: 1.43K; RLC-0603-SMD
R9: 1.02K; RLC-0603-SMD
R10: 732; RLC-0603-SMD
R12, R16, R23: 2.26K; RLC-0603-SMD
R13: 10K; RLC-0603-SMD
R14: 470; RLC-0603-SMD
R15: 97.6K; RLC-0603-SMD
R17: 68; RLC-0603-SMD
R18, R19: 91K; RLC-0603-SMD
R20, R21: 200K; RLC-0805-SMD
R22, R26: 2.2K; RLC-0603-SMD
R24, R28: 22K; RLC-0603-SMD
R25, R29: 4.32K; RLC-0603-SMD
R27: 2.94K; RLC-0603-SMD
R31: 0 ohm; RLC-0603-SMD
S1: RESET; SWITCH-OMRON-MOMENTARY-SMD-B3U-1000P
U1, U2: MCP6004; SOIC-14-3.9x8.7MM-P1.27MM
U3: TLV274; SOIC-14-3.9x8.7MM-P1.27MM
U4: MCP6001; SOT-23-5
U5: ARDUINO-101-SHIELD; ARDUINO-UNO-SHIELD

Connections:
+3V3: C25.1, C26.1, R18.1, R20.1, R31.1, U3.4 (+)
+5V: C1.1, C3.1, C14.1, C29.1, R1.1, R3.1, U1.4 (+), U2.4 (+), U4.5 (+), U5.5V
/A0: R28.1, U3.14, U5.A0
/A1: R26.1, R28.2, U3.13 (-), U5.A1
/A2: C22.1, R18.2, R19.1, R22.2, U5.A2
/LINE_IN: C18.1, C22.2, R15.1, U2.7
/PHOTO_K: C2.2, J1.1, R2.2, U4.4 (-)
/VREF: C5.2, C6.1, C9.1, C10.2, C27.2, J3.1, R7.1, R9.2, R14.2, R17.2, U1.3 (+), U1.5 (+), U1.10 (+), U2.3 (+), U2.5 (+), U2.10 (+), U2.12 (+)
GND: C1.2, C3.2, C4.2, C6.2, C9.2, C14.2, C25.2, C26.2, C29.2, J1.2, J2.2, R4.2, R19.2, R32.2, S1.2, U1.11 (-), U2.11 (-), U3.11 (-), U4.2 (-), U4.3 (+), U5.GND1 (GND), U5.GND2 (GND), U5.GND3 (GND)
unnamed: C2.1, C7.2, R2.1, U4.1
unnamed: C4.1, R3.2, R4.1, U1.12 (+)
unnamed: C5.1, R5.2, R6.2, R30.1
unnamed: C8.1, R6.1, R8.2, U2.14
unnamed: C8.2, R5.1, U2.13 (-)
unnamed: C10.1, R8.1, R10.2, R11.2
unnamed: C11.1, R12.2, U1.2 (-)
unnamed: C7.1, C11.2, C13.2, R9.1
unnamed: C12.1, C15.1, R11.1, U2.8
unnamed: C12.2, R10.1, U2.9 (-)
unnamed: C13.1, C16.2, R12.1, U1.1
unnamed: C15.2, R13.1
unnamed: C16.1, C17.2, C19.2, R14.1
unnamed: C17.1, R16.2, U1.6 (-)
unnamed: C18.2, R13.2, R15.2, U2.6 (-)
unnamed: C19.1, C20.2, R16.1, U1.7
unnamed: C20.1, C23.2, C24.2, R17.1
unnamed: C21.1, R20.2, R21.1, U3.5 (+)
unnamed: C21.2, R21.2
unnamed: C23.1, R23.2, U1.9 (-)
unnamed: C24.1, R23.1, R25.2, U1.8
unnamed: C27.1, R25.1, R27.2, R29.2
unnamed: C28.1, R29.1, R30.2, U2.1
unnamed: C28.2, R27.1, U2.2 (-)
unnamed: J2.1, R1.2
unnamed: LED1.1 (K), R32.1
unnamed: LED1.2 (A), U5.D7
unnamed: R7.2, U1.13 (-), U1.14
unnamed: R22.1, R24.2, U3.2 (-)
unnamed: R24.1, R26.2, U3.1
unnamed: R31.2, U5.3V3 (3.3V)
unnamed: S1.1, U5.RST (RESET)
unnamed: U3.3 (+), U3.6 (-), U3.7, U3.12 (+)

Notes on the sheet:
PHOTODIODE INPUT
Photodiode Conditioned Output
EMITTER OUTPUT
Vout = -Idiode * Rf Vout = -10uA * 64.9kohm Vout = -0.649V
https://electronics.stackexchange.com/questions/36086/does-this-photodiode-circuit-work
5V * (100K / 200K) = 2.5V
2.5V
VREF = 2.5V
130 Hz near -0.649V
NOTE: use a jumper from 5V or 3.3V or VREF to AREF as appropriate
TEST POINT

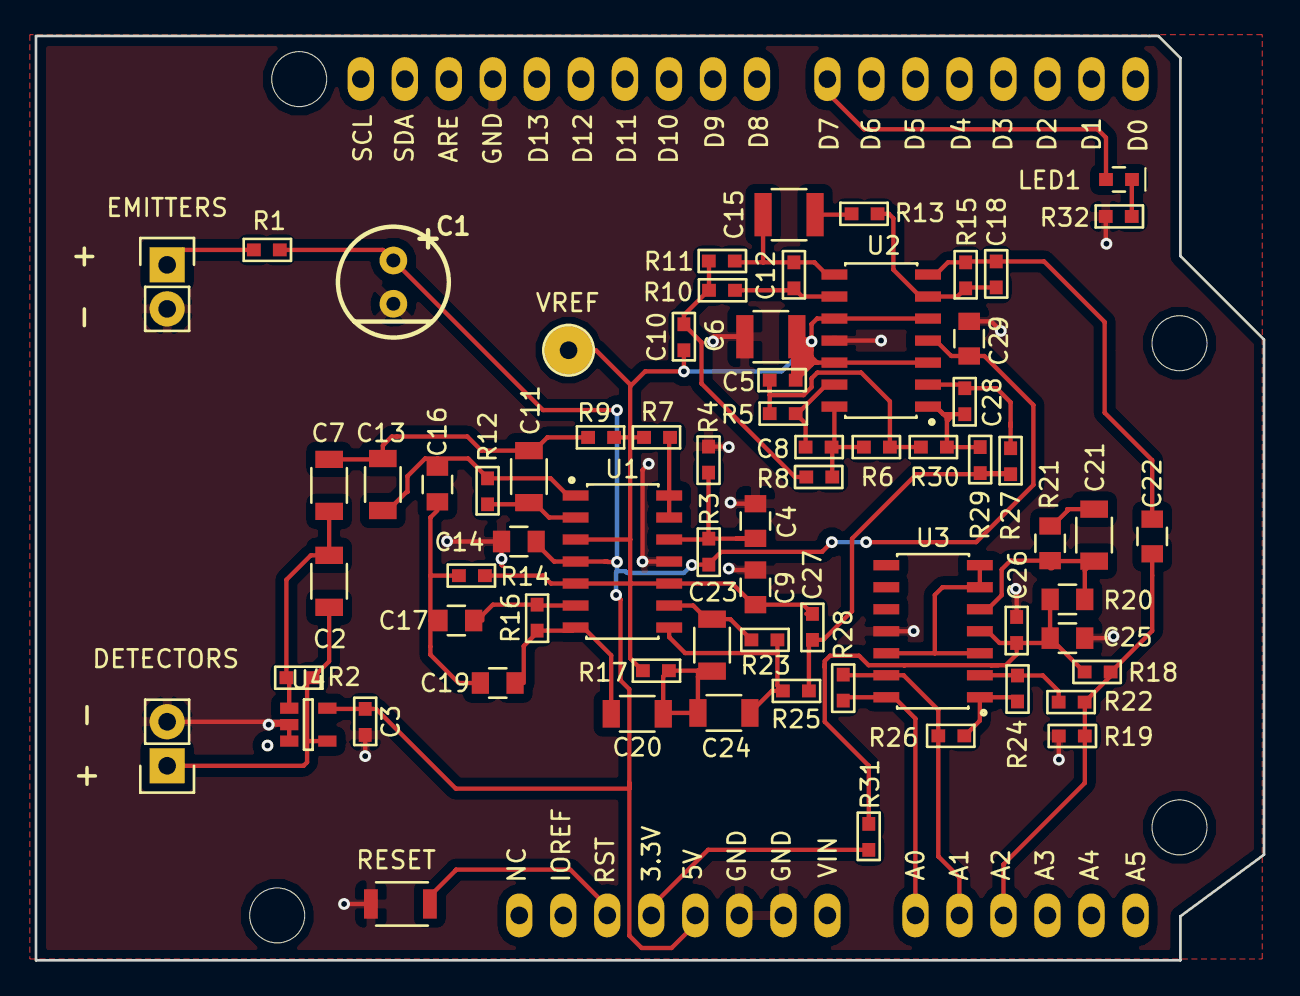
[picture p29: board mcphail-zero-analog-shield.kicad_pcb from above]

Board: 2 copper layers, 70.9 x 53.3 mm, 71 parts (0 on the bottom side), 42 nets.

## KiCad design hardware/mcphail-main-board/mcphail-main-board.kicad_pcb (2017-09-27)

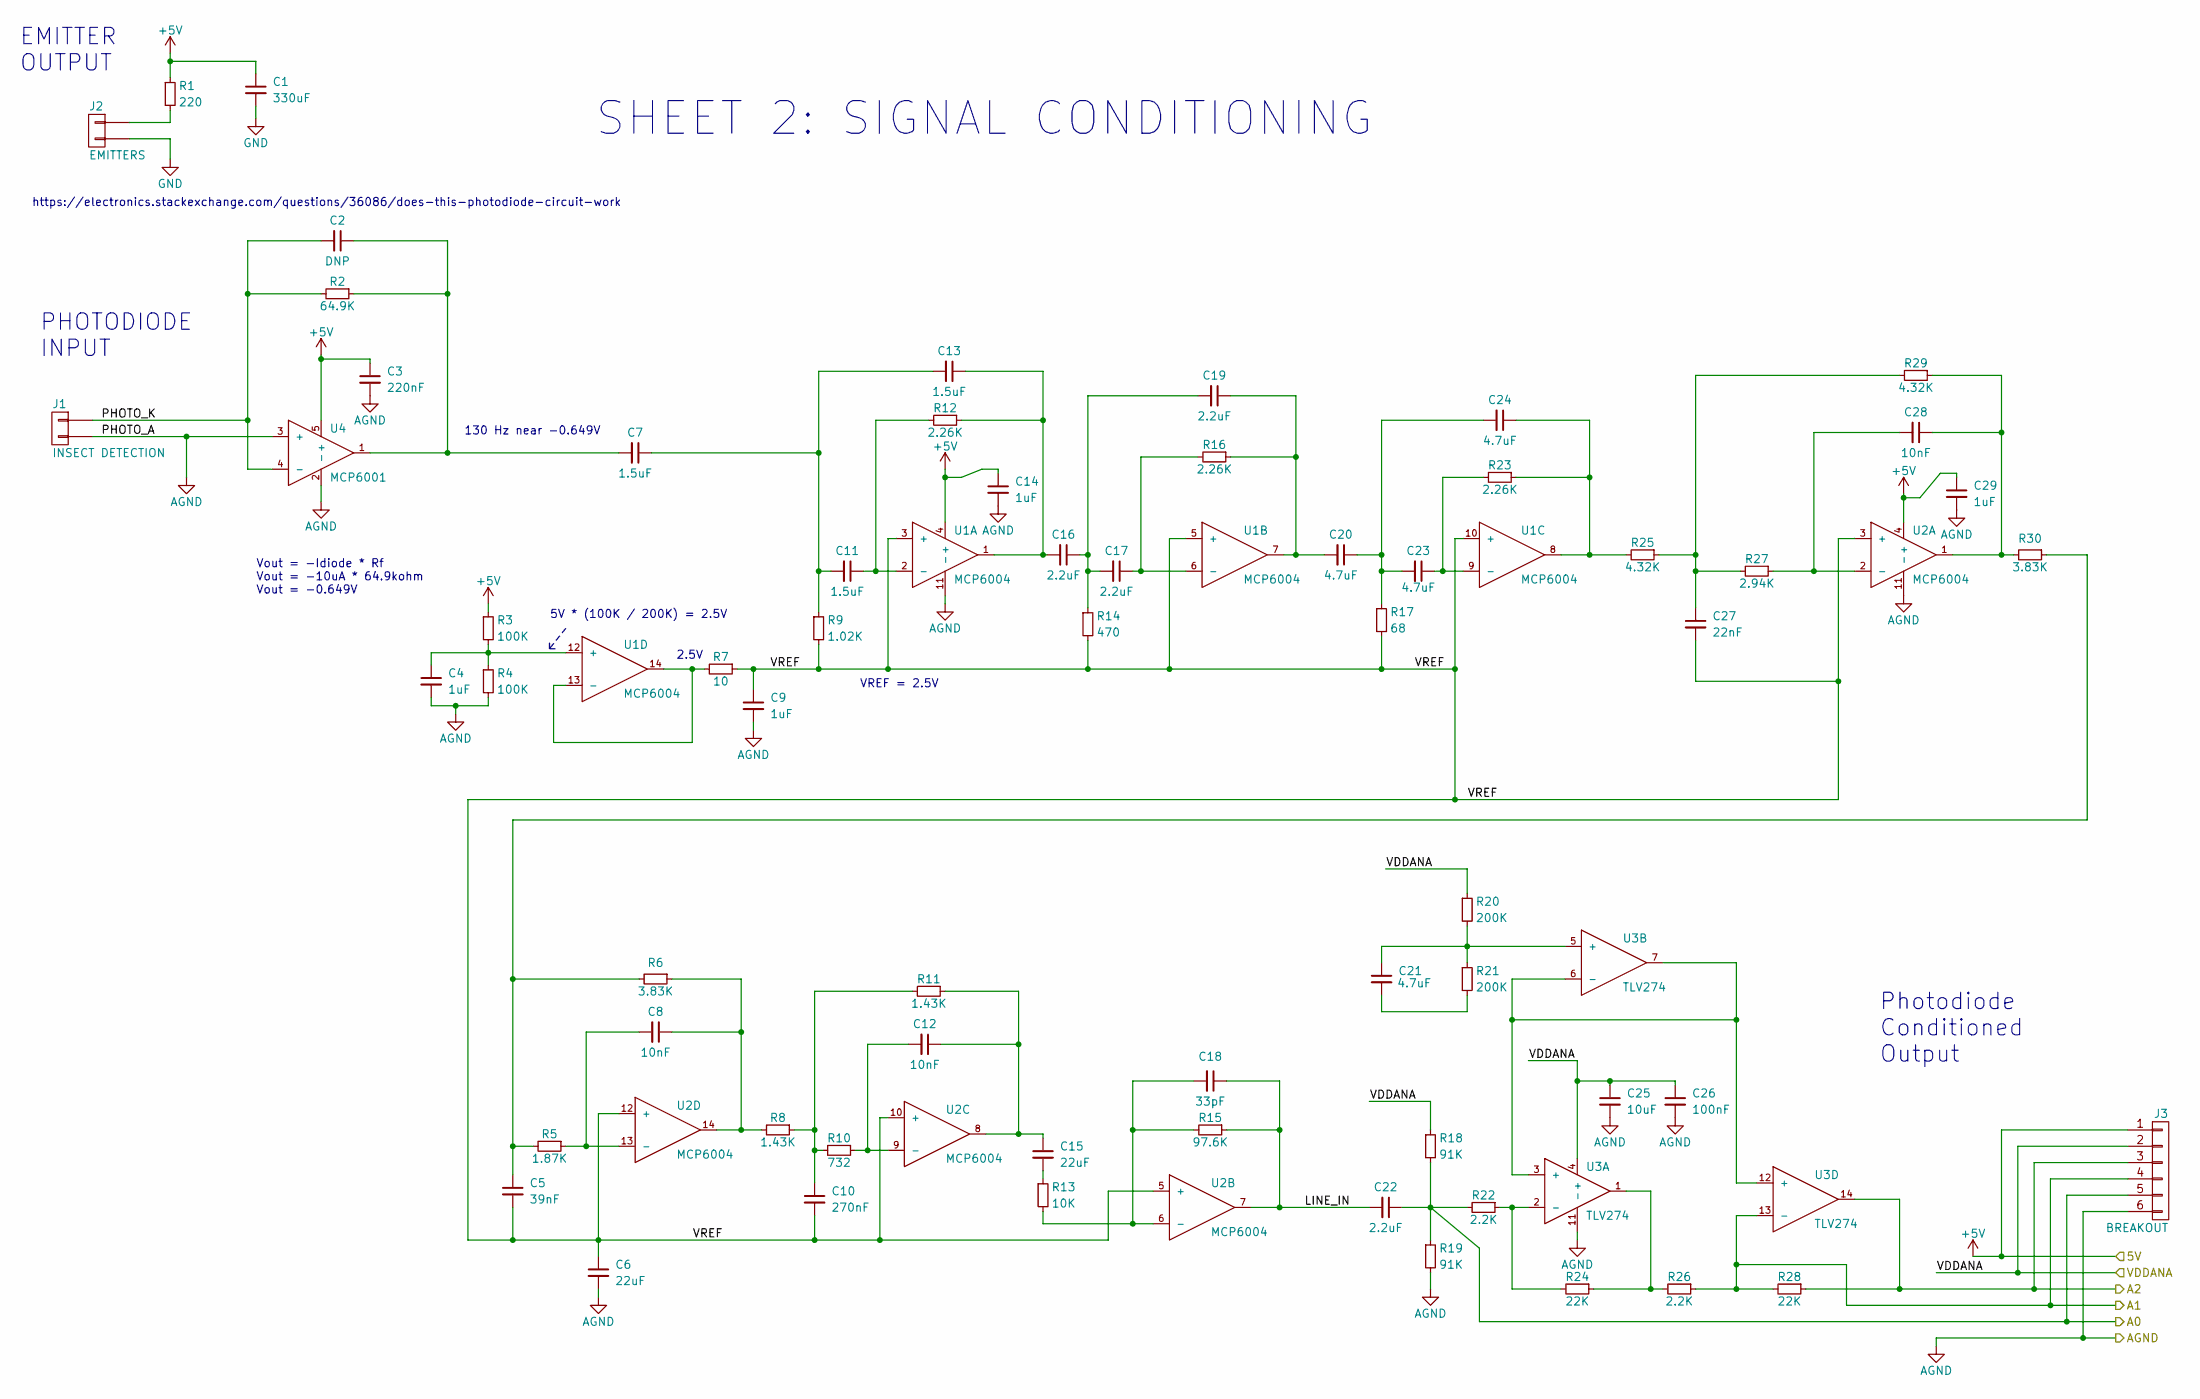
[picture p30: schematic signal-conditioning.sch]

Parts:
C1: 330uF; CAP-RADIAL-ALUM-D6.3MM-P2.5MM
C2: DNP; RLC-1206-SMD
C3: 220nF; RLC-0603-SMD
C4, C9, C14, C29: 1uF; RLC-0805-SMD
C5: 39nF; RLC-0603-SMD
C6, C15: 22uF; RLC-1210-SMD
C7, C11, C13: 1.5uF; RLC-1206-SMD
C8, C12, C28: 10nF; RLC-0603-SMD
C10: 270nF; RLC-0603-SMD
C16, C17, C19, C22: 2.2uF; RLC-1210-SMD
C18: 33pF; RLC-0603-SMD
C20, C21, C23, C24: 4.7uF; RLC-1206-SMD
C25: 10uF; RLC-0805-SMD
C26: 100nF; RLC-0603-SMD
C27: 22nF; RLC-0603-SMD
J1: INSECT DETECTION; CONN-HEADER-STRAIGHT-P2.54MM-1x02
J2: EMITTERS; CONN-HEADER-STRAIGHT-P2.54MM-1x02
J3: BREAKOUT; CONN-HEADER-STRAIGHT-P2.54MM-1x06
R1: 220; RLC-0603-SMD
R2: 64.9K; RLC-0603-SMD
R3, R4: 100K; RLC-0603-SMD
R5: 1.87K; RLC-0603-SMD
R6, R30: 3.83K; RLC-0603-SMD
R7: 10; RLC-0603-SMD
R8, R11: 1.43K; RLC-0603-SMD
R9: 1.02K; RLC-0603-SMD
R10: 732; RLC-0603-SMD
R12, R16, R23: 2.26K; RLC-0603-SMD
R13: 10K; RLC-0603-SMD
R14: 470; RLC-0603-SMD
R15: 97.6K; RLC-0603-SMD
R17: 68; RLC-0603-SMD
R18, R19: 91K; RLC-0603-SMD
R20, R21: 200K; RLC-0805-SMD
R22, R26: 2.2K; RLC-0603-SMD
R24, R28: 22K; RLC-0603-SMD
R25, R29: 4.32K; RLC-0603-SMD
R27: 2.94K; RLC-0603-SMD
U1, U2: MCP6004; SOIC-14-3.9x8.7MM-P1.27MM
U3: TLV274; SOIC-14-3.9x8.7MM-P1.27MM
U4: MCP6001; SOT-23-5

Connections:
+5V: C1.1, C3.1, C14.1, C29.1, J3.1, R1.1, R3.1, U1.4 (+), U2.4 (+), U4.5 (+); also elsewhere on the board
/A0: C22.1, J3.5, R18.2, R19.1, R22.2; also elsewhere on the board
/A1: J3.4, R26.1, R28.2, U3.13 (-); also elsewhere on the board
/A2: J3.3, R28.1, U3.14; also elsewhere on the board
/Photodiode Signal Input Conditioning/LINE_IN: C18.1, C22.2, R15.1, U2.7
/Photodiode Signal Input Conditioning/PHOTO_K: C2.2, J1.1, R2.2, U4.4 (-)
/Photodiode Signal Input Conditioning/VREF: C5.2, C6.1, C9.1, C10.2, C27.2, R7.1, R9.2, R14.2, R17.2, U1.3 (+), U1.5 (+), U1.10 (+), U2.3 (+), U2.5 (+), U2.10 (+), U2.12 (+)
/VDDANA: C25.1, C26.1, J3.2, R18.1, R20.1, U3.4 (+); also elsewhere on the board
AGND: C3.2, C4.2, C6.2, C9.2, C14.2, C25.2, C26.2, C29.2, J1.2, J3.6, R4.2, R19.2, U1.11 (-), U2.11 (-), U3.11 (-), U4.2 (-), U4.3 (+); also elsewhere on the board
GND: C1.2, J2.2; also elsewhere on the board
unnamed: C2.1, C7.2, R2.1, U4.1
unnamed: C4.1, R3.2, R4.1, U1.12 (+)
unnamed: C5.1, R5.2, R6.2, R30.1
unnamed: C8.1, R6.1, R8.2, U2.14
unnamed: C8.2, R5.1, U2.13 (-)
unnamed: C10.1, R8.1, R10.2, R11.2
unnamed: C11.1, R12.2, U1.2 (-)
unnamed: C7.1, C11.2, C13.2, R9.1
unnamed: C12.1, C15.1, R11.1, U2.8
unnamed: C12.2, R10.1, U2.9 (-)
unnamed: C13.1, C16.2, R12.1, U1.1
unnamed: C15.2, R13.1
unnamed: C16.1, C17.2, C19.2, R14.1
unnamed: C17.1, R16.2, U1.6 (-)
unnamed: C18.2, R13.2, R15.2, U2.6 (-)
unnamed: C19.1, C20.2, R16.1, U1.7
unnamed: C20.1, C23.2, C24.2, R17.1
unnamed: C21.1, R20.2, R21.1, U3.5 (+)
unnamed: C21.2, R21.2
unnamed: C23.1, R23.2, U1.9 (-)
unnamed: C24.1, R23.1, R25.2, U1.8
unnamed: C27.1, R25.1, R27.2, R29.2
unnamed: C28.1, R29.1, R30.2, U2.1
unnamed: C28.2, R27.1, U2.2 (-)
unnamed: J2.1, R1.2
unnamed: R7.2, U1.13 (-), U1.14
unnamed: R22.1, R24.2, U3.2 (-)
unnamed: R24.1, R26.2, U3.1
unnamed: U3.3 (+), U3.6 (-), U3.7, U3.12 (+)

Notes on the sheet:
PHOTODIODE INPUT
Photodiode Conditioned Output
EMITTER OUTPUT
SHEET 2: SIGNAL CONDITIONING
Vout = -Idiode * Rf Vout = -10uA * 64.9kohm Vout = -0.649V
https://electronics.stackexchange.com/questions/36086/does-this-photodiode-circuit-work
5V * (100K / 200K) = 2.5V
2.5V
VREF = 2.5V
130 Hz near -0.649V

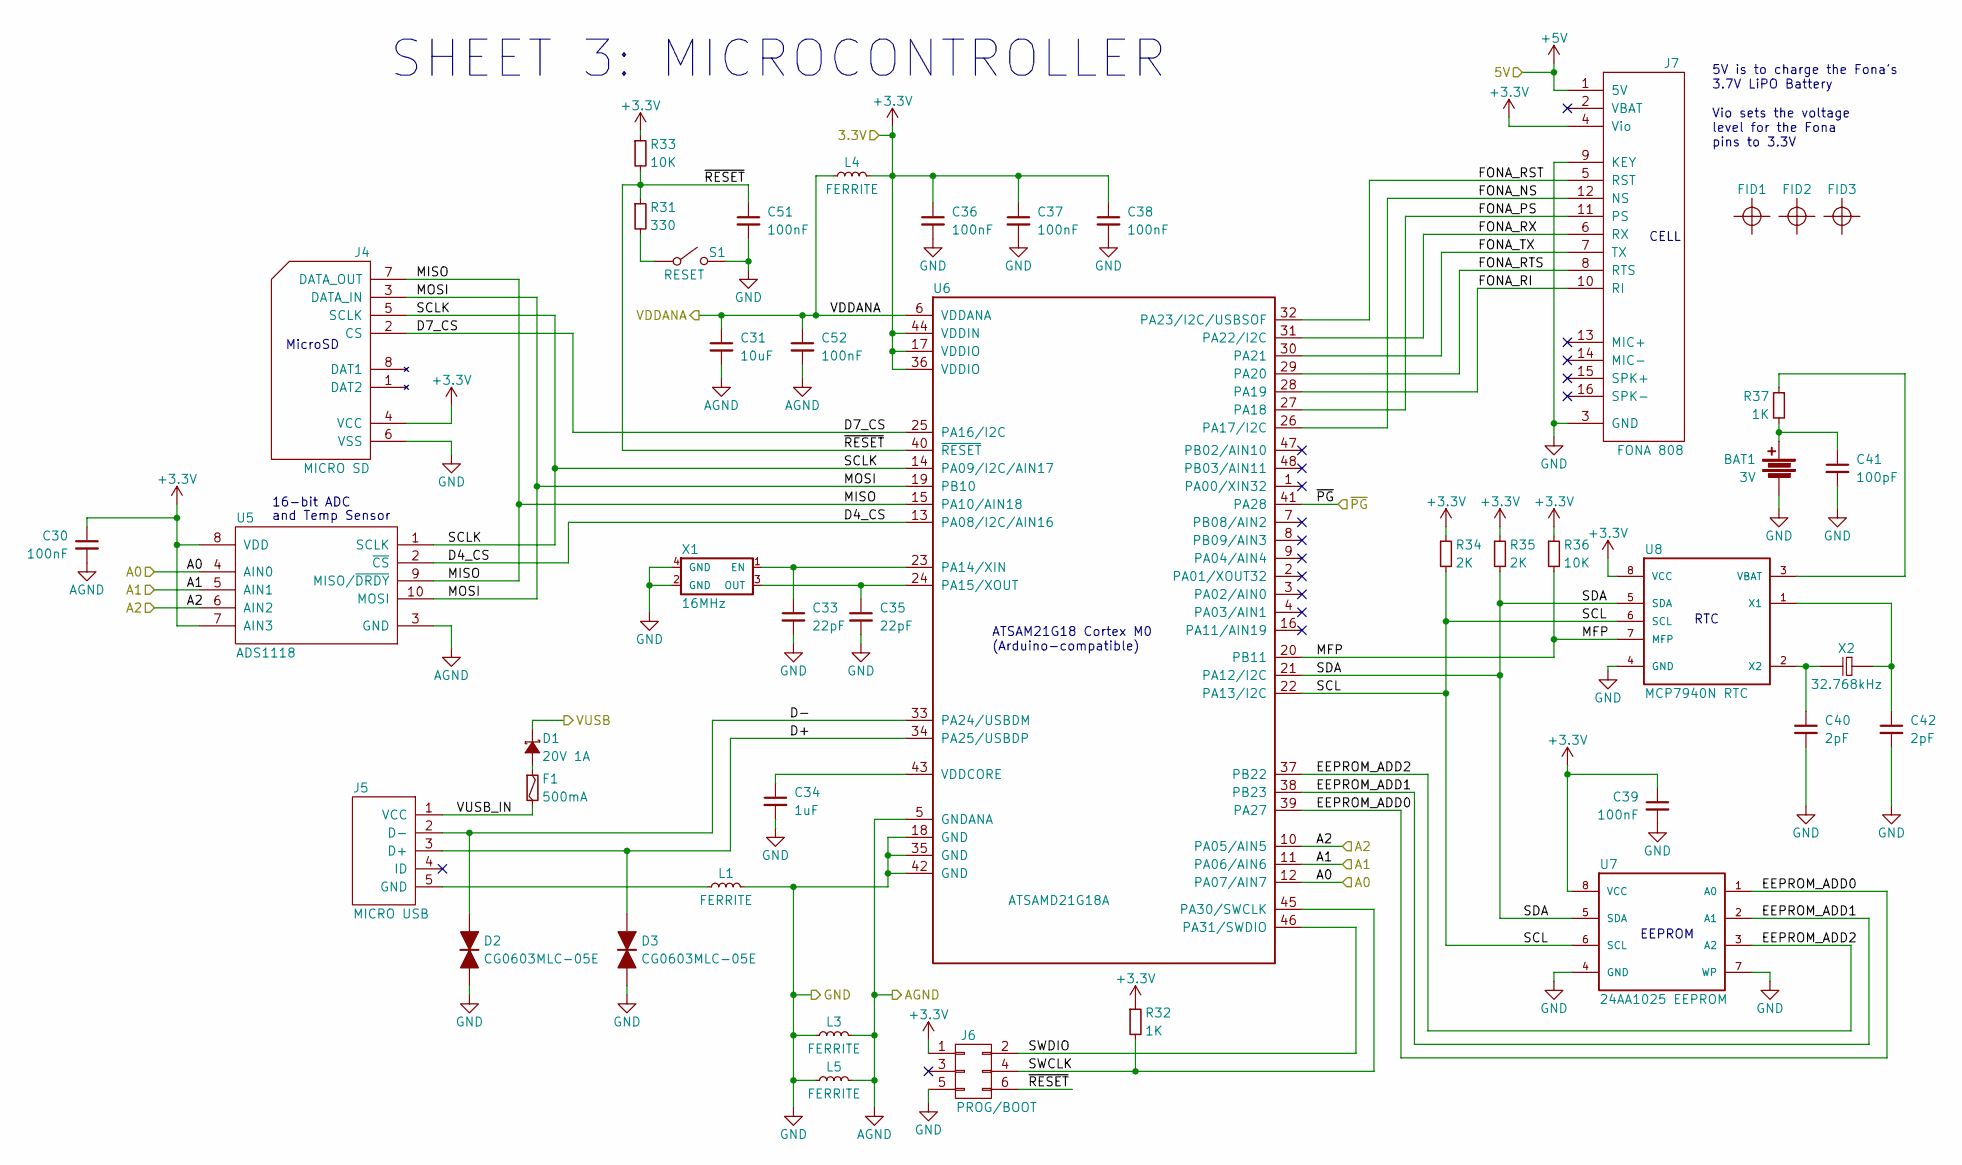
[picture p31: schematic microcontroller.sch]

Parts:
BAT1: 3V; BATT-HOLDER-CR1220-BK-916
C30, C36, C37, C38, C39, C51, C52: 100nF; RLC-0603-SMD
C31: 10uF; RLC-0805-SMD
C33, C35: 22pF; RLC-0603-SMD
C34: 1uF; RLC-0805-SMD
C40, C42: 2pF; RLC-0603-SMD
C41: 100pF; RLC-0603-SMD
D1: 20V 1A; DIODE-SMA
D2, D3: CG0603MLC-05E; RLC-0603-SMD
F1: 500mA; RLC-1812-SMD
FID1, FID2, FID3: FIDUCIAL; FIDUCIAL-2MM
J4: MICRO SD; CONN-SD-MICRO-MOLEX-0475710001
J5: MICRO USB; CONN-USB-MICRO-B-AMPHENOL-10118193-0001LF
J6: PROG/BOOT; CONN-HEADER-STRAIGHT-P2.54MM-2x03
J7: FONA 808; BREAKOUT-ADAFRUIT-FONA808-CELL-GPS
L1, L3, L4, L5: FERRITE; RLC-0805-SMD
R31: 330; RLC-0603-SMD
R32, R37: 1K; RLC-0603-SMD
R33, R36: 10K; RLC-0603-SMD
R34, R35: 2K; RLC-0603-SMD
S1: RESET; SWITCH-OMRON-MOMENTARY-SMD-B3U-1000P
U5: ADS1118; MSOP-10-3x3MM-P0.5MM
U6: ATSAMD21G18A; TQFP-48_7x7mm_Pitch0.5mm
U7: 24AA1025 EEPROM; SOIC-8-3.9x4.9MM-P1.27MM
U8: MCP7940N RTC; SOIC-8-3.9x4.9MM-P1.27MM
X1: 16MHz; CRYSTAL-CTS-4SMD
X2: 32.768kHz; CRYSTAL-HC49-TH

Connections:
+3V3: C30.1, C36.1, C37.1, C38.1, C39.1, J4.4 (VCC), J6.1, J7.4 (Vio), L4.2, R32.1, R33.1, R34.1, R35.1, R36.1, U5.7 (AIN3), U5.8 (VDD), U6.17 (VDDIO), U6.36 (VDDIO), U6.44 (VDDIN), U7.8 (VCC), U8.8 (VCC); also elsewhere on the board
+5V: J7.1 (5V); also elsewhere on the board
/A0: U5.4 (AIN0), U6.12 (PA07/AIN7); also elsewhere on the board
/A1: U5.5 (AIN1), U6.11 (PA06/AIN6); also elsewhere on the board
/A2: U5.6 (AIN2), U6.10 (PA05/AIN5); also elsewhere on the board
/Microcontroller/D4_CS: U5.2 (~CS), U6.13 (PA08/I2C/AIN16)
/Microcontroller/D7_CS: J4.2 (CS), U6.25 (PA16/I2C)
/Microcontroller/D+: D3.1, J5.3 (D+), U6.34 (PA25/USBDP)
/Microcontroller/D-: D2.1, J5.2 (D-), U6.33 (PA24/USBDM)
/Microcontroller/EEPROM_ADD0: U6.39 (PA27), U7.1 (A0)
/Microcontroller/EEPROM_ADD1: U6.38 (PB23), U7.2 (A1)
/Microcontroller/EEPROM_ADD2: U6.37 (PB22), U7.3 (A2)
/Microcontroller/FONA_NS: J7.12 (NS), U6.26 (PA17/I2C)
/Microcontroller/FONA_PS: J7.11 (PS), U6.27 (PA18)
/Microcontroller/FONA_RI: J7.10 (RI), U6.28 (PA19)
/Microcontroller/FONA_RST: J7.5 (RST), U6.32 (PA23/I2C/USBSOF)
/Microcontroller/FONA_RTS: J7.8 (RTS), U6.29 (PA20)
/Microcontroller/FONA_RX: J7.6 (RX), U6.31 (PA22/I2C)
/Microcontroller/FONA_TX: J7.7 (TX), U6.30 (PA21)
/Microcontroller/MFP: R36.2, U6.20 (PB11), U8.7 (MFP)
/Microcontroller/MISO: J4.7 (DATA_OUT), U5.9 (MISO/~DRDY), U6.15 (PA10/AIN18)
/Microcontroller/MOSI: J4.3 (DATA_IN), U5.10 (MOSI), U6.19 (PB10)
/Microcontroller/SCL: R34.2, U6.22 (PA13/I2C), U7.6 (SCL), U8.6 (SCL)
/Microcontroller/SCLK: J4.5 (SCLK), U5.1 (SCLK), U6.14 (PA09/I2C/AIN17)
/Microcontroller/SDA: R35.2, U6.21 (PA12/I2C), U7.5 (SDA), U8.5 (SDA)
/Microcontroller/SWCLK: J6.4, R32.2, U6.45 (PA30/SWCLK)
/Microcontroller/SWDIO: J6.2, U6.46 (PA31/SWDIO)
/Microcontroller/VUSB_IN: F1.2, J5.1 (VCC)
/Microcontroller/~RESET: C51.1, J6.6, R31.1, R33.2, U6.40 (~RESET)
/VDDANA: C31.1, C52.1, L4.1, U6.6 (VDDANA); also elsewhere on the board
/~PG: U6.41 (PA28); also elsewhere on the board
AGND: C30.2, C31.2, C52.2, L3.2, L5.2, U5.3 (GND), U6.5 (GNDANA); also elsewhere on the board
GND: BAT1.GND, C33.2, C34.2, C35.2, C36.2, C37.2, C38.2, C39.2, C40.2, C41.2, C42.2, C51.2, D2.2, D3.2, J4.6 (VSS), J6.5, J7.3 (GND), J7.9 (KEY), L1.2, L3.1, L5.1, S1.2, U6.18 (GND), U6.35 (GND), U6.42 (GND), U7.4 (GND), U7.7 (WP), U8.4 (GND), X1.2 (GND), X1.4 (GND); also elsewhere on the board
unnamed: BAT1.1, C41.1, R37.2
unnamed: C33.1, U6.23 (PA14/XIN), X1.1 (EN)
unnamed: C34.1, U6.43 (VDDCORE)
unnamed: C35.1, U6.24 (PA15/XOUT), X1.3 (OUT)
unnamed: C40.1, U8.2 (X2), X2.1
unnamed: C42.1, U8.1 (X1), X2.2
unnamed: D1.2 (A), F1.1
unnamed: J5.5 (GND), L1.1
unnamed: R31.2, S1.1
unnamed: R37.1, U8.3 (VBAT)
VUSB: D1.1 (K); also elsewhere on the board

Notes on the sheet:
RTC
EEPROM
CELL
ATSAM21G18 Cortex M0 (Arduino-compatible)
SHEET 3: MICROCONTROLLER
16-bit ADC
MicroSD
and Temp Sensor
5V is to charge the Fona's 3.7V LiPO Battery Vio sets the voltage level for the Fona pins to 3.3V

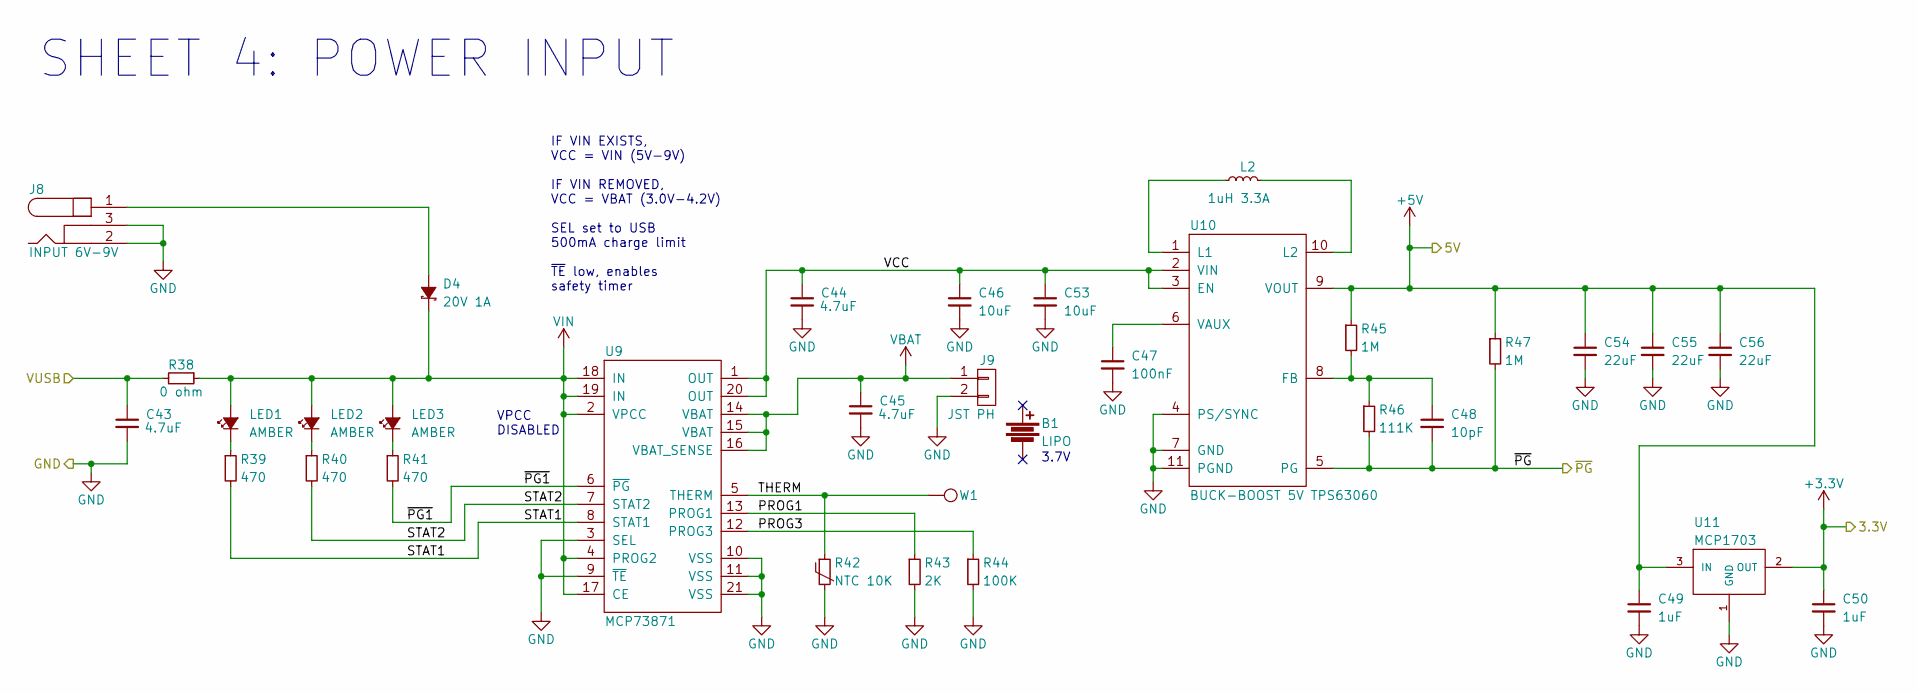
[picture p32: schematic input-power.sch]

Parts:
B1: LIPO
C43, C44, C45: 4.7uF; RLC-1206-SMD
C46, C53: 10uF; RLC-0805-SMD
C47: 100nF; RLC-0603-SMD
C48: 10pF; RLC-0603-SMD
C49, C50: 1uF; RLC-0805-SMD
C54, C55, C56: 22uF; RLC-1210-SMD
D4: 20V 1A; DIODE-SMA
J8: INPUT 6V-9V; CONN-BARREL-JACK-2.5x5.5MM-TH
J9: JST PH; CONN-JST-S2B-PH-SM4-TB
L2: 1uH 3.3A; 1226AS-H-1R0N
LED1, LED2, LED3: AMBER; LED-0603-SMD
R38: 0 ohm; RLC-0603-SMD
R39, R40, R41: 470; RLC-0603-SMD
R42: NTC 10K; RLC-0402-SMD
R43: 2K; RLC-0603-SMD
R44: 100K; RLC-0603-SMD
R45, R47: 1M; RLC-0603-SMD
R46: 111K; RLC-0603-SMD
U9: MCP73871; QFN-20-1EP-4x4MM_P0.5MM
U10: BUCK-BOOST 5V TPS63060; WSON-10-1EP
U11: MCP1703; SOT-23-3
W1: TEST_1P; HOLE-PLATED-40MIL

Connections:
+3V3: C50.1, U11.2 (OUT); also elsewhere on the board
+5V: C49.1, C54.1, C55.1, C56.1, R45.1, R47.1, U10.9 (VOUT), U11.3 (IN); also elsewhere on the board
/Input Power/PROG1: R43.1, U9.13 (PROG1)
/Input Power/PROG3: R44.1, U9.12 (PROG3)
/Input Power/STAT1: R39.2, U9.8 (STAT1)
/Input Power/STAT2: R40.2, U9.7 (STAT2)
/Input Power/THERM: R42.1, U9.5 (THERM), W1.1
/Input Power/VCC: C44.1, C46.1, C53.1, U9.1 (OUT), U9.20 (OUT), U10.2 (VIN), U10.3 (EN)
/Input Power/~PG1: R41.2, U9.6 (~PG)
/~PG: C48.2, R46.2, R47.2, U10.5 (PG); also elsewhere on the board
GND: C43.2, C44.2, C45.2, C46.2, C47.2, C49.2, C50.2, C53.2, C54.2, C55.2, C56.2, J8.2, J8.3, J9.2, R42.2, R43.2, R44.2, U9.3 (SEL), U9.9 (~TE), U9.10 (VSS), U9.11 (VSS), U9.21 (VSS), U10.4 (PS/SYNC), U10.7 (GND), U10.11 (PGND), U11.1 (GND); also elsewhere on the board
unnamed: C47.1, U10.6 (VAUX)
unnamed: C48.1, R45.2, R46.1, U10.8 (FB)
unnamed: D4.2 (A), J8.1
unnamed: L2.1, U10.1 (L1)
unnamed: L2.2, U10.10 (L2)
unnamed: LED1.1 (K), R39.1
unnamed: LED2.1 (K), R40.1
unnamed: LED3.1 (K), R41.1
VBAT: C45.1, J9.1, U9.14 (VBAT), U9.15 (VBAT), U9.16 (VBAT_SENSE)
VIN: D4.1 (K), LED1.2 (A), LED2.2 (A), LED3.2 (A), R38.1, U9.2 (VPCC), U9.4 (PROG2), U9.17 (CE), U9.18 (IN), U9.19 (IN)
VUSB: C43.1, R38.2; also elsewhere on the board

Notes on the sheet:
VPCC DISABLED
IF VIN EXISTS, VCC = VIN (5V-9V) IF VIN REMOVED, VCC = VBAT (3.0V-4.2V) SEL set to USB 500mA charge limit ~TE~ low, enables safety timer
3.7V
SHEET 4: POWER INPUT

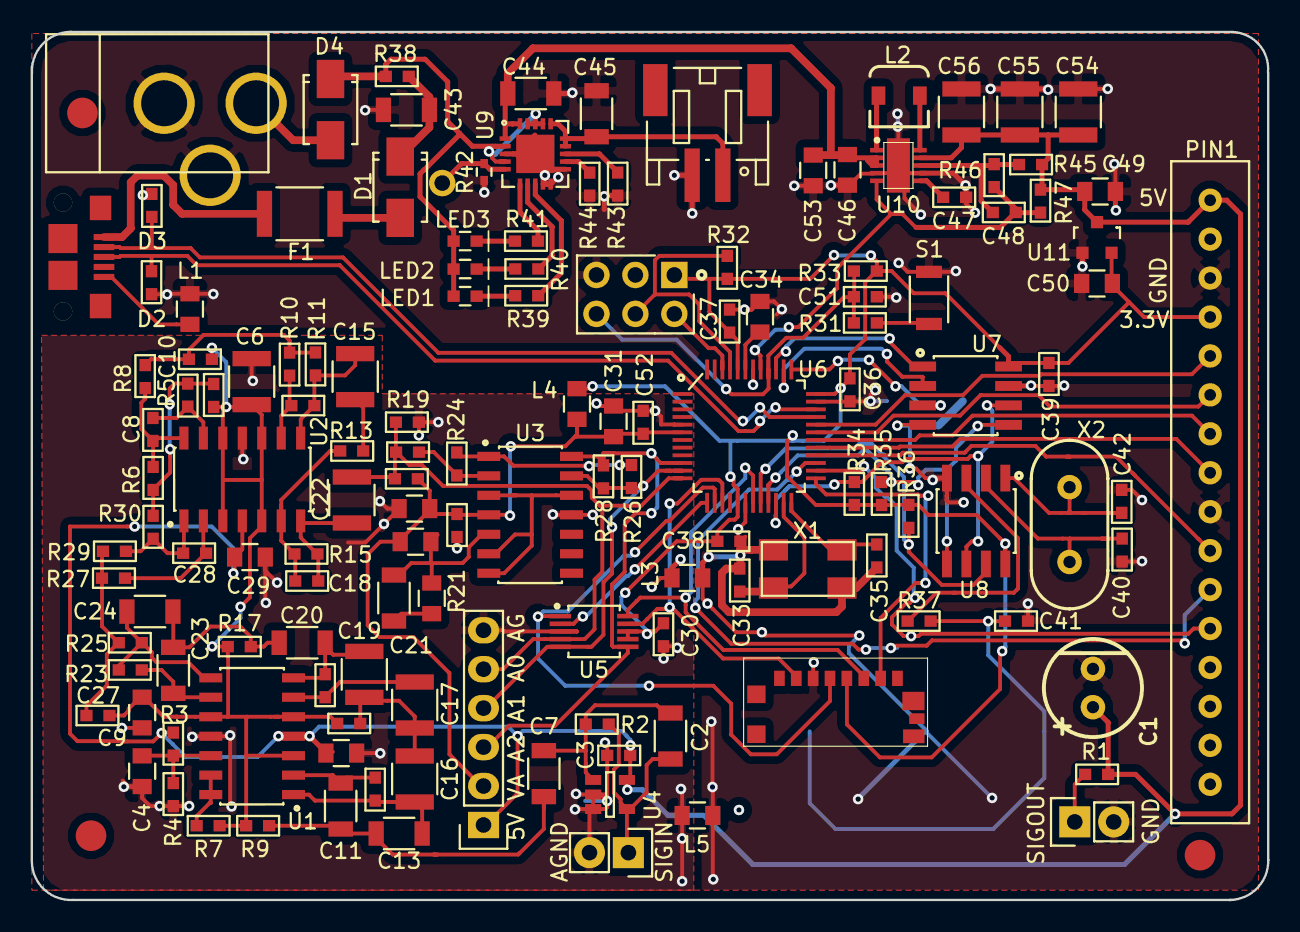
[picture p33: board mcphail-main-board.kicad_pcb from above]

Board: 2 copper layers, 80.6 x 56.6 mm, 143 parts (1 on the bottom side), 93 nets.

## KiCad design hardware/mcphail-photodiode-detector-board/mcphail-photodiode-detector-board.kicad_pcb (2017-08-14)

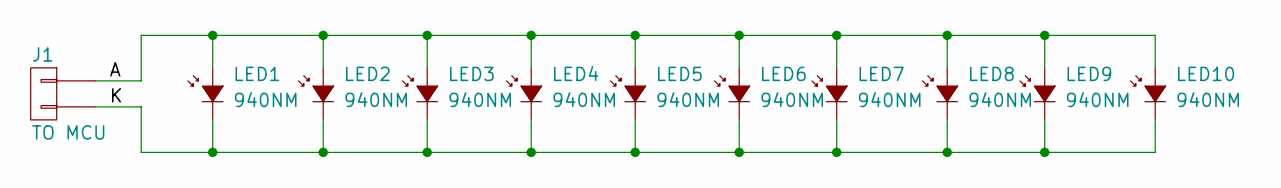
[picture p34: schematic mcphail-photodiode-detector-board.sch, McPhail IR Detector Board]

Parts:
J1: TO MCU; CONN-HEADER-STRAIGHT-P2.54MM-1x02
LED1, LED2, LED3, LED4, LED5, LED6, LED7, LED8, LED9, LED10: 940NM; TEMD5110X01

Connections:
/A: J1.1, LED1.2, LED2.2, LED3.2, LED4.2, LED5.2, LED6.2, LED7.2, LED8.2, LED9.2, LED10.2
/K: J1.2, LED1.1, LED2.1, LED3.1, LED4.1, LED5.1, LED6.1, LED7.1, LED8.1, LED9.1, LED10.1

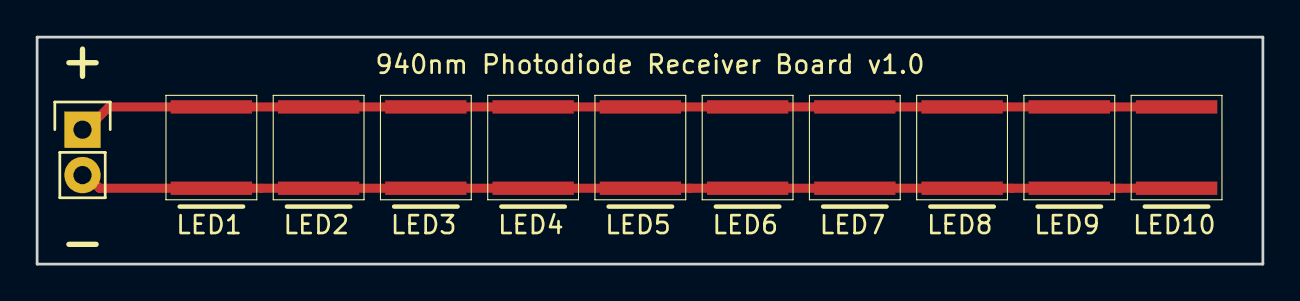
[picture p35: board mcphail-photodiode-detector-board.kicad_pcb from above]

Board: 2 copper layers, 68.6 x 12.7 mm, 11 parts (0 on the bottom side), 2 nets.

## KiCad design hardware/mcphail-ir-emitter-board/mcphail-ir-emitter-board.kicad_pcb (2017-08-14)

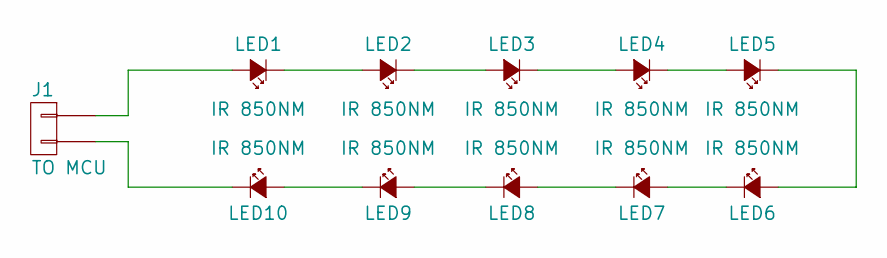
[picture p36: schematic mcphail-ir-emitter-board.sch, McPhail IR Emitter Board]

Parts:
J1: TO MCU; CONN-HEADER-STRAIGHT-P2.54MM-1x02
LED1, LED2, LED3, LED4, LED5, LED6, LED7, LED8, LED9, LED10: IR 850NM; LED-D5MM-2PIN-SH4356

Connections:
unnamed: J1.1, LED1.2
unnamed: J1.2, LED10.1
unnamed: LED1.1, LED2.2
unnamed: LED2.1, LED3.2
unnamed: LED3.1, LED4.2
unnamed: LED4.1, LED5.2
unnamed: LED5.1, LED6.2
unnamed: LED6.1, LED7.2
unnamed: LED7.1, LED8.2
unnamed: LED8.1, LED9.2
unnamed: LED9.1, LED10.2

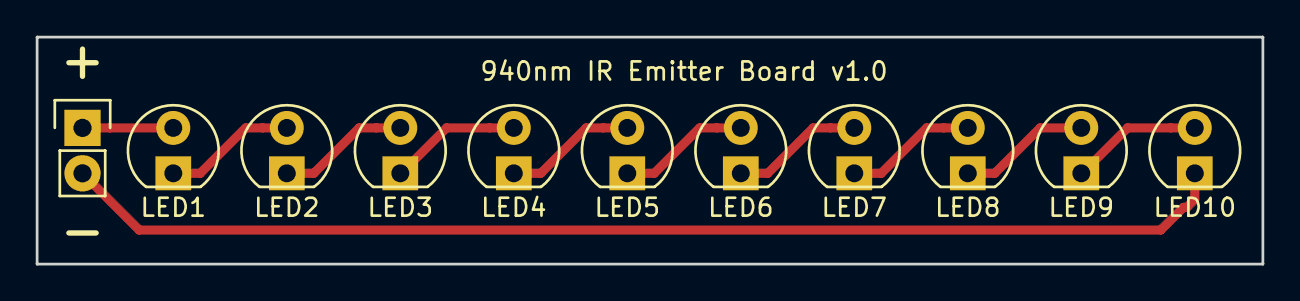
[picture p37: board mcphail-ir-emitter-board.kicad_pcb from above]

Board: 2 copper layers, 68.6 x 12.7 mm, 11 parts (0 on the bottom side), 11 nets.

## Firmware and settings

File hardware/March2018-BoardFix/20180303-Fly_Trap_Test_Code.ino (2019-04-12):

//
// Name:        20180303-Fly_Trap_Test
// Date:        2018.03.03
// Author:      Jared Rees
// Description: Test code to debug fly trap shield (McPhail Analog Shield v1.0). 
// Notes:       I'm using a delay to time reads. A timer interrupt would be better,
//                but I went this route for brevity.
//

#include <stdio.h>

// If true, only read from A0 (read time of about 430 microseconds).
// If false, read from A0, A1, and A2 (read time of about 1272 microseconds)
bool quickmode = true;

// Constants
const int TIME_BETWEEN_READS = quickmode?500:2000;       // time between reads (in microseconds)
const int NUMBER_OF_READS = 1000;                         // number of reads to take
const int AVERAGE_EXECUTION_TIME = quickmode?430:1272;    // found experimentally (in microseconds)

// Arrays to store time and ADC values
unsigned long timeVals[NUMBER_OF_READS];    // Time values
int a0Vals[NUMBER_OF_READS];                // ADC port A0 read values
int a1Vals[NUMBER_OF_READS];                // ADC port A1 read values
int a2Vals[NUMBER_OF_READS];                // ADC port A2 read values

bool alreadyCycled = false;                 // flag used for main loop
char *outputString;                         // char pointer used for serial port output

void setup() {
  // Set-up the serial port.
  Serial.begin(9600);

  // Initialize arrays.
  int i = 0;
  for (i=0; i<NUMBER_OF_READS; i++){
    timeVals[i] = 0;
    a0Vals[i] = 0;
    a1Vals[i] = 0;
    a2Vals[i] = 0;
  }
}

void loop() {
  // Make sure the constants are valid.
  if (TIME_BETWEEN_READS - AVERAGE_EXECUTION_TIME <= 0 && alreadyCycled == false)
    Serial.print("TIME_BETWEEN_READS needs to be greater than AVERAGE_EXECUTION_TIME.\n");
    
  // If the constants are valid and this code hasn't executed yet...
  else if (alreadyCycled == false){
    // Read and store values with the proper delay time between reads.
    int i = 0;
    for (i=0; i<NUMBER_OF_READS; i++){
      timeVals[i] = micros();
      a0Vals[i] = analogRead(0);
      if (!quickmode){
        a1Vals[i] = analogRead(1);
        a2Vals[i] = analogRead(2);
      }
      delayMicroseconds(TIME_BETWEEN_READS - AVERAGE_EXECUTION_TIME);
    }

    // Print all data to the serial port. 
    // ** Tab separated for easy spreadsheet import. **
    //
    // Print header info.
    if (quickmode)
      Serial.print("Sample #\tRun Time (in microseconds)\tADC0\n");
    else
      Serial.print("Sample #\tRun Time (in microseconds)\tADC0\tADC1\tADC2\n");
    // Print all the data.
    for (i=0; i<NUMBER_OF_READS; i++){
      if (quickmode)
        asprintf(&outputString, "%d\t%d\t%d\n", i, timeVals[i], a0Vals[i]);
      else
        asprintf(&outputString, "%d\t%d\t%d\t%d\t%d\n", i, timeVals[i], a0Vals[i], a1Vals[i], a2Vals[i]);
      Serial.print(outputString);
      free(outputString);
    }

    // Make the flag true so execution ends.
    alreadyCycled = true;
  }
}

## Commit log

2017-07-20 Add Main Board started (photo conditioning).
    [input-power.sch, mcphail-main-board.kicad_pcb, mcphail-main-board.sch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]
2017-07-25 Release main board sch with BOM and layout estimates.
    [input-power.sch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]
2017-07-25 Updated README to include hardware design notes.
    [mcphail-photodiode-emitter.kicad_pcb]
2017-07-25 Added another option for more ADC bits with Atmega32u4.
2017-07-27 Added ADS1118 (ADC with temp sensor) to Atmega32u4.
    [input-power.sch, microcontroller.sch, signal-conditioning.sch]
2017-07-27 Switched all to 3.3V, things got simple, cheaper.
    [microcontroller.sch]
2017-07-27 Hooked up pins to ATSAMD21G18 Cortex M0, fixed AGND throughout.
    [input-power.sch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]
2017-07-27 Regenerated schematic PDF.
2017-07-30 Fixed the sigcond sch, VREF now correct.
    [signal-conditioning.sch]
2017-07-30 All footprints good. Changed op amps slightly for footprints.
    [input-power.sch, mcphail-main-board.kicad_pcb, mcphail-main-board.sch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]
2017-07-30 Basic parts grouping done.
    [mcphail-main-board.kicad_pcb]
2017-07-30 Sch passes rule check. Final netlist. Starting layout.
    [input-power.sch, mcphail-main-board.kicad_pcb, mcphail-main-board.sch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]
2017-07-30 Add files via upload
    Wingbeat frequencies from Table 1 in Byrne Buchmann & Spangler (1988)
2017-07-30 Update README.md
    Insect wingbeat table taken from Byrne, Buchmann & Spangler paper
2017-07-30 Add files via upload
    Insect wingbeat frequencies paper
2017-08-06 Removed emitter board project.
    [mcphail-photodiode-emitter.kicad_pcb, mcphail-photodiode-emitter.sch]
2017-08-06 Lots more layout work, needs rework.
    [input-power.sch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]
2017-08-06 Create emitter schematic.
    [mcphail-ir-emitter-board.kicad_pcb, mcphail-ir-emitter-board.sch]
2017-08-06 Add receiver schematic.
    [mcphail-photodiode-detector-board.kicad_pcb, mcphail-photodiode-detector-board.sch]
2017-08-06 Release v1.0 Mcphail IR 940nm Emitter Board.
    [mcphail-ir-emitter-board.kicad_pcb, mcphail-ir-emitter-board.sch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]
2017-08-06 Release v1.0 Mcphail IR 940nm Detector Board.
    [mcphail-ir-emitter-board-B.Cu.gbl, mcphail-ir-emitter-board-B.Mask.gbs, mcphail-ir-emitter-board-B.Paste.gbp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]
2017-08-06 Saving main board layout before major rework.
    [mcphail-main-board.kicad_pcb, microcontroller.sch]
2017-08-06 Regenerated sch pdf. Converted to 4 layer.
    [mcphail-main-board-B.Cu.gbl, mcphail-main-board-B.Mask.gbs, mcphail-main-board-B.Paste.gbp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]
2017-08-06 Reworking main board, power rails routed next.
    [input-power.sch, mcphail-main-board.kicad_pcb, mcphail-main-board.sch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]
2017-08-06 Regenerated BOMs. Added links to README.
    [mcphail-ir-emitter-board-v1.0-bom-digikey.csv, mcphail-ir-emitter-board-v1.0-bom-master.csv, mcphail-ir-emitter-board-v1.0-bom-mouser.csv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]
2017-08-09 Generate Main Board with traces done. Needs silk.
    [mcphail-main-board-B.Cu.gbl, mcphail-main-board-B.Mask.gbs, mcphail-main-board-B.Paste.gbp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]
2017-08-09 Major updates to README.
    [mcphail-main-board.kicad_pcb]
2017-08-12 Release v1.0 McPhail Main Board
    [input-power.sch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]
2017-08-14 Release v1.0 McPhail IR Emitter Board
    [mcphail-ir-emitter-board-B.Cu.gbl, mcphail-ir-emitter-board-B.Mask.gbs, mcphail-ir-emitter-board-B.Paste.gbp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]
2017-08-14 Release v1.0 McPhail Photodiode Detector Board
    [mcphail-photodiode-detector-board-B.Cu.gbl, mcphail-photodiode-detector-board-B.Mask.gbs, mcphail-photodiode-detector-board-B.Paste.gbp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]
2017-08-14 Automating more of the documentation.
    [mcphail-main-board-B.Cu.gbl, mcphail-main-board-B.Mask.gbs, mcphail-main-board-B.Paste.gbp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]
2017-08-24 Added pin list.
2017-09-24 Fixed clearance issues on McPhail Main v1.1
    [input-power.sch, mcphail-main-board.kicad_pcb]
2017-09-27 Fix DRC errors, regenerate gerbers. Order boards.
    [mcphail-main-board-B.Cu.gbl, mcphail-main-board-B.Mask.gbs, mcphail-main-board-B.Paste.gbp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]
2017-10-03 Add schematic. Add layout - needs modified.
    [mcphail-zero-analog-shield.kicad_pcb, mcphail-zero-analog-shield.sch]
2017-10-03 Schematic ref des seems okay.
    [mcphail-zero-analog-shield.sch]
2017-10-03 Only comps we need left on board. Needs routed.
    [mcphail-zero-analog-shield.kicad_pcb, mcphail-zero-analog-shield.sch]
2017-10-03 Parts on board with no traces, clean. Ready to layout.
    [mcphail-zero-analog-shield.kicad_pcb, mcphail-zero-analog-shield.sch]
2017-10-03 Starting layout.
    [mcphail-zero-analog-shield.kicad_pcb]
2017-10-03 More placement.
    [mcphail-zero-analog-shield.kicad_pcb]
2017-10-03 Re-import netlist, override existing.
    [mcphail-zero-analog-shield.kicad_pcb, mcphail-zero-analog-shield.sch]
2017-10-04 Arduino Zero Shield v1.0 layout done.
    [mcphail-zero-analog-shield.kicad_pcb, mcphail-zero-analog-shield.sch]
2017-10-05 Zero shield v1.0 ready to order.
    [mcphail-zero-analog-shield-B.Cu.gbl, mcphail-zero-analog-shield-B.Mask.gbs, mcphail-zero-analog-shield-B.Paste.gbp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]
2018-02-09 Add datasheet. Fix footprint.
    [mcphail-zero-analog-shield.kicad_pcb, mcphail-zero-analog-shield.sch]
2019-04-12 Project report by Jared Rees
    [20180303-McPhail_Zero_Analog_Shield_Test_Data.xlsx]

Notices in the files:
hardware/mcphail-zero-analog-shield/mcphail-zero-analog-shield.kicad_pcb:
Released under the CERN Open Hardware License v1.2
